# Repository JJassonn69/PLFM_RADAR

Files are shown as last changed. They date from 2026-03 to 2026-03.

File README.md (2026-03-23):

# AERIS-10: Open Source Pulse Linear Frequency Modulated Phased Array Radar




)


AERIS-10 Radar System

AERIS-10 is an open-source, low-cost 10.5 GHz phased array radar system featuring Pulse Linear Frequency Modulated (LFM) modulation. Available in two versions (3km and 20km range), it's designed for researchers, drone developers, and serious SDR enthusiasts who want to explore and experiment with phased array radar technology.

AERIS-10 Radar System

## 📡 Overview

The AERIS-10 project aims to democratize radar technology by providing a fully open-source, modular, and hackable radar system. Whether you're a university researcher, a drone startup, or an advanced maker, AERIS-10 offers a platform for experimenting with beamforming, pulse compression, Doppler processing, and target tracking.

## 🔬 Key Features

- **Open Source Hardware & Software** - Complete schematics, PCB layouts, firmware, and software available
- **Dual Version Availability**:
  - **AERIS-10N (Nexus)**: 3km range with 8x16 patch antenna array
  - **AERIS-10E (Extended)**: 20km range with 32x16 dielectric-filled slotted waveguide array
- **Full Electronic Beam Steering** - ±45° electronic steering in elevation and azimuth
- **Advanced Signal Processing** - On-board FPGA handles pulse compression, Doppler FFT, MTI, and CFAR
- **Python GUI** - User-friendly interface with map integration
- **GPS/IMU Integration** - Real-time position and attitude correction
- **Modular Design** - Separate power management, frequency synthesis, and RF boards

## 🏗️ System Architecture

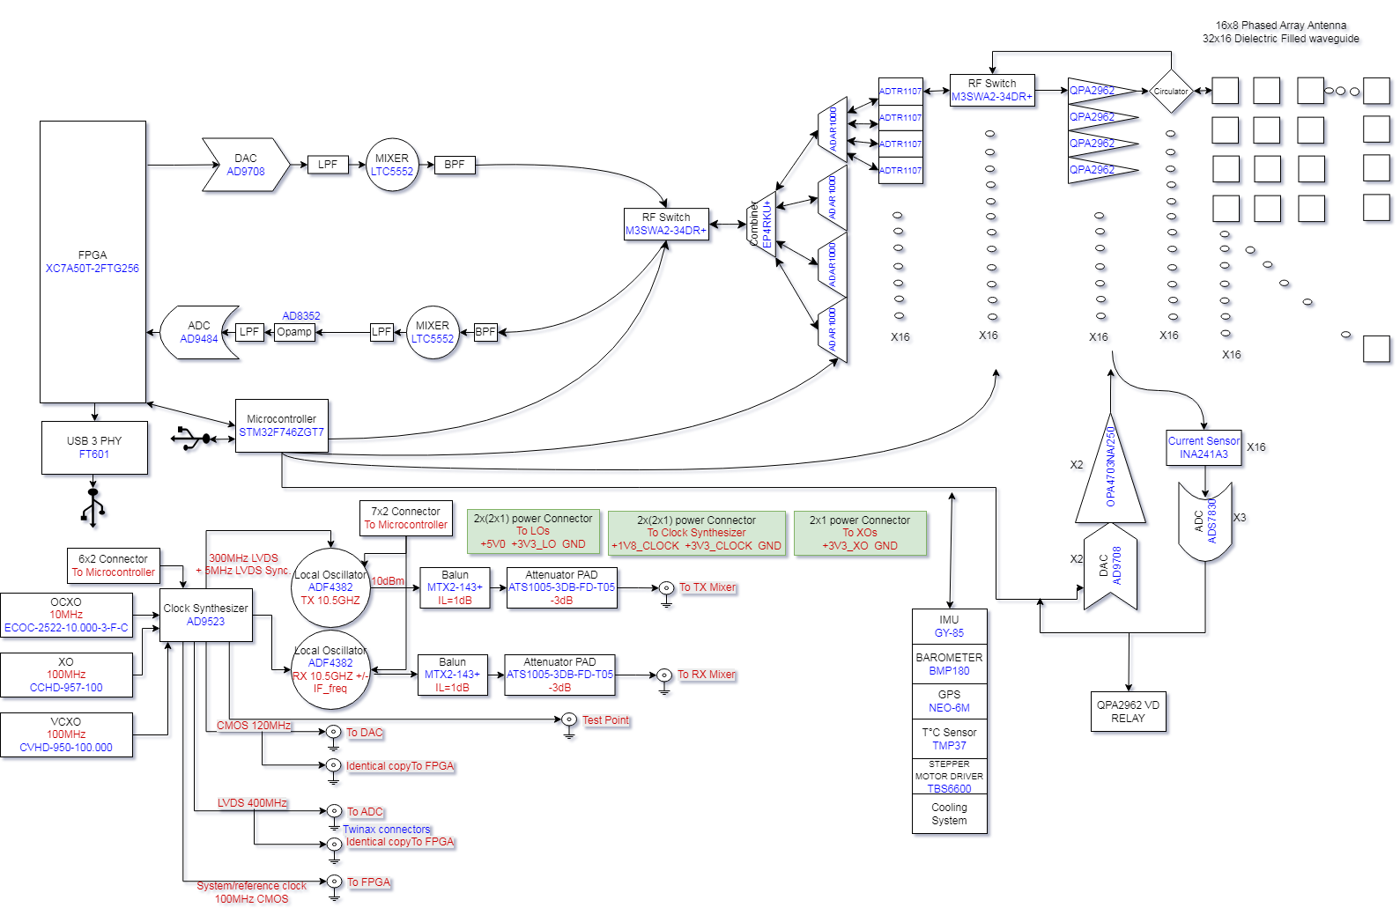
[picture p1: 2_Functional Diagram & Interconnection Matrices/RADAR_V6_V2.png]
AERIS-10 Radar System


### Hardware Components

The AERIS-10 main sub-systems are:

- **Power Management Board** - Supplies all necessary voltage levels to the electronics components with proper filtering and sequencing (sequencing ensured by the microcontroller)

- **Frequency Synthesizer Board** - Uses a high-performance Low Jitter Clock Generator (AD9523-1) that supplies phase-aligned clock references for:
  - RX and TX Frequency Synthesizers (ADF4382)
  - DAC
  - ADC
  - FPGA

- **Main Board** containing:
  - **DAC** - Generates the RADAR Chirps
  - **2x Microwave Mixers (LT5552)** - For up-conversion and IF-down-conversion
  - **4x 4-Channel Phase Shifters (ADAR1000)** - For RX and TX chain beamforming
  - **16x Front End Chips (ADTR1107)** - Used for both Low Noise Amplifying (RX) and Power Amplifying (TX) stages
  - **XC7A100T FPGA** - Handles RADAR Signal Processing:
    - PLFM Chirps generation via the DAC
    - Raw ADC data read
    - Automatic Gain Control (AGC)
    - I/Q Baseband Down-Conversion
    - Decimation
    - Filtering
    - Forward FFT
    - Pulse Compression
    - Doppler, MTI and CFAR processing
    - USB Interface
  - **STM32F746xx Microcontroller** - Used for:
    - Power-up and power-down sequencing (see Power Management Excel File)
    - FPGA communication
    - Setup and Interface with:
      - Clock Generator (AD9523-1)
      - 2x Frequency Synthesizers (ADF4382)
      - 4x 4-Channel Phase Shifters (ADAR1000) for RADAR pulse sequencing
      - 2x ADS7830 ADCs (on Power Amplifier Boards) for Idq measurement
      - 2x DAC5578 (on Power Amplifier Boards) for Vg control
      - GPS module for GUI map centering
      - GY-85 IMU for pitch/roll correction of target coordinates
      - BMP180 Barometer
      - Stepper Motor
      - 8x ADS7830 Temperature Sensors for cooling fan control
      - RF switches

- **16x Power Amplifier Boards** - Used only for AERIS-10E version, featuring 10Watt QPA2962 GaN amplifier for extended range

- **Antenna Arrays**:
  - **AERIS-10N (Nexus)** - 8x16 patch antenna array
  - **AERIS-10X (Extended)** - 32x16 dielectric-filled slotted waveguide antenna array

- **Miscellaneous Components**:
  - Slip-Ring
  - Stepper Motor and drivers
  - Cooling Fans
  - Enclosure) 

### Processing Pipeline

1. **Waveform Generation** - DAC creates LFM chirps
2. **Up/Down Conversion** - LT5552 mixers handle frequency translation
3. **Beam Steering** - ADAR1000 phase shifters control 16 elements
4. **Signal Processing (FPGA)**:
   - Raw ADC data capture
   - I/Q baseband down-conversion
   - Decimation & filtering (CIC/FIR)
   - Pulse compression
   - Doppler FFT processing
   - MTI & CFAR detection
5. **System Management (STM32)**:
   - Power sequencing
   - Peripheral configuration
   - GPS/IMU integration
   - Stepper motor control
6. **Visualization (Python GUI)**:
   - Real-time target plotting
   - Map integration
   - Radar control interface

AERIS-10 Radar System

## 📊 Technical Specifications

| Parameter | AERIS-10N (Nexus) | AERIS-10X (Extended) |
|---|---|---|
| **Frequency** | 10.5 GHz | 10.5 GHz |
| **Max Range** | 3 km | 20 km |
| **Antenna** | 8x16 Patch Array | 32x16 Slotted Waveguide |
| **Beam Steering** | Electronic (±45°) | Electronic (±45°) |
| **Mechanical Scan** | 360° (stepper motor) | 360° (stepper motor) |
| **Output Power** | ~1Wx16 | 10Wx16 (GaN amplifier) |
| **Processing** | FPGA + STM32 | FPGA + STM32 |

## 🚀 Getting Started

## 🧹 Repository File Placement Policy

To keep the repository root clean and make artifacts easy to find, place generated files in the following locations:

- **Published reports (tracked, GitHub Pages):** `docs/`
  - Example: `docs/AERIS_Simulation_Report_v2.pdf`
- **Simulation-generated outputs (local, gitignored):** `5_Simulations/generated/`
  - Plots, scenario outputs, temporary analysis directories
- **FPGA/Vivado generated artifacts (local, gitignored):** `9_Firmware/9_2_FPGA/reports/`
  - VCD/VVP dumps, temporary CSVs, local report snapshots
- **Reusable FPGA automation scripts (tracked):** `9_Firmware/9_2_FPGA/scripts/`
  - TCL flows, helper scripts used by build/bring-up

Do not leave generated artifacts in the repository root.

### Prerequisites

- Basic understanding of radar principles
- Experience with PCB assembly (for hardware build)
- Python 3.8+ for the GUI software
- FPGA development tools (Vivado) for signal processing modifications

### Hardware Assembly

1. **Order PCBs**: All Gerber files are available in `/4_Schematics and Boards Layout`
2. **Source Components**: Bill of materials (BOM) in `/4_Schematics and Boards Layout/4_7_Production Files`
3. **Assembly**: Follow the assembly guide in `/10_docs/assembly_guide.md`
4. **Antenna**: Choose appropriate array for your version
5. **Enclosure**: 3D printable files in `/10_docs/Hardware/Enclosure`

## 📜 License

This project is open-source but uses **different licenses for hardware and software** to ensure proper legal coverage.

### Hardware Documentation
The hardware design files—including:
- Schematics and PCB layouts (in `/4_Schematics and Boards Layout`)
- Bill of Materials (BOM) files
- Gerber files and manufacturing outputs
- Mechanical drawings and enclosure designs

are licensed under the **CERN Open Hardware Licence Version 2 – Permissive (CERN-OHL-P)** .

This is a hardware-specific license that:
- ✅ Clearly defines "Hardware," "Documentation," and "Products"
- ✅ Includes explicit patent protection for contributors and users
- ✅ Provides stronger liability limitations (important for high-power RF)
- ✅ Aligns with professional open-hardware standards (CERN, OSHWA)

You may use, modify, and sell products based on these designs, provided you:
- Maintain the original copyright notices
- Distribute any modified designs under the same license
- Make your modifications available in Source format

### Software and Firmware
The software components—including:
- FPGA code (VHDL/Verilog in `/9_Firmware`)
- Microcontroller firmware (STM32)
- Python GUI and utilities

remain under the **MIT License** for maximum flexibility.

### Full License Texts
- The complete CERN-OHL-P license text is in the `LICENSE` file
- MIT license terms apply to software where not otherwise specified

### Why This Change?
Originally, the entire project used the MIT license. The community (special thanks to gmaynez!) pointed out that MIT lacks legal protections needed for physical hardware. The switch to CERN-OHL-P ensures the project is properly protected while maintaining the same permissive spirit.

## Contact & Collaboration
I welcome serious inquiries from researchers, engineers, and potential collaborators. However, due to the high volume of interest in this project, please understand that I cannot guarantee a response to every message.

For technical questions or bug reports: Please open a GitHub issue so the whole community can benefit from the discussion.

For collaboration, licensing, or business inquiries:
📧 nawfal.motii.33 [at] gmail [dot] com

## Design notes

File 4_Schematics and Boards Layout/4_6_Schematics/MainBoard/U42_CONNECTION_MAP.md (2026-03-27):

# U42 FPGA Connection Map — XC7A200T-2FBG484I

> **MainBoard FPGA swap reference**
> Schematic: `RADAR_Main_Board_2.kicad_sch` (Digital sheet)
> PCB: `RADAR_Main_Board.kicad_pcb`

---

## STATUS SUMMARY

| Category | Count | Status |
|---|---|---|
| Signal nets (I/O) | 77 | All connected in schematic via wire+label |
| Power pins (VCCINT/VCCBRAM/VCCAUX/VCCO/GND) | 143 | All connected in schematic via global_label |
| Unexpected extra nets found | 6 | Need review (see Section 6) |
| PCB traces routed | 0 of 77 | **All old traces deleted — needs full re-route** |

---

## 1. BANK 14 I/O — Unit 1 (27 signals)

Unit 1 is placed at schematic position **(200, 450)**. All pins exit to the **right** (pin angle 180°, meaning pin stub points left, wire goes right from symbol edge).

| # | Net Name | New Ball | Pin Function | Connects To | LVDS? |
|---|---|---|---|---|---|
| 1 | `ADC_D0_N` | V22 | IO_L3N_T0_DQS_EMCCLK_14 | U1 (AD9484) pin | N pair |
| 2 | `ADC_D0_P` | T21 | IO_L4P_T0_D04_14 | U1 (AD9484) pin | P pair |
| 3 | `ADC_D1_N` | R21 | IO_L2N_T0_D03_14 | U1 (AD9484) pin | N pair |
| 4 | `ADC_D1_P` | U22 | IO_L3P_T0_DQS_PUDC_B_14 | U1 (AD9484) pin | P pair |
| 5 | `ADC_D2_N` | R22 | IO_L1N_T0_D01_DIN_14 | U1 (AD9484) pin | N pair |
| 6 | `ADC_D2_P` | P21 | IO_L2P_T0_D02_14 | U1 (AD9484) pin | P pair |
| 7 | `ADC_D3_N` | T18 | IO_L20N_T3_A07_D23_14 | U1 (AD9484) pin | N pair |
| 8 | `ADC_D3_P` | N17 | IO_L21P_T3_DQS_14 | U1 (AD9484) pin | P pair |
| 9 | `ADC_D4_N` | R14 | IO_L19N_T3_A09_D25_VREF_14 | U1 (AD9484) pin | N pair |
| 10 | `ADC_D4_P` | R18 | IO_L20P_T3_A08_D24_14 | U1 (AD9484) pin | P pair |
| 11 | `ADC_D5_N` | V19 | IO_L14N_T2_SRCC_14 | U1 (AD9484) pin | N pair |
| 12 | `ADC_D5_P` | AA19 | IO_L15P_T2_DQS_RDWR_B_14 | U1 (AD9484) pin | P pair |
| 13 | `ADC_D6_N` | AB20 | IO_L15N_T2_DQS_DOUT_CSO_B_14 | U1 (AD9484) pin | N pair |
| 14 | `ADC_D6_P` | V17 | IO_L16P_T2_CSI_B_14 | U1 (AD9484) pin | P pair |
| 15 | `ADC_D7_P` | Y18 | IO_L13P_T2_MRCC_14 | U1 (AD9484) pin | single |
| 16 | `ADC_OR_N` | AB18 | IO_L17N_T2_A13_D29_14 | U1 (AD9484) overrange | N pair |
| 17 | `ADC_OR_P` | U17 | IO_L18P_T2_A12_D28_14 | U1 (AD9484) overrange | P pair |
| 18 | `ADC_PWRD` | Y19 | IO_L13N_T2_MRCC_14 | U1 (AD9484) power down | single |
| 19 | `FPGA_ADC_CLOCK_N` | N14 | IO_L23N_T3_A02_D18_14 | ADC data clock | N pair |
| 20 | `FPGA_ADC_CLOCK_P` | P16 | IO_L24P_T3_A01_D17_14 | ADC data clock | P pair |
| 21 | `FPGA_FLASH_DQ0` | U20 | IO_L11P_T1_SRCC_14 | U9 (MT25QL) DQ0 | single |
| 22 | `FPGA_FLASH_DQ1` | AB22 | IO_L10N_T1_D15_14 | U9 (MT25QL) DQ1 | single |
| 23 | `FPGA_FLASH_DQ2` | AB21 | IO_L10P_T1_D14_14 | U9 (MT25QL) DQ2 | single |
| 24 | `FPGA_FLASH_DQ3` | Y22 | IO_L9N_T1_DQS_D13_14 | U9 (MT25QL) DQ3 | single |
| 25 | `FPGA_FLASH_NCS` | T19 | IO_L6P_T0_FCS_B_14 | U9 (MT25QL) chip select | single |
| 26 | `FPGA_FLASH_NRST` | T20 | IO_L6N_T0_D08_VREF_14 | U9 (MT25QL) reset | single |
| 27 | `FPGA_PUDC_B` | Y21 | IO_L9P_T1_DQS_14 | Internal pull-up control | single |

### Bank 14 Power: `+3V3_FPGA` (VCCO_14)
| Ball | Function |
|---|---|
| M14 | VCCO_14 |
| P18 | VCCO_14 |
| R15 | VCCO_14 |
| T22 | VCCO_14 |
| U19 | VCCO_14 |
| Y20 | VCCO_14 |

### Bank 13 Power: `+3V3_FPGA` (VCCO_13) — also in Unit 1
| Ball | Function |
|---|---|
| AA17 | VCCO_13 |
| AB14 | VCCO_13 |
| V16 | VCCO_13 |
| W13 | VCCO_13 |
| Y10 | VCCO_13 |

---

## 2. BANK 15/16 I/O — Unit 2 (28 signals)

Unit 2 is placed at schematic position **(380, 450)**. All pins exit to the **left** (pin angle 0°, pin stub points right, wire goes left from symbol edge).

| # | Net Name | New Ball | Pin Function | Connects To | Type |
|---|---|---|---|---|---|
| 1 | `ADAR_1_CS_3V3` | M22 | IO_L15N_T2_DQS_ADV_B_15 | ADAR1_0 chip select (3V3 domain) | single |
| 2 | `ADAR_2_CS_3V3` | N22 | IO_L15P_T2_DQS_15 | ADAR2_0 chip select (3V3 domain) | single |
| 3 | `ADAR_3_CS_3V3` | L20 | IO_L14N_T2_SRCC_15 | ADAR3_0 chip select (3V3 domain) | single |
| 4 | `ADAR_4_CS_3V3` | L19 | IO_L14P_T2_SRCC_15 | ADAR4_0 chip select (3V3 domain) | single |
| 5 | `DAC_0` | G18 | IO_L4N_T0_15 | U3 (AD9708) D0 | single |
| 6 | `DAC_1` | J15 | IO_L5P_T0_AD9P_15 | U3 (AD9708) D1 | single |
| 7 | `DAC_2` | H18 | IO_L6N_T0_VREF_15 | U3 (AD9708) D2 | single |
| 8 | `DAC_3` | H22 | IO_L7N_T1_AD2N_15 | U3 (AD9708) D3 | single |
| 9 | `DAC_4` | H20 | IO_L8P_T1_AD10P_15 | U3 (AD9708) D4 | single |
| 10 | `DAC_5` | G20 | IO_L8N_T1_AD10N_15 | U3 (AD9708) D5 | single |
| 11 | `DAC_6` | K22 | IO_L9N_T1_DQS_AD3N_15 | U3 (AD9708) D6 | single |
| 12 | `DAC_7` | M21 | IO_L10P_T1_AD11P_15 | U3 (AD9708) D7 | single |
| 13 | `DAC_SLEEP` | G16 | IO_L2N_T0_AD8N_15 | U3 (AD9708) sleep | single |
| 14 | `DIG_0` | L13 | IO_L20N_T3_A19_15 | General purpose digital I/O | single |
| 15 | `DIG_1` | M13 | IO_L20P_T3_A20_15 | General purpose digital I/O | single |
| 16 | `DIG_2` | K14 | IO_L19N_T3_A21_VREF_15 | General purpose digital I/O | single |
| 17 | `DIG_3` | K13 | IO_L19P_T3_A22_15 | General purpose digital I/O | single |
| 18 | `DIG_4` | M20 | IO_L18N_T2_A23_15 | General purpose digital I/O | single |
| 19 | `DIG_5` | N20 | IO_L18P_T2_A24_15 | General purpose digital I/O | single |
| 20 | `DIG_6` | N19 | IO_L17N_T2_A25_15 | General purpose digital I/O | single |
| 21 | `DIG_7` | N18 | IO_L17P_T2_A26_15 | General purpose digital I/O | single |
| 22 | `FPGA_CLOCK_TEST` | K18 | IO_L13P_T2_MRCC_15 | Clock test point | single |
| 23 | `FPGA_SYS_CLOCK` | M15 | IO_L24P_T3_RS1_15 | System clock input | single |
| 24 | `MIX_RX_EN` | L15 | IO_L22N_T3_A16_15 | Mixer RX enable | single |
| 25 | `MIX_TX_EN` | H13 | IO_L1P_T0_AD0P_15 | Mixer TX enable | single |
| 26 | `STM32_MISO1` | M18 | IO_L16P_T2_A28_15 | U2 (STM32) SPI MISO (3V3 domain) | single |
| 27 | `STM32_MOSI1` | L18 | IO_L16N_T2_A27_15 | U2 (STM32) SPI MOSI (3V3 domain) | single |
| 28 | `STM32_SCLK1` | K19 | IO_L13N_T2_MRCC_15 | U2 (STM32) SPI clock (3V3 domain) | single |

### Bank 15 Power: `+3V3_FPGA` (VCCO_15)
| Ball | Function |
|---|---|
| G19 | VCCO_15 |
| H16 | VCCO_15 |
| J13 | VCCO_15 |
| K20 | VCCO_15 |
| L17 | VCCO_15 |
| N21 | VCCO_15 |

### Bank 16 Power: `+3V3_FPGA` (VCCO_16)
| Ball | Function |
|---|---|
| A17 | VCCO_16 |
| B14 | VCCO_16 |
| C21 | VCCO_16 |
| D18 | VCCO_16 |
| E15 | VCCO_16 |
| F22 | VCCO_16 |

---

## 3. BANK 34/35 I/O — Unit 3 (22 signals)

Unit 3 is placed at schematic position **(560, 450)**. All pins exit to the **left** (pin angle 0°).

| # | Net Name | New Ball | Pin Function | Connects To | Type |
|---|---|---|---|---|---|
| 1 | `ADAR_1_CS_1V8` | Y2 | IO_L4N_T0_34 | ADAR1_0 chip select (1V8 domain) | single |
| 2 | `ADAR_2_CS_1V8` | W2 | IO_L4P_T0_34 | ADAR2_0 chip select (1V8 domain) | single |
| 3 | `ADAR_3_CS_1V8` | R2 | IO_L3N_T0_DQS_34 | ADAR3_0 chip select (1V8 domain) | single |
| 4 | `ADAR_4_CS_1V8` | R3 | IO_L3P_T0_DQS_34 | ADAR4_0 chip select (1V8 domain) | single |
| 5 | `ADAR_RX_LOAD_1` | AA5 | IO_L10P_T1_34 | ADAR1_0 RX load | single |
| 6 | `ADAR_RX_LOAD_2` | AB1 | IO_L7N_T1_34 | ADAR2_0 RX load | single |
| 7 | `ADAR_RX_LOAD_3` | AB2 | IO_L8N_T1_34 | ADAR3_0 RX load | single |
| 8 | `ADAR_RX_LOAD_4` | AA3 | IO_L9N_T1_DQS_34 | ADAR4_0 RX load | single |
| 9 | `ADAR_TR_1` | U1 | IO_L1N_T0_34 | ADAR1_0 T/R switch | single |
| 10 | `ADAR_TR_2` | T1 | IO_L1P_T0_34 | ADAR2_0 T/R switch | single |
| 11 | `ADAR_TR_3` | T3 | IO_0_34 | ADAR3_0 T/R switch | single |
| 12 | `ADAR_TX_LOAD_2` | AA1 | IO_L7P_T1_34 | ADAR2_0 TX load | single |
| 13 | `ADAR_TX_LOAD_3` | AB3 | IO_L8P_T1_34 | ADAR3_0 TX load | single |
| 14 | `ADAR_TX_LOAD_4` | Y3 | IO_L9P_T1_DQS_34 | ADAR4_0 TX load | single |
| 15 | `STM32_MISO_1V8` | U2 | IO_L2P_T0_34 | U2 (STM32) SPI MISO (1V8 domain) | single |
| 16 | `STM32_MOSI_1V8` | V2 | IO_L2N_T0_34 | U2 (STM32) SPI MOSI (1V8 domain) | single |
| 17 | `STM32_SCLK_1V8` | U3 | IO_L6P_T0_34 | U2 (STM32) SPI clock (1V8 domain) | single |
| 18 | `FPGA_FLASH_CLK` | *see Unit 6* | *shared net — label only here* | U9 (MT25QL) SPI clock | single |
| 19 | `FPGA_FLASH_DQ0` | *see Unit 1* | *shared net — label only here* | U9 (MT25QL) DQ0 | single |
| 20 | `FPGA_FLASH_DQ1` | *see Unit 1* | *shared net — label only here* | U9 (MT25QL) DQ1 | single |
| 21 | `FPGA_FLASH_NCS` | *see Unit 1* | *shared net — label only here* | U9 (MT25QL) chip select | single |
| 22 | `FPGA_FLASH_NRST` | *see Unit 1* | *shared net — label only here* | U9 (MT25QL) reset | single |

> **Note:** Items 18-22 are labels present near Unit 3 that share net names with Unit 1/Unit 6 pins. The actual FPGA ball for these signals is assigned via Unit 1 (for DQ0-3, NCS, NRST) and Unit 6 (for CLK). These labels likely connect to the flash IC nearby.

### Bank 34 Power: `+1V8_FPGA` (VCCO_34)
| Ball | Function |
|---|---|
| AA7 | VCCO_34 |
| AB4 | VCCO_34 |
| R5 | VCCO_34 |
| T2 | VCCO_34 |
| V6 | VCCO_34 |
| W3 | VCCO_34 |

### Bank 35 Power: `+1V8_FPGA` (VCCO_35)
| Ball | Function |
|---|---|
| C1 | VCCO_35 |
| F2 | VCCO_35 |
| H6 | VCCO_35 |
| J3 | VCCO_35 |
| M4 | VCCO_35 |
| N1 | VCCO_35 |

---

## 4. CONFIGURATION & JTAG — Unit 6 (5 signals)

Unit 6 is placed at schematic position **(90, 450)**. Pins exit to the **right** (pin angle 180°).

| # | Net Name | New Ball | Pin Function | Connects To | Type |
|---|---|---|---|---|---|
| 1 | `FPGA_FLASH_CLK` | L12 | CCLK_0 | U9 (MT25QL) SPI clock | dedicated |
| 2 | `FPGA_TCK` | V12 | TCK_0 | JTAG test clock | dedicated |
| 3 | `FPGA_TDI` | R13 | TDI_0 | JTAG test data in | dedicated |
| 4 | `FPGA_TDO` | U13 | TDO_0 | JTAG test data out | dedicated |
| 5 | `FPGA_TMS` | T13 | TMS_0 | JTAG test mode select | dedicated |

> **CRITICAL**: Do NOT use FT_PROG on the FT2232HQ EEPROM — will permanently break JTAG.

### Bank 0 Power: `+1V8_FPGA` (VCCO_0) — in Unit 6
| Ball | Function |
|---|---|
| F12 | VCCO_0 |
| T12 | VCCO_0 |

### Other Unit 6 dedicated pins (no signal net, but need power/config wiring)

> **NOTE**: These balls were corrected on 2026-03-26. The original table had OLD XC7A50T
> ball numbers paired with correct function names. The table below uses the correct
> XC7A200T-FBG484 ball assignments (verified against KiCad symbol and Xilinx pinout file).

| Ball | Function | Old XC7A50T Ball | Required Connection | How to Wire in KiCad |
|---|---|---|---|---|
| **U8** | **CFGBVS_0** | E7 | Tie to VCCO_0 (+1V8_FPGA) — tells FPGA that Bank 0/14/15 config I/O use 1.8V levels | Wire directly to +1V8_FPGA power rail (no resistor needed). Place a global_label `+1V8_FPGA` on the pin. |
| **G11** | **DONE_0** | H10 | Config done indicator. Directly connect to VCCO_0 through a 330R pull-up. Active-high when config is complete. Optional: route to an LED or STM32 GPIO for status monitoring. | Add a 330Ω resistor from this pin to +1V8_FPGA. In KiCad: wire pin → net label `FPGA_DONE`, then place a resistor symbol (R, 330Ω) between that net and a +1V8_FPGA power symbol. |
| **U12** | **INIT_B_0** | K10 | Active-low config error flag. Pull up to VCCO_0 through 4.7kΩ. Goes low if config CRC fails. Optional: route to STM32 GPIO. | Add a 4.7kΩ resistor from this pin to +1V8_FPGA. Same pattern as DONE_0 above. |
| **N12** | **PROGRAM_B_0** | L9 | Active-low config reset. Pull up to VCCO_0 through 4.7kΩ. Directly connect or route to a push-button that shorts to GND for manual re-programming. | Add a 4.7kΩ resistor from this pin to +1V8_FPGA. Optional: add a tactile switch to GND for manual reset. |
| **U11** | **M0_0** | M9 | Mode select bit 0. For Master SPI mode (to boot from flash U9): tie to **GND** | Wire to GND power symbol. |
| **U10** | **M1_0** | M10 | Mode select bit 1. For Master SPI mode: tie to **GND** | Wire to GND power symbol. |
| **U9** | **M2_0** | M11 | Mode select bit 2. For Master SPI mode: tie to **VCCO_0 (+1V8_FPGA)** via 4.7kΩ pull-up | Add a 4.7kΩ resistor from this pin to +1V8_FPGA. |
| **L9** | **VREFN_0** | H7 | XADC negative reference. If XADC not used: tie to **GND** through a 0Ω/short or leave connected to GND plane. If XADC used: connect to external 1.25V reference negative. | Wire to GND power symbol (XADC not used in this design). |
| **L10** | **VP_0** | H8 | XADC positive analog input. If XADC not used: leave unconnected (has internal pull-down) or tie to GND through 100Ω. | Leave unconnected or add 100Ω to GND. Mark with no-connect flag (X) in KiCad if leaving open. |
| **M9** | **VN_0** | J7 | XADC negative analog input. If XADC not used: leave unconnected or tie to GND through 100Ω. | Same as VP_0 — leave unconnected or 100Ω to GND. |
| **M10** | **VREFP_0** | J8 | XADC positive reference. If XADC not used: tie to **VCCADC** (+1V8_FPGA) through 100Ω, or leave unconnected. | Wire 100Ω to +1V8_FPGA, or mark no-connect. |
| **N9** | **DXN_0** | K7 | Thermal diode negative. If not monitoring die temperature externally: leave unconnected. | Place no-connect flag (X) on pin in KiCad. |
| **N10** | **DXP_0** | K8 | Thermal diode positive. If not monitoring die temperature externally: leave unconnected. | Place no-connect flag (X) on pin in KiCad. |

#### Mode Select Truth Table (M[2:1:0])

| M2 | M1 | M0 | Mode | Use Case |
|---|---|---|---|---|
| 0 | 0 | 0 | Master Serial | — |
| 0 | 0 | 1 | **Master SPI** | **Boot from flash U9 (MT25QL) — USE THIS** |
| 0 | 1 | 0 | Master BPI (x8) | — |
| 0 | 1 | 1 | Master BPI (x16) | — |
| 1 | 0 | 0 | Master Serial | — |
| 1 | 0 | 1 | JTAG only | Debug/development |
| 1 | 1 | 0 | Slave SelectMAP | — |
| 1 | 1 | 1 | Slave Serial | — |

> **For Master SPI boot from U9**: M2=0, M1=0, M0=1 → **M2=GND, M1=GND, M0=VCCO** (pull-up to +1V8_FPGA)
>
> Alternatively, during development you may want JTAG-only mode (M2=1, M1=0, M0=1 → M2=VCCO, M1=GND, M0=VCCO).
> Consider using 4.7kΩ pull-up/pull-down resistors instead of direct ties so mode pins can be overridden with jumpers.

#### How to Wire Pull-Up/Pull-Down Resistors in KiCad Schematic

**General pattern for a pull-up resistor:**
1. From the FPGA dedicated pin, draw a short wire stub (e.g., 2.54mm / 1 grid unit)
2. Place a resistor symbol (`Device:R`) on that wire stub, oriented vertically
3. Set the resistor value in properties (e.g., `4.7k`, `330`, `100`)
4. Set a reference designator (KiCad will auto-assign, e.g., R_NEW1)
5. From the other end of the resistor, draw a wire stub and attach a **power symbol**:
   - For pull-up to 1.8V: use `+1V8_FPGA` global power label (or the power symbol from your library)
   - For pull-down to GND: use `GND` power symbol
6. The resistor does NOT need a footprint assigned yet — you can assign during annotation/footprint assignment. Use 0402 or 0603 SMD footprint.

**For direct ties (no resistor):**
1. Wire directly from the FPGA pin to the power symbol (e.g., CFGBVS_0 → +1V8_FPGA)

**For no-connect pins:**
1. Select the "Place No Connect Flag" tool (shortcut: `Q` in KiCad 10)
2. Click on the pin endpoint to place an X mark
3. This tells ERC that the pin is intentionally unconnected

#### Resistor Value Summary for Config Pins

| Pin | Resistor | To | Value | Purpose |
|---|---|---|---|---|
| CFGBVS_0 (U8) | none (direct tie) | +1V8_FPGA | — | Sets config voltage level |
| DONE_0 (G11) | R_pull-up | +1V8_FPGA | 330Ω | Config done indicator |
| INIT_B_0 (U12) | R_pull-up | +1V8_FPGA | 4.7kΩ | Config error flag |
| PROGRAM_B_0 (N12) | R_pull-up | +1V8_FPGA | 4.7kΩ | Config reset (active-low) |
| M0_0 (U11) | R_pull-up | +1V8_FPGA | 4.7kΩ | Mode = 1 (Master SPI) |
| M1_0 (U10) | R_pull-down | GND | 4.7kΩ | Mode = 0 |
| M2_0 (U9) | R_pull-down | GND | 4.7kΩ | Mode = 0 |
| VREFN_0 (L9) | none (direct tie) | GND | — | XADC not used |
| VREFP_0 (M10) | 100Ω | +1V8_FPGA | 100Ω | XADC ref (or no-connect) |
| VP_0 (L10) | no-connect or 100Ω | GND | 100Ω | XADC not used |
| VN_0 (M9) | no-connect or 100Ω | GND | 100Ω | XADC not used |
| DXN_0 (N9) | no-connect | — | — | Thermal diode not used |
| DXP_0 (N10) | no-connect | — | — | Thermal diode not used |

---

## 5. POWER & GROUND — Unit 7 (112 pins)

Unit 7 is placed at schematic position **(90, 300)**. Power pins exit **left** (offset -25.4) and **right** (offset +25.4).

### +1V0_FPGA — VCCINT (14 balls)
| Ball | Side |
|---|---|
| H8 | right |
| H10 | right |
| J7 | right |
| J9 | right |
| K8 | right |
| L7 | right |
| M8 | right |
| N7 | right |
| P8 | right |
| P10 | right |
| R7 | right |
| R9 | right |
| T8 | right |
| T10 | right |

### +1V0_FPGA — VCCBRAM (3 balls)
| Ball | Side |
|---|---|
| J11 | left |
| L11 | left |
| N11 | left |

### +1V8_FPGA — VCCAUX (5 balls)
| Ball | Side |
|---|---|
| H12 | left |
| K12 | left |
| M12 | left |
| P12 | left |
| R11 | left |

### +1V8_FPGA — VCCADC (1 ball)
| Ball |
|---|
| K10 |

### +1V8_FPGA — VCCBATT (1 ball)
| Ball |
|---|
| E12 |

### GND (88 balls)

**Left-side GND pins (48 balls):**
A2, A3, A5, A7, A9, A11, A12, A22, B3, B12, B19, C3, C6, C10, C12, C16, D3, D4, D8, D12, D13, E4, E5, E7, E9, E11, E20, F5, F11, F17, G5, G6, G7, G8, G9, G10, G12, G14, H1, H7, H9, H11, H21, J8, K9 (GNDADC)

**Right-side GND pins (40 balls):**
J10, J12, J18, K5, K7, K11, K15, L2, L8, L22, M7, M11, M19, N6, N8, N16, P3, P7, P9, P11, P13, R8, R10, R12, R20, T7, T9, T11, T17, U4, U14, V1, V11, V21, W8, W18, Y5, Y15, AA2, AA12, AA22, AB9, AB19

---

## 6. UNEXPECTED NETS (need review)

The audit found 6 nets connected near U42 that are **not in the original 77-signal migration map**:

| Net Name | Label Type | Near Unit | Action Needed |
|---|---|---|---|
| `ADAR_TR_4` | global_label | Unit 3 | **Missing from migration map** — was this on the old FPGA? |
| `ADAR_TX_LOAD_1` | global_label | Unit 3 | **Missing from migration map** — was this on the old FPGA? |
| `ADC_DCO_N` | global_label | Unit 1 & 6 | ADC data clock output (negative) — may be alternate name for ADC clock |
| `ADC_DCO_P` | global_label | Unit 1 & 6 | ADC data clock output (positive) — may be alternate name for ADC clock |
| `FPGA_DAC_CLOCK` | label | Unit 2 | DAC clock output — likely pre-existing from old design |
| `M3S_VCTRL` | global_label | Unit 2 | VCO control voltage — likely pre-existing from old design |

> These may be pre-existing connections from the old XC7A50T design that weren't in the migration map, or they could be artifacts. Check if these nets need FPGA ball assignments or should be removed.

---

## 7. PCB RE-ROUTING CHECKLIST

All 77 signal traces were deleted from the PCB. They need to be re-routed from the new BGA484 pads to their destination components. The new footprint (`Xilinx_FBG484`) is placed at the same center position as the old BGA256.

### Priority 1 — High-speed LVDS (route as differential pairs, length-matched)
| Pair | Ball P | Ball N | Target |
|---|---|---|---|
| ADC_D0 | T21 | V22 | U1 (AD9484) |
| ADC_D1 | U22 | R21 | U1 |
| ADC_D2 | P21 | R22 | U1 |
| ADC_D3 | N17 | T18 | U1 |
| ADC_D4 | R18 | R14 | U1 |
| ADC_D5 | AA19 | V19 | U1 |
| ADC_D6 | V17 | AB20 | U1 |
| ADC_OR | U17 | AB18 | U1 |
| ADC_CLOCK | P16 | N14 | U1 |

### Priority 2 — SPI buses (matched length within bus)
| Bus | Signals | Balls | Target |
|---|---|---|---|
| STM32 SPI (3V3) | MISO1, MOSI1, SCLK1 | M18, L18, K19 | U2 (STM32) |
| STM32 SPI (1V8) | MISO, MOSI, SCLK | U2, V2, U3 | U2 (STM32) via level shifter |
| ADAR SPI CS (3V3) | CS_1-4 | M22, N22, L20, L19 | ADAR1000 x4 |
| ADAR SPI CS (1V8) | CS_1-4 | Y2, W2, R2, R3 | ADAR1000 x4 via level shifter |

### Priority 3 — DAC parallel bus
| Signal | Ball | Target |
|---|---|---|
| DAC_0 | G18 | U3 (AD9708) |
| DAC_1 | J15 | U3 |
| DAC_2 | H18 | U3 |
| DAC_3 | H22 | U3 |
| DAC_4 | H20 | U3 |
| DAC_5 | G20 | U3 |
| DAC_6 | K22 | U3 |
| DAC_7 | M21 | U3 |
| DAC_SLEEP | G16 | U3 |

### Priority 4 — Flash SPI
| Signal | Ball | Target |
|---|---|---|
| FLASH_CLK | L12 (CCLK) | U9 (MT25QL) |
| FLASH_DQ0 | U20 | U9 |
| FLASH_DQ1 | AB22 | U9 |
| FLASH_DQ2 | AB21 | U9 |
| FLASH_DQ3 | Y22 | U9 |
| FLASH_NCS | T19 | U9 |
| FLASH_NRST | T20 | U9 |

### Priority 5 — JTAG (keep short, avoid stubs)
| Signal | Ball | Target |
|---|---|---|
| TCK | V12 | FT2232HQ JTAG header |
| TDI | R13 | FT2232HQ |
| TDO | U13 | FT2232HQ |
| TMS | T13 | FT2232HQ |

### Priority 6 — Control signals
| Signal | Ball | Target |
|---|---|---|
| MIX_RX_EN | L15 | Mixer control |
| MIX_TX_EN | H13 | Mixer control |
| ADAR_TR_1 | U1 | ADAR T/R switch |
| ADAR_TR_2 | T1 | ADAR T/R switch |
| ADAR_TR_3 | T3 | ADAR T/R switch |
| ADAR_RX_LOAD_1-4 | AA5, AB1, AB2, AA3 | ADAR RX load |
| ADAR_TX_LOAD_2-4 | AA1, AB3, Y3 | ADAR TX load |
| ADC_PWRD | Y19 | ADC power down |
| FPGA_PUDC_B | Y21 | Internal pull-up during config |

### Priority 7 — Clock and digital I/O
| Signal | Ball | Target |
|---|---|---|
| FPGA_SYS_CLOCK | M15 | System clock oscillator |
| FPGA_CLOCK_TEST | K18 | Test point |
| DIG_0-7 | L13,M13,K14,K13,M20,N20,N19,N18 | GPIO header/test |

### Priority 8 — Power fanout vias (BGA escape routing)
Route power planes/vias from BGA pads to internal power layers:
- 14x VCCINT (1V0) + 3x VCCBRAM (1V0) balls to `+1V0_FPGA` plane
- 5x VCCAUX (1V8) + 1x VCCADC + 1x VCCBATT + 12x VCCO_34/35 + 2x VCCO_0 balls to `+1V8_FPGA` plane
- 11x VCCO_13/14 + 12x VCCO_15/16 balls to `+3V3_FPGA` plane
- 88x GND balls to GND plane

---

## 8. OLD-TO-NEW BALL CROSS-REFERENCE

For tracing where each signal moved from on the old XC7A50T (256-BGA) to the new XC7A200T (484-BGA):

| Net | Old Ball (XC7A50T) | New Ball (XC7A200T) | Same Function? |
|---|---|---|---|
| ADC_D0_N | M15 | V22 | Yes |
| ADC_D0_P | L14 | T21 | Yes |
| ADC_D1_N | K16 | R21 | Yes |
| ADC_D1_P | L15 | U22 | Yes |
| ADC_D2_N | J14 | R22 | Yes |
| ADC_D2_P | K15 | P21 | Yes |
| ADC_D3_N | R8 | T18 | Yes |
| ADC_D3_P | T7 | N17 | Yes |
| ADC_D4_N | N6 | R14 | Yes |
| ADC_D4_P | P8 | R18 | Yes |
| ADC_D5_N | P11 | V19 | Yes |
| ADC_D5_P | R12 | AA19 | Yes |
| ADC_D6_N | T12 | AB20 | Yes |
| ADC_D6_P | R13 | V17 | Yes |
| ADC_D7_P | N11 | Y18 | Yes |
| ADC_OR_N | R11 | AB18 | Yes |
| ADC_OR_P | N9 | U17 | Yes |
| ADC_PWRD | N12 | Y19 | Yes |
| FPGA_ADC_CLOCK_N | T5 | N14 | Yes |
| FPGA_ADC_CLOCK_P | R6 | P16 | Yes |
| FPGA_FLASH_DQ0 | N13 | U20 | Yes |
| FPGA_FLASH_DQ1 | T15 | AB22 | Yes |
| FPGA_FLASH_DQ2 | T14 | AB21 | Yes |
| FPGA_FLASH_DQ3 | R16 | Y22 | Yes |
| FPGA_FLASH_NCS | L12 | T19 | Yes |
| FPGA_FLASH_NRST | M12 | T20 | Yes |
| FPGA_PUDC_B | R15 | Y21 | Yes |
| ADAR_1_CS_3V3 | D15 | M22 | Yes |
| ADAR_2_CS_3V3 | D14 | N22 | Yes |
| ADAR_3_CS_3V3 | D11 | L20 | Yes |
| ADAR_4_CS_3V3 | D16 | L19 | Yes |
| DAC_0 | B11 | G18 | Yes |
| DAC_1 | B12 | J15 | Yes |
| DAC_2 | D9 | H18 | Yes |
| DAC_3 | A14 | H22 | Yes |
| DAC_4 | C14 | H20 | Yes |
| DAC_5 | B14 | G20 | Yes |
| DAC_6 | A15 | K22 | Yes |
| DAC_7 | C16 | M21 | Yes |
| DAC_SLEEP | A9 | G16 | Yes |
| DIG_0 | H13 | L13 | Yes |
| DIG_1 | H12 | M13 | Yes |
| DIG_2 | G12 | K14 | Yes |
| DIG_3 | H11 | K13 | Yes |
| DIG_4 | E15 | M20 | Yes |
| DIG_5 | F15 | N20 | Yes |
| DIG_6 | D16 | N19 | Yes |
| DIG_7 | E16 | N18 | Yes |
| FPGA_CLOCK_TEST | E12 | K18 | Yes |
| FPGA_SYS_CLOCK | H14 | M15 | Yes |
| MIX_RX_EN | G16 | L15 | Yes |
| MIX_TX_EN | C8 | H13 | Yes |
| STM32_MISO1 | F12 | M18 | Yes |
| STM32_MOSI1 | F13 | L18 | Yes |
| STM32_SCLK1 | E13 | K19 | Yes |
| ADAR_1_CS_1V8 | P1 | Y2 | Yes |
| ADAR_2_CS_1V8 | N1 | W2 | Yes |
| ADAR_3_CS_1V8 | N2 | R2 | Yes |
| ADAR_4_CS_1V8 | N3 | R3 | Yes |
| ADAR_RX_LOAD_1 | P5 | AA5 | Yes |
| ADAR_RX_LOAD_2 | R1 | AB1 | Yes |
| ADAR_RX_LOAD_3 | T2 | AB2 | Yes |
| ADAR_RX_LOAD_4 | T3 | AA3 | Yes |
| ADAR_TR_1 | M4 | U1 | Yes |
| ADAR_TR_2 | L4 | T1 | Yes |
| ADAR_TR_3 | L5 | T3 | Yes |
| ADAR_TX_LOAD_2 | R2 | AA1 | Yes |
| ADAR_TX_LOAD_3 | R3 | AB3 | Yes |
| ADAR_TX_LOAD_4 | T4 | Y3 | Yes |
| STM32_MISO_1V8 | M2 | U2 | Yes |
| STM32_MOSI_1V8 | M1 | V2 | Yes |
| STM32_SCLK_1V8 | M5 | U3 | Yes |
| FPGA_FLASH_CLK | E8 | L12 | Yes |
| FPGA_TCK | L7 | V12 | Yes |
| FPGA_TDI | N7 | R13 | Yes |
| FPGA_TDO | N8 | U13 | Yes |
| FPGA_TMS | M7 | T13 | Yes |

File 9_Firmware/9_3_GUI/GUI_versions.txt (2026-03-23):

GUI_V1 ==> 
GUI_V2 ==> added STM32 USB CDC
GUI_V3 ==> added Pitch to STM32 USB Packet and pitch correction to the Elevation 
GUI_V3 ==> Added Google_Map, real time target plot, Chirp duration_2
GUI_V4 ==> Added pitch correction

GUI_V5 ==> Added Mercury Color

GUI_V6 ==> Added USB3 FT601 support

radar_dashboard ==> Board bring-up dashboard (FT601 reader, real-time R-D heatmap, CFAR overlay, waterfall, host commands, HDF5 recording)
radar_protocol ==> Protocol layer (packet parsing, command building, FT601 connection, data recorder, acquisition thread)
smoke_test ==> Board bring-up smoke test host script (triggers FPGA self-test via opcode 0x30)

GUI_radar_dashboard_v2 ==> Unified V2 dashboard merging best features from all legacy GUIs:
  - From V2-V6: Kalman filter tracking (DBSCAN clustering + 4-state KF, numpy-only)
  - From V3-V6: GPS/IMU pitch correction on elevation angles
  - From V4-V6: Google Maps HTML overlay with target plotting
  - From V2-V6: Multi-PRF velocity unwrapping (Chinese Remainder Theorem)
  - From V5: Settings validation (firmware-mirrored range checks)
  - From V4_2_CSV: CSV offline analysis (host-side range FFT, Doppler FFT, MTI, CFAR)
  - From radar_dashboard: FT601 pipeline, R-D heatmap, CFAR overlay, waterfall, host commands, HDF5 recording
  - New: Targets tab with track list, tracked target overlay on R-D map (orange circles)
  - 6 tabs: Display, Targets, Map, Control, CSV Analysis, Log
test_radar_dashboard_v2 ==> 47 unit tests for V2 new features (settings validation, multi-PRF, pitch correction, tracker, maps, CSV processor)

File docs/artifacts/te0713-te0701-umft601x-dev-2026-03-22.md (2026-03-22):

# AERIS-10 FT601 Integration Dev Bitstream (v0.1.9 — timing fix + self-test)

**File:** `te0713-te0701-umft601x-dev-2026-03-22.bit`  
**Tag:** `v0.1.9-timing-fix`  
**Commit:** `92f4242`  
**Date:** 2026-03-22  
**Target:** XC7A200T-2FBG484C (TE0713-03) on TE0701-06 carrier + UMFT601X-B FMC LPC

## Build Summary

| Metric | Value |
|---|---|
| WNS (setup) | +0.349 ns |
| WHS (hold) | +0.121 ns |
| WPWS (pulse width) | +4.500 ns |
| Intra-clock WNS | +1.081 ns |
| Failing endpoints | 0 |
| DRC errors | 0 |
| Clock | ft601_clk_in 100 MHz (10 ns period) |
| Strategy | Performance_ExplorePostRoutePhysOpt |
| Vivado | 2025.2 |
| LUTs | 146 |
| FFs | 327 |

## Changes vs v0.1.8

| Metric | v0.1.8 | v0.1.9 | Delta |
|---|---|---|---|
| WNS (setup) | +0.059 ns | +0.349 ns | **+0.290 ns (5.9×)** |
| Intra-clock WNS | +0.059 ns | +1.081 ns | **+1.022 ns (18.3×)** |
| Self-test | Hardwired 5'b11111 | Real fpga_self_test.v FSM | Functional |
| LUTs | 146 | 146 | 0 |
| FFs | 325 | 327 | +2 |

### Timing fix
- Registered `ft601_txe` and `ft601_rxf` inputs in `usb_data_interface.v`
- IOB TRUE constraints pack input registers into ILOGIC sites
- Eliminates all top-10 critical paths from unregistered input pads

### Self-test integration
- `fpga_self_test.v` instantiated in dev wrapper (was hardwired in v0.1.8)
- Opcode 0x30 triggers 5-subsystem self-test FSM
- Opcode 0x31 reads latched results via status mechanism
- Tests 0-3 (BRAM, CIC, FFT, MTI arithmetic) run on real hardware
- Test 4 (ADC capture) will timeout on dev board (ADC inputs tied to 0)

## What This Bitstream Does

- Instantiates `usb_data_interface.v` (full FT601 USB data path) and
  `fpga_self_test.v` (5-subsystem self-test) via dev wrapper
- Generates synthetic test data: range profile packets (counter XOR pattern),
  optional Doppler and CFAR packets, controlled by host commands
- Responds to USB host commands (stream control 0x04, self-test 0x30/0x31, status 0xFF)
- Drives `ft601_gpio0` with a ~6 Hz heartbeat (counter bit 24)
- Drives `ft601_chip_reset_n` after power-on reset (32k clock cycles)
- `ft601_wakeup_n` held high (inactive)

## Hardware Setup

1. TE0713-03 mounted on TE0701-06 carrier
2. UMFT601X-B plugged into TE0701 J10 (FMC LPC connector)
3. TE0701 VIOTB = 3.3V (jumper configuration)
4. UMFT601X-B jumpers: JP1=open, JP2=2-3, JP3=open, JP6=short (3.3V),
   JP4=2-3, JP5=2-3 (245 Sync FIFO mode)
5. USB 3.0 Micro-B cable from UMFT601X-B to host PC
6. Trenz programming USB for JTAG

## Programming

```
# Open Vivado Hardware Manager
open_hw_manager
connect_hw_server
open_hw_target
set_property PROGRAM.FILE {te0713-te0701-umft601x-dev-2026-03-22.bit} [current_hw_device]
program_hw_devices [current_hw_device]
```

## Verification Steps

1. After programming, check `ft601_gpio0` toggles (~6 Hz) — confirms FPGA running
2. On host PC, FT601 should enumerate as USB 3.0 device (VID 0x0403, PID 0x601F)
3. Run host-side smoke test:
   ```
   cd 9_Firmware/9_3_GUI
   python smoke_test.py --live
   ```
   Expected: Tests 0-3 PASS, Test 4 FAIL (no ADC on dev board)
4. Use dashboard for live data:
   ```
   python radar_dashboard.py --live
   ```

## Source Files

- `9_Firmware/9_2_FPGA/radar_system_top_te0713_umft601x_dev.v` — wrapper top
- `9_Firmware/9_2_FPGA/usb_data_interface.v` — FT601 USB data interface
- `9_Firmware/9_2_FPGA/fpga_self_test.v` — 5-subsystem self-test controller
- `9_Firmware/9_2_FPGA/constraints/te0713_te0701_umft601x.xdc` — FMC LPC constraints
- `9_Firmware/9_2_FPGA/scripts/build_te0713_umft601x_dev.tcl` — build script

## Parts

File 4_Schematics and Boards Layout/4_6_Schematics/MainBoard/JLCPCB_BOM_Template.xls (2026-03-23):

Comment | Designator | Footprint | JLCPCB Part#(optional)
100uF | C1 | CASE-B_3528 | C16133
100nF | C2, C9, C10 | 0603 | C14663
300KΩ | R4, R7 | 0603 | C23024
15KΩ | R5, R6 | 0603_R | C22809
100KΩ | R1, R3 | 0603_R | C25803
10uF | C3-5 | 1206_C | C13585
100Ω | R2 | 0603_R | C22775
1N4148WS | D1 | SOD-323 | C2128
LM358DR2G | U1 | SOIC-8_150mil | C7950
HT7550-1 | VR1 | SOT-89(SOT-89-3) | C16106

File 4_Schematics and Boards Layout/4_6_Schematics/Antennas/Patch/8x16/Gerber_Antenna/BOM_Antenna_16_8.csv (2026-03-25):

Part | Value | Device | Package | Description | DATASHEET-URL | GENDER | INTERFACE | MOUNT | ORIENTATION-TYPE | PART-NUMBER | VALUE | Z
J1 | 60124102122403 | 60124102122403 | 60124102122403 | WR-SMP Straight | https://www.we-online.com/catalog/datasheet/60124102122403.pdf | Plug | MIL-STD-348 | SMT | Straight | 60124102122403 | 60124102122403 | 50Ohm
J2 | 60124102122403 | 60124102122403 | 60124102122403 | WR-SMP Straight | https://www.we-online.com/catalog/datasheet/60124102122403.pdf | Plug | MIL-STD-348 | SMT | Straight | 60124102122403 | 60124102122403 | 50Ohm
J3 | 60124102122403 | 60124102122403 | 60124102122403 | WR-SMP Straight | https://www.we-online.com/catalog/datasheet/60124102122403.pdf | Plug | MIL-STD-348 | SMT | Straight | 60124102122403 | 60124102122403 | 50Ohm
J4 | 60124102122403 | 60124102122403 | 60124102122403 | WR-SMP Straight | https://www.we-online.com/catalog/datasheet/60124102122403.pdf | Plug | MIL-STD-348 | SMT | Straight | 60124102122403 | 60124102122403 | 50Ohm
J5 | 60124102122403 | 60124102122403 | 60124102122403 | WR-SMP Straight | https://www.we-online.com/catalog/datasheet/60124102122403.pdf | Plug | MIL-STD-348 | SMT | Straight | 60124102122403 | 60124102122403 | 50Ohm
J6 | 60124102122403 | 60124102122403 | 60124102122403 | WR-SMP Straight | https://www.we-online.com/catalog/datasheet/60124102122403.pdf | Plug | MIL-STD-348 | SMT | Straight | 60124102122403 | 60124102122403 | 50Ohm
J7 | 60124102122403 | 60124102122403 | 60124102122403 | WR-SMP Straight | https://www.we-online.com/catalog/datasheet/60124102122403.pdf | Plug | MIL-STD-348 | SMT | Straight | 60124102122403 | 60124102122403 | 50Ohm
J8 | 60124102122403 | 60124102122403 | 60124102122403 | WR-SMP Straight | https://www.we-online.com/catalog/datasheet/60124102122403.pdf | Plug | MIL-STD-348 | SMT | Straight | 60124102122403 | 60124102122403 | 50Ohm
J9 | 60124102122403 | 60124102122403 | 60124102122403 | WR-SMP Straight | https://www.we-online.com/catalog/datasheet/60124102122403.pdf | Plug | MIL-STD-348 | SMT | Straight | 60124102122403 | 60124102122403 | 50Ohm
J10 | 60124102122403 | 60124102122403 | 60124102122403 | WR-SMP Straight | https://www.we-online.com/catalog/datasheet/60124102122403.pdf | Plug | MIL-STD-348 | SMT | Straight | 60124102122403 | 60124102122403 | 50Ohm
J11 | 60124102122403 | 60124102122403 | 60124102122403 | WR-SMP Straight | https://www.we-online.com/catalog/datasheet/60124102122403.pdf | Plug | MIL-STD-348 | SMT | Straight | 60124102122403 | 60124102122403 | 50Ohm
J12 | 60124102122403 | 60124102122403 | 60124102122403 | WR-SMP Straight | https://www.we-online.com/catalog/datasheet/60124102122403.pdf | Plug | MIL-STD-348 | SMT | Straight | 60124102122403 | 60124102122403 | 50Ohm
J13 | 60124102122403 | 60124102122403 | 60124102122403 | WR-SMP Straight | https://www.we-online.com/catalog/datasheet/60124102122403.pdf | Plug | MIL-STD-348 | SMT | Straight | 60124102122403 | 60124102122403 | 50Ohm
J14 | 60124102122403 | 60124102122403 | 60124102122403 | WR-SMP Straight | https://www.we-online.com/catalog/datasheet/60124102122403.pdf | Plug | MIL-STD-348 | SMT | Straight | 60124102122403 | 60124102122403 | 50Ohm
J15 | 60124102122403 | 60124102122403 | 60124102122403 | WR-SMP Straight | https://www.we-online.com/catalog/datasheet/60124102122403.pdf | Plug | MIL-STD-348 | SMT | Straight | 60124102122403 | 60124102122403 | 50Ohm
J16 | 60124102122403 | 60124102122403 | 60124102122403 | WR-SMP Straight | https://www.we-online.com/catalog/datasheet/60124102122403.pdf | Plug | MIL-STD-348 | SMT | Straight | 60124102122403 | 60124102122403 | 50Ohm

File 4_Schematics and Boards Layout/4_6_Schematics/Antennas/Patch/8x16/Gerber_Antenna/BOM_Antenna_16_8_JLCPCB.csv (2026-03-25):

Comment | Designator | Footprint | LCSC Part#
60124102122403 | J1,J2,J3,J4,J5,J6,J7,J8,J9,J10,J11,J12,J13,J14,J15,J16 | 60124102122403

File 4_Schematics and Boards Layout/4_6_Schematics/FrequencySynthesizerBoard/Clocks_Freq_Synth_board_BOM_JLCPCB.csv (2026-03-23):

Comment | Designator | Footprint | LCSC Part #
10pF | C1,C62,C63,C85,C86,C89 | C0201_334 | C106245
0.33µF | C2,C6 | C0201_334 | C331029
0.47µf | C3 | C0201_334 | C331025
DNP | C4,C5,C7 | C0201_334
1000pF | C8 | C0201_334 | C106246
0.47µF | C9,C10 | C0201_334 | C331025
1µF | C11,C12,C13,C14,C59,C68,C69,C70,C71,C82 | C0201_334 | C106253
10nF | C15,C17,C19 | C0402_334 | C15195
0.1µF | C16,C18,C20,C22,C24,C26,C28,C30,C32,C34,C35,C36,C37,C41,C42,C43,C44,C64,C65,C66,C67,C87,C88,C90,C91 | C0201_334 | C106250
22µF | C21,C25,C29,C33,C46,C51 | C1210_334 | C108816
10µF | C23,C27,C31,C45,C47 | C1210_334 | C108812
4.7µF | C38,C39,C40,C48,C49,C50,C55,C56,C57,C58,C72,C73,C74,C75,C76,C77,C78,C79,C80,C81 | C0201_334 | C106258
31pF | C60,C83 | C0201_334
10nF | C61,C84 | C0201_334 | C106247
0.1µf | C92 | C0201_334 | C106250
Green | D1,D2 | LED-0603 | C72043
FBMH1608HL601-T | FB1,FB2,FB3,FB4 | BEADC1608X90N | C96445
AD9523BCPZ | IC1 | QFN50P1000X1000X100-73N
142-0731-211 | J1,J2,J5,J6,J7,J8,J9,J10,J11,J12,J13 | 1420731211
CJT-T-P-HH-ST-TH1 | J3,J4 | CONN_CJT-T-P-XX-ST-TH1_SAI
DNP | JP1 | 2X06_325
DNP | JP2 | 2X07_325
1.3nH | L1,L2,L3,L4,L5,L6,L7,L8 | L0201_334
DNP | L9,L10,L11,L12,L13 | L5650M_334
100R | R1,R12,R13,R26 | R0201_334 | C106230
1k | R2,R3,R4,R7,R9,R11 | R0201_334 | C106232
0R | R5,R14,R15,R19,R20,R27,R28,R32,R33 | R0201_334 | C106222
0.65k | R6,R8,R10 | R0201_334
931R | R16,R29 | R0201_334
30R | R17,R30 | R0201_334 | C106228
330R | R18,R31 | R0201_334 | C106231
500R | R21,R34 | R0201_334
200k | R22,R23,R24,R25,R35,R36,R37,R38 | R0201_334 | C106240
22R | R39,R40,R41 | R0201_334 | C106227
ADF4382ABCCZ | U1,U6 | CC-48-10_ADI
MTX2-143+ | U2,U3,U7,U9 | DQ1225_MNC
ATS1005-3DB-FD-T05 | U4,U5,U8,U10 | SMT_DB-FD-T05_SUS
ECOC-2522-100.000-3HC | X4 | SMD5_ECOC-2522_25P4X22_ECS
CVHD-950-50.000 | X5,X6 | SMD4_CVHD-950_CRX
22-23-2021 | X10,X11,X12,X13,X14,X15 | 22-23-2021_165

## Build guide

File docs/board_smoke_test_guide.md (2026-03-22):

# AERIS-10 Board-Day Smoke Test Guide

**Target:** TE0713-03 (XC7A200T-2FBG484) + TE0701-06 carrier + UMFT601X-B FMC LPC  
**Tag:** `v0.1.9-timing-fix` (commit `f8dd6ba`)  
**Date:** 2026-03-22

---

## 1. Bitstream Inventory

| # | Bitstream File | Tag | Purpose | WNS | Use When |
|---|---|-----|---|-----|---|
| 1 | `docs/artifacts/te0713-te0701-heartbeat-2026-03-21.bit` | v0.1.7 | First-power heartbeat only | +17.863 ns | **First ever power-on** — verifies JTAG, clock, config |
| 2 | `docs/artifacts/te0713-te0701-umft601x-dev-2026-03-21.bit` | v0.1.8 | FT601 USB data path (pre-timing-fix) | +0.059 ns | Fallback if v0.1.9 build not available |
| 3 | `docs/artifacts/te0713-te0701-umft601x-dev-2026-03-22.bit` | v0.1.9 | FT601 USB + timing fix + self-test | +0.349 ns | **Primary smoke test image** |

### Building Bitstream #3 (v0.1.9)

The remote build server (`livepeerservice.ddns.net`) runs Vivado 2025.2. When online:

```bash
# SSH to build server
ssh -i ~/.ssh/id_ed25519 jason-stone@livepeerservice.ddns.net

# Pull latest code
cd /path/to/PLFM_RADAR && git pull

# Run Vivado batch build
/mnt/bcache/Xilinx/Vivado/2025.2/Vivado/bin/vivado -mode batch \
  -source 9_Firmware/9_2_FPGA/scripts/build_te0713_umft601x_dev.tcl

# Bitstream output:
#   9_Firmware/9_2_FPGA/vivado_te0713_umft601x_dev/aeris10_te0713_umft601x_dev.runs/impl_1/*.bit
# Timing report:
#   9_Firmware/9_2_FPGA/vivado_te0713_umft601x_dev/reports/timing_summary.rpt
```

Or locally if Vivado 2025.2 is installed:

```bash
cd 9_Firmware/9_2_FPGA
vivado -mode batch -source scripts/build_te0713_umft601x_dev.tcl
```

Copy the `.bit` file to `docs/artifacts/te0713-te0701-umft601x-dev-2026-03-22.bit`.

---

## 2. Hardware Setup

### 2A. Board Assembly

1. Mount **TE0713-03** module onto **TE0701-06** carrier (B2B connectors)
2. Plug **UMFT601X-B** into **TE0701 J10** (FMC LPC connector)
3. Connect **USB 3.0 Micro-B cable** from UMFT601X-B to host PC
4. Connect **Trenz USB cable** for JTAG programming

### 2B. Jumper Configuration

**TE0701-06 Carrier:**
- VIOTB = **3.3V** (bank voltage for FMC LPC I/O)

**UMFT601X-B Module:**

| Jumper | Setting | Purpose |
|---|---|---|
| JP1 | Open | Default |
| JP2 | Pins 2-3 | Default |
| JP3 | Open | Default |
| JP4 | Pins 2-3 | 245 Sync FIFO mode |
| JP5 | Pins 2-3 | 245 Sync FIFO mode |
| JP6 | Short | 3.3V VCCIO |

### 2C. Power

- TE0701 powered via USB or external 5V supply
- Verify 3.3V rail stable before programming

---

## 3. Smoke Test Procedure

### Stage 1: First Power — Heartbeat Image (LOWEST RISK)

**Purpose:** Verify FPGA configures, clock runs, basic I/O works.  
**Bitstream:** `docs/artifacts/te0713-te0701-heartbeat-2026-03-21.bit`

```
Step 1.1  Open Vivado Hardware Manager
          Vivado > Open Hardware Manager > Open Target > Auto Connect

Step 1.2  Verify JTAG enumeration
          Should see: xc7a200t (TE0713)
          If NOT: check B2B seating, power, JTAG cable

Step 1.3  Program heartbeat bitstream
          Right-click device > Program Device
          Select: docs/artifacts/te0713-te0701-heartbeat-2026-03-21.bit
          Click "Program"

Step 1.4  Verify heartbeat
          - LED/scope on heartbeat output should toggle at ~3 Hz
          - gpio1 should go HIGH after ~328 µs (POR complete)
          ✅ PASS: FPGA configured, clock running, reset released
          ❌ FAIL: Check clock source, power rails, B2B connector
```

### Stage 2: FT601 USB Integration — Dev Image

**Purpose:** Verify FT601 USB 3.0 data path, host commands, synthetic data streaming.  
**Bitstream:** `docs/artifacts/te0713-te0701-umft601x-dev-2026-03-22.bit` (v0.1.9 — timing fix + real self-test)  
**Fallback:** `docs/artifacts/te0713-te0701-umft601x-dev-2026-03-21.bit` (v0.1.8 — hardwired self-test)

```
Step 2.1  Program FT601 dev bitstream
          Same procedure as Step 1.3 with the dev bitstream

Step 2.2  Verify heartbeat still works
          - ft601_gpio0 should toggle at ~6 Hz (bit 24 of counter at 100 MHz)
          - ft601_gpio1 = HIGH (reset complete)
          ✅ If no toggle: FPGA not running. Reprogram.

Step 2.3  Check FT601 USB enumeration on host PC
          Linux:   lsusb | grep 0403:601f
          macOS:   system_profiler SPUSBDataType | grep -A5 "FT601"
          Windows: Device Manager > USB > "FTDI FT601 USB 3.0 Bridge"
          ✅ PASS: FT601 enumerated as USB 3.0 device
          ❌ FAIL: Check USB cable (must be 3.0), JP4/JP5 (Sync FIFO mode),
                   VIOTB jumper (3.3V), FMC connector seating

Step 2.4  Install host-side dependencies
          cd 9_Firmware/9_3_GUI
          pip install -r requirements_dashboard.txt
          # For live hardware: also install ftd3xx
          # Linux: pip install ftd3xx (+ FTDI D3XX driver)
          # macOS: download from ftdichip.com
          # Windows: pip install ftd3xx

Step 2.5  Run automated smoke test
          cd 9_Firmware/9_3_GUI
          python smoke_test.py --live

          Expected output:
            [INFO] Connecting to FT601...
            [INFO] Sending self-test trigger (opcode 0x30)...
            [INFO] Reading self-test results...
            [INFO] ┌──────────────────────────────────┐
            [INFO] │ FPGA Self-Test Results            │
            [INFO] ├──────────────────────────────────┤
            [INFO] │ BRAM Write/Read Pattern    PASS  │
            [INFO] │ CIC Integrator Arithmetic  PASS  │
            [INFO] │ FFT Butterfly Arithmetic   PASS  │
            [INFO] │ Saturating Add (MTI)       PASS  │
            [INFO] │ ADC Raw Data Capture       PASS  │  ← may FAIL if ADC not connected
            [INFO] └──────────────────────────────────┘

          Exit code 0 = all passed, 1 = failure, 2 = comms error

          NOTE: Test 4 (ADC capture) will likely FAIL or timeout on
          the dev wrapper because ADC inputs are not connected.
          This is expected. The other 4 tests should all PASS.

Step 2.6  (Optional) Capture ADC raw data
          python smoke_test.py --live --adc-dump adc_raw.npy
          # Saves 256 raw ADC samples to adc_raw.npy for offline analysis

Step 2.7  Verify data streaming with dashboard
          python radar_dashboard.py --live
          # Should show real-time range profile with synthetic test pattern
          # Packet header: 0xAE10xxxx (xxxx = packet type)
          # Range data: counter XOR 0xA5A5 pattern

Step 2.8  Verify host commands
          In the dashboard command panel:
            - Send "Status Request" (0xFF) → should get status response packet
            - Send "Stream Control" (0x04) with value 0x07 → enables all 3 streams
            - Send "Stream Control" (0x04) with value 0x00 → stops all streams
          ✅ PASS: Commands acknowledged, streams start/stop on demand
```

### Stage 3: Manual Verification (if no ftd3xx driver)

If the D3XX Python driver is not available, use the FTDI D3XX utility:

```
Step 3.1  Download FT600/FT601 Data Streamer utility from ftdichip.com

Step 3.2  Open utility, select FT601 device

Step 3.3  Read channel 0 — should see continuous data with pattern:
          Bytes: AE 10 01 xx ... (range profile packets)

Step 3.4  Write channel 0 — send host command:
          FF 00 00 00  (status request opcode 0xFF)
          Should trigger a status response packet in the read stream
```

---

## 4. What Each Signal Tells You

| Observable | Expected | Diagnosis if wrong |
|---|---|---|
| JTAG enumerates xc7a200t | Yes | Check power, B2B connector, JTAG cable |
| ft601_gpio0 toggles ~6 Hz | Yes | FPGA not running or clock dead |
| ft601_gpio1 = HIGH | Yes (after 328 µs) | POR not completing — clock issue |
| FT601 USB enumeration | VID 0x0403, PID 0x601F | USB cable, JP4/JP5, VIOTB |
| Self-test bits 0-3 PASS | Yes | Logic error in FPGA — check timing report |
| Self-test bit 4 (ADC) | FAIL expected on dev board | Normal — ADC not connected in dev wrapper |
| Read data = 0xAE10xxxx packets | Yes | USB data path working |
| Status response after 0xFF | Yes | Host command path working |

---

## 5. Relevant Source Files

| File | Purpose |
|---|---|
| `9_Firmware/9_2_FPGA/radar_system_top_te0713_umft601x_dev.v` | Dev wrapper top module |
| `9_Firmware/9_2_FPGA/usb_data_interface.v` | FT601 USB data interface |
| `9_Firmware/9_2_FPGA/fpga_self_test.v` | 5-subsystem self-test controller |
| `9_Firmware/9_2_FPGA/constraints/te0713_te0701_umft601x.xdc` | Pin/timing constraints |
| `9_Firmware/9_2_FPGA/scripts/build_te0713_umft601x_dev.tcl` | Vivado batch build script |
| `9_Firmware/9_3_GUI/smoke_test.py` | Host-side self-test runner |
| `9_Firmware/9_3_GUI/radar_dashboard.py` | Real-time data visualization |
| `9_Firmware/9_3_GUI/radar_protocol.py` | Protocol layer (parsing, commands) |

---

## 6. Known Limitations (Dev Wrapper)

1. **No real radar signal chain** — dev wrapper generates synthetic counter/XOR test data
2. **ADC self-test will fail** — ADC inputs tied to 0 in dev wrapper (no AD9484 connected)
3. **Self-test ADC limitation** — `fpga_self_test.v` is fully wired in v0.1.9. Tests 0-3 (BRAM, CIC, FFT, MTI arithmetic) run on real hardware. Test 4 (ADC capture) will timeout/fail because ADC inputs are tied to `16'd0` in the dev wrapper (no AD9484 connected). This is expected — all 4 logic tests should PASS.
4. **Single clock domain** — dev wrapper runs everything on `ft601_clk_in` (100 MHz). Production design has separate 400 MHz ADC clock.

---

## 7. Troubleshooting

| Problem | Likely Cause | Fix |
|---|---|-----|
| JTAG doesn't enumerate | Power, B2B connector | Reseat module, check power LED |
| Configures but no heartbeat | Clock not reaching FPGA | Check TE0701 clock source, oscillator |
| FT601 not enumerating | Wrong FIFO mode | Verify JP4=2-3, JP5=2-3 (245 Sync FIFO) |
| FT601 enumerates as USB 2.0 | Bad cable or port | Use USB 3.0 cable + USB 3.0 port |
| Data reads return zeros | ft601_txe stuck high | Check VIOTB=3.3V, FMC connector pins |
| Intermittent data errors | Timing marginal | Use v0.1.9 bitstream (timing fix), not v0.1.8 |
| smoke_test.py timeout | D3XX driver issue | Verify `import ftd3xx` works in Python |

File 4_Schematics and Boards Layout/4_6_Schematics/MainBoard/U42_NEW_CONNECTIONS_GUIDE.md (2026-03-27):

# U42 New Connections Guide — XC7A200T-2FBG484I

> **Purpose**: This guide covers ALL connections that need to be added beyond the
> original 77-signal migration. It includes: missed legacy signals, the complete
> FT601 USB 3.0 interface, STM32 control signals, and passive component requirements.
>
> **Schematic**: `RADAR_Main_Board_2.kicad_sch` (Digital sheet)
> **All connections go to U42 (FPGA)**

---

## OVERVIEW

| Category | Signal Count | Status |
|---|---|---|
| Original migration (in U42_CONNECTION_MAP.md) | 77 signals + 13 config + 143 power | Done |
| **GROUP A: Missed legacy signals** | **7 signals** | **NEW — wire these first** |
| **GROUP B: FT601 USB 3.0 interface** | **44 signals** | **NEW — entire new interface** |
| **GROUP C: STM32 control GPIO** | **4 signals** | **NEW — RTL expects these** |
| **GROUP D: Decoupling & termination passives** | ~25 components | **NEW — add to schematic** |
| Total new I/O connections | **55 signals** | |
| Grand total after this guide | **132 signals** | |

### What About the Remaining 153 Unused I/O Pins?

The XC7A200T-FBG484 has 285 total I/O pins. After wiring 132 signals, 153 I/O pins
remain unused. These should be left unconnected in the schematic and marked with
no-connect flags (X) in KiCad to suppress ERC warnings. Unused pins have internal
weak pull-downs and are safe to leave floating. You can assign no-connect flags in
bulk after all connections are complete.

---

## GROUP A: MISSED LEGACY SIGNALS (7 signals)

These were connected on the old XC7A50T but were accidentally omitted from the
77-signal migration map. They MUST be wired for the board to function correctly.

### A1. ADC_D7_N (CRITICAL — completes ADC data bus)

| Parameter | Value |
|---|---|
| **Net name** | `ADC_D7_N` |
| **FPGA ball** | **P17** |
| **FPGA pin function** | `IO_L21N_T3_DQS_A06_D22_14` |
| **Bank** | 14 (VCCO = 3.3V) |
| **KiCad unit** | Unit 1 |
| **Connects to** | U1 (AD9484) pin 19 via R10 (series resistor) |
| **Old XC7A50T ball** | R7 |
| **Signal type** | LVDS negative (differential pair with ADC_D7_P on Y18) |
| **Why missing** | The migration only had ADC_D7_P — the N leg was dropped |

**Wiring instructions:**
1. On Unit 1 of U42, find the pin `IO_L21N_T3_DQS_A06_D22_14` (ball P17)
2. Draw a wire from this pin and place a label `ADC_D7_N`
3. This label already exists in the schematic connecting to U1 via R10
4. No new passive components needed — R10 already exists

**PCB note:** Route as differential pair with ADC_D7_P (Y18). Match length to other
ADC pairs. Keep spacing consistent with other LVDS pairs.

---

### A2. ADC_DCO_P and ADC_DCO_N (CRITICAL — ADC data capture clock)

| Parameter | ADC_DCO_P | ADC_DCO_N |
|---|---|---|
| **Net name** | `ADC_DCO_P` | `ADC_DCO_N` |
| **FPGA ball** | **W19** | **W20** |
| **FPGA pin function** | `IO_L12P_T1_MRCC_14` | `IO_L12N_T1_MRCC_14` |
| **Bank** | 14 | 14 |
| **KiCad unit** | Unit 1 | Unit 1 |
| **Connects to** | U1 (AD9484) pin 50 via R12 | U1 (AD9484) pin 49 via R12 |
| **Old XC7A50T ball** | N14 | P14 |
| **Signal type** | LVDS clock positive | LVDS clock negative |

> **IMPORTANT**: These were previously listed as "artifacts" in Section 6 of the
> original connection map. That was INCORRECT. They were genuinely connected to the
> old FPGA. The ADC_DCO (Data Clock Output) is the AD9484's output clock that
> accompanies the data — the FPGA uses it to sample the LVDS data bus. Without this,
> the FPGA cannot capture ADC data.

> **Why MRCC pins?** The DCO is a clock signal. MRCC (Multi-Region Clock Capable)
> pins can drive clock networks across multiple clock regions, which is ideal for a
> 500 MSPS ADC data capture clock.

**Wiring instructions:**
1. On Unit 1 of U42, find pins `IO_L12P_T1_MRCC_14` (W19) and `IO_L12N_T1_MRCC_14` (W20)
2. Draw wires and place labels `ADC_DCO_P` and `ADC_DCO_N`
3. These labels connect to U1 (AD9484) through R12 (100 ohm differential termination resistor, already exists on board)
4. No new passive components needed

**Passive components (already on board — verify):**
- R12: 100 ohm differential termination resistor between DCO_P and DCO_N at the FPGA input. This is standard for LVDS clock reception. R12 should already be placed near U1.

**PCB note:** Route as tightly coupled differential pair. This is the highest-priority
clock signal — keep trace length short, avoid vias if possible. Place close to the
ADC data pairs for minimum skew.

---

### A3. ADAR_TX_LOAD_1 (Beamformer control — completes TX load set)

| Parameter | Value |
|---|---|
| **Net name** | `ADAR_TX_LOAD_1` |
| **FPGA ball** | **AB5** |
| **FPGA pin function** | `IO_L10N_T1_34` |
| **Bank** | 34 (VCCO = 1.8V) |
| **KiCad unit** | Unit 3 |
| **Connects to** | ADAR1_0 (ADAR1000ACCZN) pin N3 (TX_LOAD) |
| **Old XC7A50T ball** | P3 |
| **Signal type** | Digital output (1.8V LVCMOS) |

> Previously flagged as "artifact" — confirmed it WAS connected on old FPGA.
> You already have TX_LOAD_2, TX_LOAD_3, TX_LOAD_4. This completes the set.

**Complete signal path (verified from PCB backup):**
```
U42 ball AB5 (new) -----> net ADAR_TX_LOAD_1 -----> ADAR1_0 pin N3 (TX_LOAD)
                                    |
                                    +--- R46 (4.7k, 0201) ---> GND  (pull-down)
```

**All four ADAR TX_LOAD signals follow the same pattern:**

| Signal | FPGA Ball (new) | Old Ball | Destination | Pull-down Resistor | Value | Package |
|---|---|---|---|---|---|---|
| `ADAR_TX_LOAD_1` | AB5 | P3 | ADAR1_0 pin N3 (TX_LOAD) | R46 | 4.7k ohm | 0201 |
| `ADAR_TX_LOAD_2` | AA1 | T4 | ADAR2_0 pin N3 (TX_LOAD) | R70 | 4.7k ohm | 0201 |
| `ADAR_TX_LOAD_3` | AB3 | R3 | ADAR3_0 pin N3 (TX_LOAD) | R73 | 4.7k ohm | 0201 |
| `ADAR_TX_LOAD_4` | Y3 | R2 | ADAR4_0 pin N3 (TX_LOAD) | R76 | 4.7k ohm | 0201 |

**All four ADAR RX_LOAD signals (already wired, for reference):**

| Signal | FPGA Ball (new) | Old Ball | Destination | Pull-down Resistor | Value | Package |
|---|---|---|---|---|---|---|
| `ADAR_RX_LOAD_1` | AA5 | M5 | ADAR1_0 pin N2 (RX_LOAD) | R47 | 4.7k ohm | 0201 |
| `ADAR_RX_LOAD_2` | AB1 | T2 | ADAR2_0 pin N2 (RX_LOAD) | R71 | 4.7k ohm | 0201 |
| `ADAR_RX_LOAD_3` | AB2 | R1 | ADAR3_0 pin N2 (RX_LOAD) | R74 | 4.7k ohm | 0201 |
| `ADAR_RX_LOAD_4` | AA3 | N4 | ADAR4_0 pin N2 (RX_LOAD) | R77 | 4.7k ohm | 0201 |

> **R46/R47/R70/R71/R73/R74/R76/R77 are NOT series resistors** — they are 4.7k
> pull-down resistors to GND. Purpose: ensures LOAD pins default LOW when the FPGA
> is unconfigured during power-up, preventing accidental SPI register loads to the
> ADAR1000 beamformers.

**Wiring instructions:**
1. On Unit 3 of U42, find pin `IO_L10N_T1_34` (AB5)
2. Draw a wire and place a global label `ADAR_TX_LOAD_1`
3. The label connects through the hierarchy to ADAR1_0 pin N3 on the RF sheet
4. R46 (4.7k pull-down to GND) already exists on the board — no new passive components needed

---

### A4. ADAR_TR_4 (Beamformer T/R control — completes TR set)

| Parameter | Value |
|---|---|
| **Net name** | `ADAR_TR_4` |
| **FPGA ball** | **Y1** |
| **FPGA pin function** | `IO_L5N_T0_34` |
| **Bank** | 34 (VCCO = 1.8V) |
| **KiCad unit** | Unit 3 |
| **Connects to** | ADAR4_0 (ADAR1000ACCZN) pin N6 (TR) |
| **Old XC7A50T ball** | P4 |
| **Signal type** | Digital output (1.8V LVCMOS) |

> Previously flagged as "artifact" — confirmed it WAS connected on old FPGA.
> You already have TR_1, TR_2, TR_3. This completes the set.

**Complete signal path (verified from PCB backup):**
```
U42 ball Y1 (new) -----> net ADAR_TR_4 -----> ADAR4_0 pin N6 (TR)
                                  |
                                  +--- R161 (22.1k, 0201) ---> GND  (pull-down)
```

**All four ADAR TR signals follow the same pattern:**

| Signal | FPGA Ball (new) | Old Ball | Destination | Pull-down Resistor | Value | Package |
|---|---|---|---|---|---|---|
| `ADAR_TR_1` | U1 | N2 | ADAR1_0 pin N6 (TR) | R158 | 22.1k ohm | 0201 |
| `ADAR_TR_2` | T1 | N1 | ADAR2_0 pin N6 (TR) | R159 | 22.1k ohm | 0201 |
| `ADAR_TR_3` | T3 | P1 | ADAR3_0 pin N6 (TR) | R160 | 22.1k ohm | 0201 |
| `ADAR_TR_4` | Y1 | P4 | ADAR4_0 pin N6 (TR) | R161 | 22.1k ohm | 0201 |

> **R158-R161 are NOT series resistors** — they are 22.1k pull-down resistors to GND.
> Purpose: ensures the TR pin defaults LOW (receive mode) when the FPGA is
> unconfigured or tri-stated during power-up. The ADAR1000 TR pin selects between
> transmit (HIGH) and receive (LOW) mode.

**Wiring instructions:**
1. On Unit 3, find pin `IO_L5N_T0_34` (Y1)
2. Draw a wire and place a global label `ADAR_TR_4`
3. The label connects through the hierarchy to ADAR4_0 pin N6 on the RF sheet
4. R161 (22.1k pull-down to GND) already exists on the board — no new passive components needed

---

### A5. M3S_VCTRL / fpga_rf_switch (RF switch control)

| Parameter | Value |
|---|---|
| **Net name** | `M3S_VCTRL` |
| **RTL port name** | `fpga_rf_switch` |
| **FPGA ball** | **G15** |
| **FPGA pin function** | `IO_L2P_T0_AD8P_15` |
| **Bank** | 15 (VCCO = 3.3V) |
| **KiCad unit** | Unit 2 |
| **Connects to** | RF switch network (RF_SW_1..RF_SW_16 pin 6, M3SWA2-34DR+ U$1 pin 6) |
| **Old XC7A50T ball** | G15 |
| **Signal type** | Digital output (3.3V LVCMOS) |

> This controls the T/R RF switch path for all 16 ADTR1107 modules. Essential for
> radar operation — determines whether the antenna array is transmitting or receiving.

**Wiring instructions:**
1. On Unit 2, find pin `IO_L2P_T0_AD8P_15` (G15)
2. Draw a wire and place a global label `M3S_VCTRL`
3. The label should connect through the hierarchy to the RF sheet where the switches are
4. No new passive components needed at the FPGA side

---

### A6. FPGA_DAC_CLOCK (DAC clock test output)

| Parameter | Value |
|---|---|
| **Net name** | `FPGA_DAC_CLOCK` |
| **FPGA ball** | **G21** |
| **FPGA pin function** | `IO_L24P_T3_16` |
| **Bank** | 16 (VCCO = 3.3V) |
| **KiCad unit** | Unit 2 |
| **Connects to** | J18 pin 1 (SMA test connector) |
| **Old XC7A50T ball** | C13 |
| **Signal type** | Clock output (3.3V LVCMOS) |

> This is a test/debug output that brings the FPGA-generated DAC clock out to an
> SMA connector (J18). Not strictly required for operation but useful for debugging.
> The actual DAC clock input on U3 (AD9708) comes from a separate source (J20/DAC_CLOCK
> net), not directly from the FPGA.

**Wiring instructions:**
1. On Unit 2, find pin `IO_L24P_T3_16` (G21)
2. Draw a wire and place a label `FPGA_DAC_CLOCK`
3. This connects to J18 SMA connector
4. No new passive components needed

**PCB note:** Route with 50-ohm controlled impedance trace to SMA connector.

---

### GROUP A SUMMARY

| # | Net Name | Ball | Bank | Unit | Destination | Resistor on Net | Priority |
|---|---|---|---|---|---|---|---|
| A1 | `ADC_D7_N` | P17 | 14 | 1 | U1 (AD9484) pin 19 via R10 (100R diff term) | R10 already exists | CRITICAL |
| A2 | `ADC_DCO_P` | W19 | 14 | 1 | U1 (AD9484) pin 50 via R12 (100R diff term) | R12 already exists | CRITICAL |
| A3 | `ADC_DCO_N` | W20 | 14 | 1 | U1 (AD9484) pin 49 via R12 (100R diff term) | R12 already exists | CRITICAL |
| A4 | `ADAR_TX_LOAD_1` | AB5 | 34 | 3 | ADAR1_0 pin N3 (TX_LOAD) | R46 (4.7k pull-down to GND, 0201) | HIGH |
| A5 | `ADAR_TR_4` | Y1 | 34 | 3 | ADAR4_0 pin N6 (TR) | R161 (22.1k pull-down to GND, 0201) | HIGH |
| A6 | `M3S_VCTRL` | G15 | 15 | 2 | RF switches (RF_SW_1..16) | none at FPGA side | HIGH |
| A7 | `FPGA_DAC_CLOCK` | G21 | 16 | 2 | J18 SMA connector | none | MEDIUM |

**New passive components needed for Group A: NONE** (all resistors already exist on the board)

---

## GROUP B: FT601 USB 3.0 INTERFACE (44 signals)

The FT601Q-B-T (U6) is the USB 3.0 to parallel FIFO bridge. On the old MainBoard,
the FT601 was placed but **never connected to the FPGA** — all its data/control pins
have no net assignment in the PCB. This is a **completely new interface** that needs
full schematic wiring + new passive components.

### Architecture

```
PC (USB 3.0) <---> FT601Q (U6) <---> FPGA (U42 Bank 16)
                    |                    |
                    | 32-bit parallel    |
                    | FIFO bus @ 100MHz  |
                    | = 3.2 Gbps max     |
                    |                    |
                    +--------------------+
```

The FT601 provides a synchronous 245 FIFO interface:
- 32-bit data bus (bidirectional)
- 4-bit byte enable
- 100 MHz clock (output from FT601 to FPGA)
- Handshake signals: TXE#, RXF#, WR#, RD#, OE#

### Bank Assignment

All FT601 signals go to **Bank 16** (VCCO = +3V3_FPGA).

Bank 16 has 50 available I/O pins, we need 44, leaving 6 spare pins in the bank.

> **IMPORTANT**: The FT601 VCCIO on this board uses VCC33 (3.3V), matching Bank 16
> VCCO. This is required for correct voltage levels on the parallel bus.

### B1. FT601 Clock Input (CRITICAL — must be on MRCC pin)

| Parameter | Value |
|---|---|
| **Net name** | `FT601_CLK` |
| **RTL port** | `ft601_clk_in` |
| **FPGA ball** | **C18** |
| **FPGA pin function** | `IO_L13P_T2_MRCC_16` |
| **Bank** | 16 (VCCO = 3.3V) |
| **KiCad unit** | Unit 2 |
| **Connects to** | U6 (FT601Q) pin 58 (CLK) |
| **Signal type** | Clock input, 100 MHz |
| **IOSTANDARD** | LVCMOS33 |

> The 100 MHz FIFO clock MUST be on an MRCC pin so it can drive global/regional
> clock buffers inside the FPGA. C18 is `IO_L13P_T2_MRCC_16`.

**Required passive components:**
- **C_FT601_CLK**: 22pF decoupling capacitor from `FT601_CLK` net to GND, placed
  close to the FPGA ball. Reduces clock ringing. (0402 or 0603)
- **R_FT601_CLK**: Optional 33 ohm series resistor at the FT601 output (U6 pin 58)
  for source termination. Recommended for 100 MHz clock.

**Wiring in KiCad:**
1. On U6 pin 58 (CLK), draw a wire to a series resistor R_FT601_CLK (33 ohm)
2. From resistor output, place label `FT601_CLK`
3. On Unit 2 of U42, find pin `IO_L13P_T2_MRCC_16` (C18)
4. Draw a wire and place the same label `FT601_CLK`
5. Place a 22pF cap (C_FT601_CLK) from this net to GND near the FPGA pin

---

### B2. FT601 32-Bit Data Bus

| Signal | FPGA Ball | Pin Function | FT601 Pin | Direction |
|---|---|---|---|---|
| `FT601_D0` | A13 | IO_L10P_T1_16 | 40 | bidir |
| `FT601_D1` | A14 | IO_L10N_T1_16 | 41 | bidir |
| `FT601_D2` | A15 | IO_L9P_T1_DQS_16 | 42 | bidir |
| `FT601_D3` | A16 | IO_L9N_T1_DQS_16 | 43 | bidir |
| `FT601_D4` | A18 | IO_L17P_T2_16 | 44 | bidir |
| `FT601_D5` | A19 | IO_L17N_T2_16 | 45 | bidir |
| `FT601_D6` | A20 | IO_L16N_T2_16 | 46 | bidir |
| `FT601_D7` | A21 | IO_L21N_T3_DQS_16 | 47 | bidir |
| `FT601_D8` | B13 | IO_L8N_T1_16 | 50 | bidir |
| `FT601_D9` | B15 | IO_L7P_T1_16 | 51 | bidir |
| `FT601_D10` | B16 | IO_L7N_T1_16 | 52 | bidir |
| `FT601_D11` | B17 | IO_L11P_T1_SRCC_16 | 53 | bidir |
| `FT601_D12` | B18 | IO_L11N_T1_SRCC_16 | 54 | bidir |
| `FT601_D13` | B20 | IO_L16P_T2_16 | 55 | bidir |
| `FT601_D14` | B21 | IO_L21P_T3_DQS_16 | 56 | bidir |
| `FT601_D15` | B22 | IO_L20N_T3_16 | 57 | bidir |
| `FT601_D16` | D14 | IO_L6P_T0_16 | 60 | bidir |
| `FT601_D17` | D15 | IO_L6N_T0_VREF_16 | 61 | bidir |
| `FT601_D18` | D16 | IO_L5N_T0_16 | 62 | bidir |
| `FT601_D19` | D17 | IO_L12P_T1_MRCC_16 | 63 | bidir |
| `FT601_D20` | D19 | IO_L14N_T2_SRCC_16 | 64 | bidir |
| `FT601_D21` | D20 | IO_L19P_T3_16 | 65 | bidir |
| `FT601_D22` | D21 | IO_L23N_T3_16 | 66 | bidir |
| `FT601_D23` | D22 | IO_L22N_T3_16 | 67 | bidir |
| `FT601_D24` | E13 | IO_L4P_T0_16 | 69 | bidir |
| `FT601_D25` | E14 | IO_L4N_T0_16 | 70 | bidir |
| `FT601_D26` | E16 | IO_L5P_T0_16 | 71 | bidir |
| `FT601_D27` | E17 | IO_L2N_T0_16 | 72 | bidir |
| `FT601_D28` | E18 | IO_L15N_T2_DQS_16 | 73 | bidir |
| `FT601_D29` | E19 | IO_L14P_T2_SRCC_16 | 74 | bidir |
| `FT601_D30` | E21 | IO_L23P_T3_16 | 75 | bidir |
| `FT601_D31` | E22 | IO_L22P_T3_16 | 76 | bidir |

**Required passive components for data bus:**
- **33 ohm series resistors (x32)**: Place one 33-ohm series resistor on each data
  line at the FT601 side (between U6 data pin and the net label). These provide
  source termination for the 100 MHz parallel bus and reduce reflections/EMI.
  - Ref des: R_FTD0 through R_FTD31
  - Value: 33 ohm
  - Package: 0402 (recommended for density) or 0201
  - Place as close to U6 as possible

> **Note on resistor arrays**: For 32 data lines, consider using 8x 4-resistor
> arrays (e.g., CRA06S series, 4x33R in 0612 package) instead of 32 discrete
> resistors to save board space. Each array has 4 independent 33-ohm resistors.

**Wiring pattern for each data line:**
```
U6 pin XX (DATA_n) --[wire]--> R_FTDn (33R) --[wire]--> label "FT601_Dn"

U42 pin (Bank 16)  --[wire]--> label "FT601_Dn"
```

---

### B3. FT601 Byte Enables

| Signal | FPGA Ball | Pin Function | FT601 Pin | Direction |
|---|---|---|---|---|
| `FT601_BE0` | C13 | IO_L8P_T1_16 | 4 | output (FPGA->FT601) |
| `FT601_BE1` | C14 | IO_L3P_T0_DQS_16 | 5 | output |
| `FT601_BE2` | C15 | IO_L3N_T0_DQS_16 | 6 | output |
| `FT601_BE3` | C17 | IO_L12N_T1_MRCC_16 | 7 | output |

**Required passive components:**
- **33 ohm series resistors (x4)**: R_FTBE0 through R_FTBE3, same as data bus.

---

### B4. FT601 Control Signals

| Signal | FPGA Ball | Pin Function | FT601 Pin | Direction | Description |
|---|---|---|---|---|---|
| `FT601_TXE_N` | C19 | IO_L13N_T2_MRCC_16 | 8 | input (FT601->FPGA) | TX FIFO not full (active low = can write) |
| `FT601_RXF_N` | C20 | IO_L19N_T3_VREF_16 | 9 | input (FT601->FPGA) | RX FIFO has data (active low = can read) |
| `FT601_WR_N` | C22 | IO_L20P_T3_16 | 11 | output (FPGA->FT601) | Write strobe (active low) |
| `FT601_RD_N` | F13 | IO_L1P_T0_16 | 12 | output (FPGA->FT601) | Read strobe (active low) |
| `FT601_OE_N` | F14 | IO_L1N_T0_16 | 13 | output (FPGA->FT601) | Output enable (active low, assert before RD_N) |
| `FT601_SIWU_N` | F15 | IO_0_16 | 10 | output (FPGA->FT601) | Send immediate / wake up |
| `FT601_RESET_N` | F16 | IO_L2P_T0_16 | 15 | output (FPGA->FT601) | Chip reset (active low) |

**Required passive components for control signals:**
- **33 ohm series resistors (x7)**: R_FT_TXE through R_FT_RST on each control line
- **10k pull-up on RESET_N**: R_FT_RST_PU (10k ohm) from FT601_RESET_N to +3V3_FPGA.
  This ensures the FT601 is not held in reset if the FPGA pins are tri-stated
  during configuration.
- **10k pull-up on SIWU_N**: R_FT_SIWU_PU (10k ohm) from FT601_SIWU_N to +3V3_FPGA.
  Default inactive (high) when FPGA is configuring.

**Wiring for control signals with pull-ups:**
```
FT601_RESET_N:
  U6 pin 15 --[33R]--> net "FT601_RESET_N" --[wire]--> U42 (F16)
                                             |
                                             +--[10k]---> +3V3_FPGA

FT601_SIWU_N:
  U6 pin 10 --[33R]--> net "FT601_SIWU_N" --[wire]--> U42 (F15)
                                            |
                                            +--[10k]---> +3V3_FPGA
```

---

### B5. FT601 Power and Decoupling (U6 side — NOT on FPGA)

The FT601 already has power connections in the PCB (AVDD, VCC33, VCCIO, VBUS, VDDA).
However, verify these decoupling capacitors exist near U6:

| Power Pin | Net | Required Decoupling |
|---|---|---|
| Pin 2 (AVDD) | AVDD | 100nF + 4.7uF to GND |
| Pin 14 (VCCIO) | VCCIO_2 | 100nF to GND |
| Pin 20 (VCC33) | VCC33_2 | 100nF to GND |
| Pin 24 (VCC33) | VCC33_3 | 100nF to GND |
| Pin 28 (VDDA) | VDDA | 100nF + 4.7uF to GND (analog supply, critical) |
| Pin 38 (VCC33) | VCC33 | 100nF to GND |
| Pin 49 (VCCIO) | VCCIO_3 | 100nF to GND |
| Pin 59 (VCCIO) | VCCIO_4 | 100nF to GND |
| Pin 68 (VCCIO) | VCCIO | 100nF to GND |

> These should already be in the Eagle-imported design. Verify they exist before
> adding duplicates.

### B6. FT601 USB Connector Connections

The FT601 USB side connections (USB3.0 SuperSpeed differential pairs, VBUS, etc.)
are separate from the FPGA interface and should already be routed to a USB connector.
This guide only covers the FPGA-side parallel FIFO interface.

---

### GROUP B PASSIVE COMPONENT SUMMARY

| Component | Qty | Value | Package | Purpose |
|---|---|---|---|---|
| Series resistors (data bus) | 32 | 33 ohm | 0402 | Source termination for FT601_D[0:31] |
| Series resistors (byte enable) | 4 | 33 ohm | 0402 | Source termination for FT601_BE[0:3] |
| Series resistors (control) | 7 | 33 ohm | 0402 | Source termination for control signals |
| Series resistor (clock) | 1 | 33 ohm | 0402 | Source termination for FT601_CLK |
| Pull-up (RESET_N) | 1 | 10k ohm | 0402 | Hold reset high during FPGA config |
| Pull-up (SIWU_N) | 1 | 10k ohm | 0402 | Hold SIWU inactive during FPGA config |
| Decoupling cap (clock) | 1 | 22 pF | 0402 | Clock input filtering |
| **TOTAL NEW PASSIVES** | **47** | | | |

> **Alternative to 44 discrete series resistors**: Use 11x resistor arrays
> (4x33R each = 44 resistors). Example part: Bourns CAY16-33R0F4 (4x33R, 0612).
> This reduces component count from 44 to 11 and saves significant board space.

---

## GROUP C: STM32 CONTROL GPIO (4 signals)

The RTL (`radar_system_top.v`) expects these control inputs from the STM32. They
were NOT on the old MainBoard PCB — they are currently only in the dev board XDC.
However, the RTL uses them for radar scan control, so they should be added for the
production board.

### Where to Connect on STM32

The STM32F746ZGT7 (U2) has the DIG_[0:7] bus already connected (PD8-PD15).
These 4 new control signals should use other available STM32 GPIO pins. Check which
STM32 pins are available (not already assigned in schematic).

Suggested STM32 pins (from LQFP-144 package, verify availability):
- PE0 (pin 141) for stm32_new_chirp
- PE1 (pin 142) for stm32_new_elevation
- PE2 (pin 1) for stm32_new_azimuth
- PE3 (pin 2) for stm32_mixers_enable

> **IMPORTANT**: Verify these STM32 pins are actually unused in the current
> schematic before assigning. The pin suggestions above are preliminary.

### Signal Assignments

These signals are 3.3V digital, so they go to a 3.3V FPGA bank. Bank 15 has
available pins.

| Signal | FPGA Ball | Pin Function | Bank | Unit | Direction | Description |
|---|---|---|---|---|---|---|
| `STM32_NEW_CHIRP` | J16 | IO_0_15 | 15 | 2 | input | STM32 triggers new chirp |
| `STM32_NEW_ELEVATION` | M17 | IO_25_15 | 15 | 2 | input | STM32 signals new elevation step |
| `STM32_NEW_AZIMUTH` | L14 | IO_L22P_T3_A17_15 | 15 | 2 | input | STM32 signals new azimuth step |
| `STM32_MIXERS_ENABLE` | J17 | IO_L21N_T3_DQS_A18_15 | 15 | 2 | input | STM32 enables mixer circuits |

**Required passive components:**
- **10k pull-down resistors (x4)**: One on each signal, to GND. Ensures defined
  logic level (low/inactive) when STM32 or FPGA are in reset/unconfigured state.
  - R_NC (10k) — STM32_NEW_CHIRP to GND
  - R_NE (10k) — STM32_NEW_ELEVATION to GND
  - R_NA (10k) — STM32_NEW_AZIMUTH to GND
  - R_ME (10k) — STM32_MIXERS_ENABLE to GND

**Wiring pattern:**
```
STM32 (U2) pin XX --[wire]--> label "STM32_NEW_CHIRP"
                                        |
                                        +--[10k]---> GND

U42 pin (Bank 15)  --[wire]--> label "STM32_NEW_CHIRP"
```

**PCB note:** These are slow control signals (<1 MHz). No impedance control needed.
Route with standard traces, keep reasonably short (<50mm).

---

### GROUP C PASSIVE COMPONENT SUMMARY

| Component | Qty | Value | Package | Purpose |
|---|---|---|---|---|
| Pull-down resistors | 4 | 10k ohm | 0402 | Default inactive state during reset |
| **TOTAL** | **4** | | | |

---

## GROUP D: ADDITIONAL PASSIVE COMPONENTS (FPGA support)

These are passive components needed for the FPGA itself (beyond signal connections),
some of which may already be on the board from the old design.

### D1. FPGA Decoupling Capacitors

The XC7A200T requires more decoupling than the XC7A50T due to higher power
consumption. Xilinx UG483 recommends per-bank and per-rail decoupling.

**VCCINT (1.0V) decoupling — verify/add near FPGA:**
| Component | Value | Qty | Notes |
|---|---|---|---|
| Bulk caps | 47uF, 6.3V | 2 | Tantalum or ceramic, near FPGA |
| Decoupling | 4.7uF, 6.3V | 4 | Ceramic, distributed around BGA |
| Decoupling | 100nF | 14 | One per VCCINT ball (may share nearby pairs) |

**VCCAUX (1.8V) decoupling:**
| Component | Value | Qty | Notes |
|---|---|---|---|
| Bulk cap | 47uF, 6.3V | 1 | Near FPGA |
| Decoupling | 4.7uF | 2 | Ceramic |
| Decoupling | 100nF | 5 | One per VCCAUX ball |

**VCCO per bank decoupling (already partially on board from old design):**
| Bank | VCCO | 100nF caps needed | 4.7uF caps needed |
|---|---|---|---|
| Bank 13 | +3V3_FPGA | 5 (one per VCCO pin) | 1 |
| Bank 14 | +3V3_FPGA | 6 | 1 |
| Bank 15 | +3V3_FPGA | 6 | 1 |
| Bank 16 | +3V3_FPGA | 6 | 1 |
| Bank 34 | +1V8_FPGA | 6 | 1 |
| Bank 35 | +1V8_FPGA | 6 | 1 |

> **CHECK FIRST**: The old XC7A50T design likely had decoupling capacitors already
> placed. Many of these may still be on the PCB. Only add what's missing. The main
> concern is that the XC7A200T has more VCCO pins (especially Bank 16 which was
> unused before) so additional decoupling may be needed.

### D2. VREF Pin Handling

Bank 14 has a VREF pin (`IO_L19N_T3_A09_D25_VREF_14` on R14) which is used for
`ADC_D4_N`. This is fine — the VREF function is only active when the bank uses
an I/O standard that requires a reference voltage (like SSTL or HSTL). Since we're
using LVCMOS33/LVDS_25, the VREF function is not active and the pin works as a
normal I/O.

Bank 16 has `IO_L6N_T0_VREF_16` (D15) assigned to `FT601_D17`. Same situation —
LVCMOS33 doesn't need VREF, so it's fine as a normal I/O.

### D3. Bank 16 VCCO Connections (NEW — was unused)

Bank 16 was completely unused on the old design. Verify that ALL 6 VCCO_16 pins
are connected to +3V3_FPGA in the schematic:

| Ball | Function | Must connect to |
|---|---|---|
| A17 | VCCO_16 | +3V3_FPGA |
| B14 | VCCO_16 | +3V3_FPGA |
| C21 | VCCO_16 | +3V3_FPGA |
| D18 | VCCO_16 | +3V3_FPGA |
| E15 | VCCO_16 | +3V3_FPGA |
| F22 | VCCO_16 | +3V3_FPGA |

> These should already be connected from the power pin wiring (fpga_power.py script
> connected all VCCO pins). Verify in schematic that these have +3V3_FPGA global labels.

---

## WIRING ORDER (RECOMMENDED)

Follow this order for minimum rework:

### Phase 1: Critical Missing Signals (do first)
1. `ADC_D7_N` (P17) — label only, no new components
2. `ADC_DCO_P` (W19) — label only
3. `ADC_DCO_N` (W20) — label only
4. `ADAR_TX_LOAD_1` (AB5) — label only
5. `ADAR_TR_4` (Y1) — label only
6. `M3S_VCTRL` (G15) — global label
7. `FPGA_DAC_CLOCK` (G21) — label only

### Phase 2: STM32 Control GPIO (simple, 4 signals)
8-11. Wire STM32_NEW_CHIRP, _NEW_ELEVATION, _NEW_AZIMUTH, _MIXERS_ENABLE
- Add 4x 10k pull-down resistors in schematic

### Phase 3: FT601 Interface (largest — 44 signals + 47 passives)
12. Place FT601 clock connection with series R and decoupling cap
13. Wire FT601 data bus (32 lines) — add series resistors
14. Wire FT601 byte enables (4 lines) — add series resistors
15. Wire FT601 control signals (7 lines) — add series resistors + pull-ups
16. Verify FT601 power connections and decoupling

### Phase 4: Verify & Clean Up
17. Verify Bank 16 VCCO connections
18. Check decoupling capacitors (add missing ones)
19. Place no-connect flags on all unused FPGA I/O pins
20. Run ERC

---

## COMPLETE NEW PASSIVE COMPONENT BOM

| Ref | Value | Qty | Package | Purpose |
|---|---|---|---|---|
| R_FTD0..R_FTD31 | 33 ohm | 32 | 0402 | FT601 data bus series termination |
| R_FTBE0..R_FTBE3 | 33 ohm | 4 | 0402 | FT601 byte enable series termination |
| R_FT_TXE, etc. | 33 ohm | 7 | 0402 | FT601 control series termination |
| R_FT_CLK | 33 ohm | 1 | 0402 | FT601 clock series termination |
| R_FT_RST_PU | 10k ohm | 1 | 0402 | FT601 RESET_N pull-up to 3.3V |
| R_FT_SIWU_PU | 10k ohm | 1 | 0402 | FT601 SIWU_N pull-up to 3.3V |
| R_NC, R_NE, R_NA, R_ME | 10k ohm | 4 | 0402 | STM32 GPIO pull-downs |
| C_FT_CLK | 22 pF | 1 | 0402 | FT601 clock decoupling |
| **TOTAL** | | **51** | | |

> **Resistor array alternative**: Replace 44 discrete 33R resistors with 11x
> CAY16-33R0F4 (4x33R array, 0612 package). Total component count drops to 18.

---

## RTL PORT-TO-SCHEMATIC NET NAME MAPPING

For updating the XDC constraints file after wiring:

| RTL Port | Schematic Net Name | FPGA Ball | IOSTANDARD |
|---|---|---|---|
| `adc_d_n[7]` | `ADC_D7_N` | P17 | LVDS_25 |
| `adc_dco_p` | `ADC_DCO_P` | W19 | LVDS_25 |
| `adc_dco_n` | `ADC_DCO_N` | W20 | LVDS_25 |
| `adar_tx_load_1` | `ADAR_TX_LOAD_1` | AB5 | LVCMOS18 |
| `adar_tr_4` | `ADAR_TR_4` | Y1 | LVCMOS18 |
| `fpga_rf_switch` | `M3S_VCTRL` | G15 | LVCMOS33 |
| `dac_clk` (if routed to J18) | `FPGA_DAC_CLOCK` | G21 | LVCMOS33 |
| `stm32_new_chirp` | `STM32_NEW_CHIRP` | J16 | LVCMOS33 |
| `stm32_new_elevation` | `STM32_NEW_ELEVATION` | M17 | LVCMOS33 |
| `stm32_new_azimuth` | `STM32_NEW_AZIMUTH` | L14 | LVCMOS33 |
| `stm32_mixers_enable` | `STM32_MIXERS_ENABLE` | J17 | LVCMOS33 |
| `ft601_clk_in` | `FT601_CLK` | C18 | LVCMOS33 |
| `ft601_data[0]` | `FT601_D0` | A13 | LVCMOS33 |
| `ft601_data[1]` | `FT601_D1` | A14 | LVCMOS33 |
| `ft601_data[2]` | `FT601_D2` | A15 | LVCMOS33 |
| `ft601_data[3]` | `FT601_D3` | A16 | LVCMOS33 |
| `ft601_data[4]` | `FT601_D4` | A18 | LVCMOS33 |
| `ft601_data[5]` | `FT601_D5` | A19 | LVCMOS33 |
| `ft601_data[6]` | `FT601_D6` | A20 | LVCMOS33 |
| `ft601_data[7]` | `FT601_D7` | A21 | LVCMOS33 |
| `ft601_data[8]` | `FT601_D8` | B13 | LVCMOS33 |
| `ft601_data[9]` | `FT601_D9` | B15 | LVCMOS33 |
| `ft601_data[10]` | `FT601_D10` | B16 | LVCMOS33 |
| `ft601_data[11]` | `FT601_D11` | B17 | LVCMOS33 |
| `ft601_data[12]` | `FT601_D12` | B18 | LVCMOS33 |
| `ft601_data[13]` | `FT601_D13` | B20 | LVCMOS33 |
| `ft601_data[14]` | `FT601_D14` | B21 | LVCMOS33 |
| `ft601_data[15]` | `FT601_D15` | B22 | LVCMOS33 |
| `ft601_data[16]` | `FT601_D16` | D14 | LVCMOS33 |
| `ft601_data[17]` | `FT601_D17` | D15 | LVCMOS33 |
| `ft601_data[18]` | `FT601_D18` | D16 | LVCMOS33 |
| `ft601_data[19]` | `FT601_D19` | D17 | LVCMOS33 |
| `ft601_data[20]` | `FT601_D20` | D19 | LVCMOS33 |
| `ft601_data[21]` | `FT601_D21` | D20 | LVCMOS33 |
| `ft601_data[22]` | `FT601_D22` | D21 | LVCMOS33 |
| `ft601_data[23]` | `FT601_D23` | D22 | LVCMOS33 |
| `ft601_data[24]` | `FT601_D24` | E13 | LVCMOS33 |
| `ft601_data[25]` | `FT601_D25` | E14 | LVCMOS33 |
| `ft601_data[26]` | `FT601_D26` | E16 | LVCMOS33 |
| `ft601_data[27]` | `FT601_D27` | E17 | LVCMOS33 |
| `ft601_data[28]` | `FT601_D28` | E18 | LVCMOS33 |
| `ft601_data[29]` | `FT601_D29` | E19 | LVCMOS33 |
| `ft601_data[30]` | `FT601_D30` | E21 | LVCMOS33 |
| `ft601_data[31]` | `FT601_D31` | E22 | LVCMOS33 |
| `ft601_be[0]` | `FT601_BE0` | C13 | LVCMOS33 |
| `ft601_be[1]` | `FT601_BE1` | C14 | LVCMOS33 |
| `ft601_be[2]` | `FT601_BE2` | C15 | LVCMOS33 |
| `ft601_be[3]` | `FT601_BE3` | C17 | LVCMOS33 |
| `ft601_txe` (active low) | `FT601_TXE_N` | C19 | LVCMOS33 |
| `ft601_rxf` (active low) | `FT601_RXF_N` | C20 | LVCMOS33 |
| `ft601_wr_n` | `FT601_WR_N` | C22 | LVCMOS33 |
| `ft601_rd_n` | `FT601_RD_N` | F13 | LVCMOS33 |
| `ft601_oe_n` | `FT601_OE_N` | F14 | LVCMOS33 |
| `ft601_siwu_n` | `FT601_SIWU_N` | F15 | LVCMOS33 |
| (reset control) | `FT601_RESET_N` | F16 | LVCMOS33 |

---

## SIGNALS NOT WIRED (INTENTIONAL)

These RTL ports exist but do NOT need MainBoard PCB connections:

| RTL Port | Reason |
|---|---|
| `reset_n` | Not on old board. FPGA has internal power-on-reset. PROGRAM_B handles config reset. |
| `clk_120m_dac` | Dev-board only. MainBoard DAC clock comes from external oscillator via J20, not FPGA. |
| `ft601_clk_out` | Internal RTL use only (optional clock output for debug) |
| `ft601_srb[1:0]`, `ft601_swb[1:0]` | FT601 session status bits — optional, not needed for basic operation |
| `ft601_txe_n`, `ft601_rxf_n` (duplicate active-high/low) | RTL has both polarities — only wire the active-low versions |
| `current_elevation[5:0]` | Debug output — route to test header or STM32 GPIO if desired, not required |
| `current_azimuth[5:0]` | Debug output — same |
| `current_chirp[5:0]` | Debug output — same |
| `new_chirp_frame` | Debug output — same |
| `dbg_doppler_data[31:0]` | Debug only — 32 bits, impractical to route out |
| `dbg_doppler_valid` | Debug only |
| `dbg_doppler_bin[4:0]` | Debug only |
| `dbg_range_bin[5:0]` | Debug only |
| `system_status[3:0]` | Debug LEDs on dev board — route to LEDs or test header if desired |

> If you want `system_status[3:0]` visible, you could add 4 LEDs with 1k series
> resistors to spare Bank 13 pins. This is optional.

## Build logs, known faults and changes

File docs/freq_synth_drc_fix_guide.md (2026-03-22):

# Frequency Synthesizer Board - DRC Fix Guide

## Overview

The Frequency Synthesizer PCB (`Clocks_Freq_Synth_board.kicad_pcb`) originally reported
**1508 DRC violations** using KiCad defaults. After creating a `.kicad_pro` project file
with JLCPCB-matched design rules and a `.kicad_dru` custom rules file, the count is now:

| Metric | Count |
|---|---|
| **Total violations** | 661 |
| **Errors (fab-relevant)** | 9 |
| **Warnings (cosmetic)** | 652 |

The 9 remaining errors are real issues that need manual KiCad GUI fixes.

---

## DRC Reduction History

| Run | Violations | Errors | What Changed |
|-----|---|---|---|
| Original (no project file) | 1508 | ~1400+ | KiCad defaults (0.2mm clearance, 0.5mm via) |
| After `.kicad_pro` v1 | 1210 | ~200 | JLCPCB rules, but min_via_diameter=0.45mm too strict |
| After `.kicad_pro` v2 | 683 | 25 | Relaxed via/drill/hole rules for 0.35mm vias |
| After `.kicad_dru` v2 (current) | **661** | **9** | Via-to-via clearance 0.254 -> 0.20mm |

---

## Scripts Applied (in order)

1. `fix_via_clearance.py` - moved 33 signal vias away from GND stitching (force-vector algorithm)
2. `fix_pcb_vias.py` - upsized 217 vias to 0.45mm diameter, 313 drills to 0.30mm

**Backup:** `.history/Clocks_Freq_Synth_board.kicad_pcb.bak_before_clearance_fix`

---

## Project File: `.kicad_pro`

Created with JLCPCB 6-layer design rules:

| Rule | Value | Notes |
|---|---|---|
| `min_clearance` | 0.10 mm | JLCPCB 6-layer minimum |
| `min_track_width` | 0.10 mm | JLCPCB accepts 0.09mm on inner |
| `min_via_diameter` | 0.30 mm | Board has 0.35mm and 0.45mm vias |
| `min_via_annular_width` | 0.075 mm | JLCPCB minimum for standard via |
| `min_through_hole_diameter` | 0.15 mm | Board has 0.15mm drill vias |
| `min_hole_clearance` | 0.15 mm | JLCPCB minimum |
| `min_hole_to_hole` | 0.15 mm | JLCPCB minimum |
| `solder_mask_bridge` | warning severity | Cosmetic, not fab-blocking |

---

## Custom Rules File: `.kicad_dru`

Four rules to handle specific board patterns:

1. **Differential pair clearance** (0.10mm) - AD9523 diff pairs are intentionally close-spaced
2. **Via-to-via hole clearance** (0.20mm) - matches JLCPCB minimum for 0.15mm drill vias
3. **Track-to-via clearance** (0.10mm) - dense routing areas
4. **SMD pad-to-pad clearance** (0.10mm) - fine-pitch components

---

## Remaining 9 Errors (All Need Manual KiCad GUI Fix)

### 7 Courtyard Overlaps

Component pairs with overlapping courtyards. These are physically close passive
components (capacitors and inductors) that may or may not collide.

| # | Location (mm) | Components | Fix |
|---|---|---|-----|
| 1 | (108.5, 124.4) | C21 / L9 | Check 3D viewer for collision |
| 2 | (117.9, 69.3) | C45 / L12 | Check 3D viewer for collision |
| 3 | (120.7, 64.0) | L12 / C33 | Check 3D viewer for collision |
| 4 | (139.3, 148.8) | C27 / L10 | Check 3D viewer for collision |
| 5 | (144.4, 149.7) | L10 / C25 | Check 3D viewer for collision |
| 6 | (169.0, 150.0) | C31 / L11 | Check 3D viewer for collision |
| 7 | (179.7, 150.1) | C29 / L11 | Check 3D viewer for collision |

**Recommended approach:** Open in KiCad 3D viewer. If passives don't physically collide
(they're on opposite sides, or the courtyard is conservative), these are safe to accept.
If they do collide, move one component 0.2-0.5mm.

### 2 Copper Edge Clearance

Both at the same location — GND zone copper on In1.Cu and In4.Cu layers too close to
the board edge.

| # | Location (mm) | Actual Clearance | Required | Fix |
|---|---|---|---|-----|
| 1 | (98.5, 55.0) In1.Cu | 0.026 mm | 0.200 mm | Pull back zone fill or adjust board outline |
| 2 | (98.5, 55.0) In4.Cu | 0.026 mm | 0.200 mm | Pull back zone fill or adjust board outline |

**Recommended approach:** Open in KiCad, select the GND zone on In1.Cu and In4.Cu,
increase the zone's "Board Edge Clearance" to 0.25mm (or set it to use the board default).
Then re-pour zones (Edit > Fill All Zones, or press 'B').

---

## 652 Warnings Breakdown (All Cosmetic)

| Type | Count | Impact |
|---|---|---|
| Solder mask bridge | 203 | Mask slivers between pads; JLCPCB handles these |
| Silk overlap | 199 | Silkscreen text overlaps; cosmetic only |
| Silk over copper | 199 | Silkscreen on exposed copper; cosmetic only |
| Track dangling | 35 | Dangling track ends; clean up optionally |
| Text thickness | 10 | Silkscreen text too thin; cosmetic |
| Text height | 6 | Silkscreen text too small; cosmetic |

**None of these block fabrication.** JLCPCB will silently fix silk issues and mask slivers.
Dangling tracks can be cleaned up optionally but don't affect connectivity.

---

## Via Population Reference

| Type | Count | Diameter | Drill | Nets |
|---|---|---|---|---|
| Small | 199 | 0.35 mm | 0.15 mm | GND, power rails, AD9523/ADF4382 signals |
| Standard | ~530 | 0.45 mm | 0.30 mm | All others (after upsize script) |

Both are within JLCPCB 6-layer capabilities (min via: 0.15mm drill, 0.25mm pad).

---

## Path to Fab-Ready

| Step | Action | Where | Time Est. |
|---|---|---|---|
| 1 | Review 7 courtyard overlaps in 3D viewer | KiCad GUI | 10 min |
| 2 | Fix 2 copper-edge clearance (re-pour zones) | KiCad GUI | 5 min |
| 3 | Clean up 35 dangling tracks (optional) | KiCad GUI | 15 min |
| 4 | Re-run DRC to confirm 0 errors | KiCad | 2 min |
| 5 | Generate Gerbers and upload to JLCPCB | KiCad + JLCPCB | 15 min |

**Total estimated manual work: ~30 minutes** (down from ~1.5 hours before `.kicad_pro`)

The board is very close to fab-ready. The 9 errors are minor and the 652 warnings
are all cosmetic items that JLCPCB will fabricate without issue.

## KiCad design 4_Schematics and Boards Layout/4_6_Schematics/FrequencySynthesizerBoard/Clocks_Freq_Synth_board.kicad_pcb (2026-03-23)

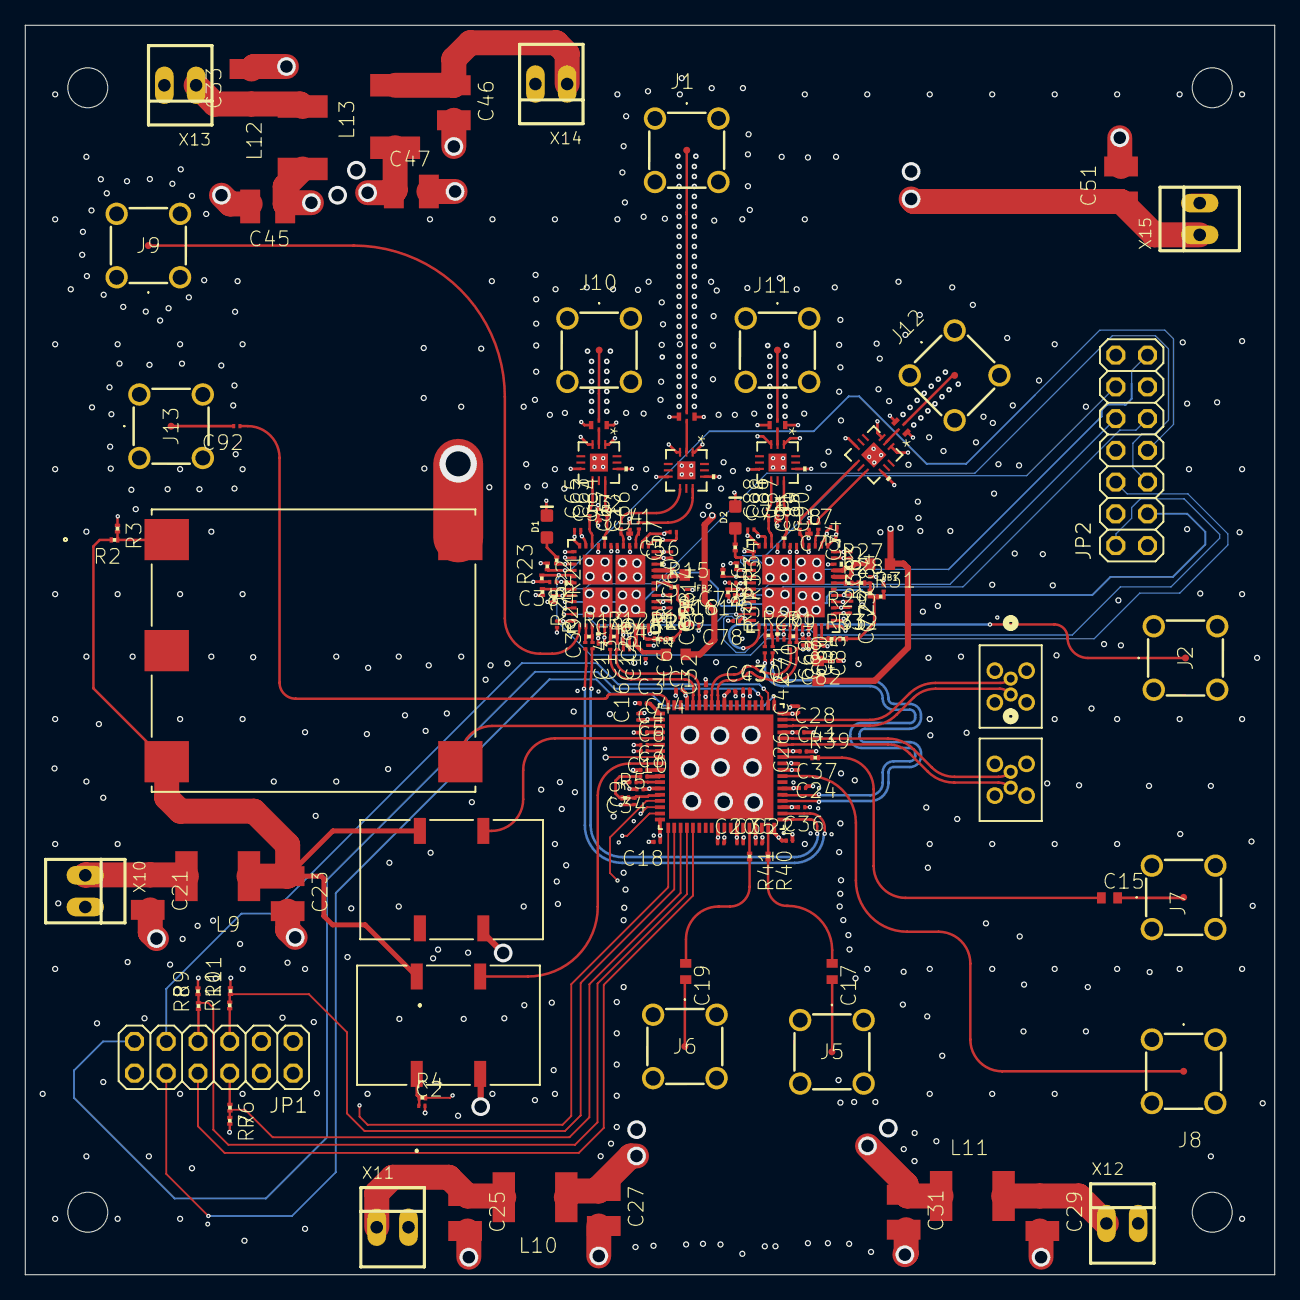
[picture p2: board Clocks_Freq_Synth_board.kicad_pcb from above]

Board: 6 copper layers, 100.0 x 100.0 mm, 188 parts (0 on the bottom side), 134 nets.

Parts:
C1, C62, C63, C85, C86, C89: 10pF; C0201_334
C2, C6: 0.33µF; C0201_334
C3: 0.47µf; C0201_334
C4, C5, C7: C0201_334
C8: 1000pF; C0201_334
C9, C10: 0.47µF; C0201_334
C11, C12, C13, C14, C59, C68, C69, C70, C71, C82: 1µF; C0201_334
C15, C17, C19: 10nF; C0402_334
C16, C18, C20, C22, C24, C26, C28, C30, C32, C34, C35, C36, C37, C41, C42, C43, C44, C64, C65, C66, C67, C87, C88, C90, C91: 0.1µF; C0201_334
C21, C25, C29, C33, C46, C51: 22µF; C1210_334
C23, C27, C31, C45, C47: 10µF; C1210_334
C38, C39, C40, C48, C49, C50, C55, C56, C57, C58, C72, C73, C74, C75, C76, C77, C78, C79, C80, C81: 4.7µF; C0201_334
C60, C83: 31pF; C0201_334
C61, C84: 10nF; C0201_334
C92: 0.1µf; C0201_334
D1, D2: Green; LED-0603
FB1, FB2, FB3, FB4: FBMH1608HL601-T; BEADC1608X90N
IC1: AD9523BCPZ; QFN50P1000X1000X100-73N
J1, J2, J5, J6, J7, J8, J9, J10, J11, J12, J13: 142-0731-211; 1420731211
J3, J4: CJT-T-P-HH-ST-TH1; CONN_CJT-T-P-XX-ST-TH1_SAI
JP1: 2X06_325
JP2: 2X07_325
L1, L2, L3, L4, L5, L6, L7, L8: 1.3nH; L0201_334
L9, L10, L11, L12, L13: L5650M_334
R1, R12, R13, R26: 100R; R0201_334
R2, R3, R4, R7, R9, R11: 1k; R0201_334
R5, R14, R15, R19, R20, R27, R28, R32, R33: 0R; R0201_334
R6, R8, R10: 0.65k; R0201_334
R16, R29: 931R; R0201_334
R17, R30: 30R; R0201_334
R18, R31: 330R; R0201_334
R21, R34: 500R; R0201_334
R22, R23, R24, R25, R35, R36, R37, R38: 200k; R0201_334
R39, R40, R41: 22R; R0201_334
U1, U6: ADF4382ABCCZ; CC-48-10_ADI
U2, U3, U7, U9: MTX2-143+; DQ1225_MNC
U4, U5, U8, U10: ATS1005-3DB-FD-T05; SMT_DB-FD-T05_SUS
UNK_HOLE_0: dummyfp0
UNK_HOLE_1: dummyfp1
UNK_HOLE_2: dummyfp2
UNK_HOLE_3: dummyfp3
X4: ECOC-2522-100.000-3HC; SMD5_ECOC-2522_25P4X22_ECS
X5, X6: CVHD-950-50.000; SMD4_CVHD-950_CRX
X10, X11, X12, X13, X14, X15: 22-23-2021; 22-23-2021_165

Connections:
10MHZ_OUT: IC1.3, X4.4
100MHZ_OUT: IC1.5, X5.3
+1V8_CLOCK: C31.1, C35.1, C36.1, C37.1, C41.1, C42.1, C43.1, C44.1, IC1.30, IC1.36, IC1.42, IC1.48, IC1.54, IC1.63, IC1.69, L11.1
+3V3_CLOCK: C16.1, C18.1, C20.1, C22.1, C24.1, C26.1, C27.1, C28.1, C30.1, C32.1, C34.1, IC1.2, IC1.13, IC1.18, IC1.27, IC1.33, IC1.39, IC1.45, IC1.51, IC1.60, IC1.66, L10.1
+3V3_LO_1: C38.1, C39.1, C40.1, C45.1, C48.1, C49.1, C50.1, C72.1, C77.1, C78.1, C79.1, C80.1, C81.1, L12.1, R24.2, R25.2, R37.2, R38.2, U1.3, U1.30, U1.36, U1.40, U1.44, U1.45, U6.3, U6.30, U6.36, U6.40, U6.44, U6.45
+3V3_LO_2: C1.1, C47.1, C55.1, C56.1, C57.1, C58.1, C63.1, C73.1, C74.1, C75.1, C76.1, C86.1, C89.1, L1.1, L2.1, L3.2, L4.2, L5.1, L6.2, L7.1, L8.2, L13.1, U1.5, U1.11, U1.13, U1.24, U6.5, U6.11, U6.13, U6.24
+3V3_XO: C23.1, L9.1, R2.2, X4.3, X5.4, X6.4
+5V0_LO: C51.1, FB1.1, FB2.1, FB3.2, FB4.2, X15.1
AD9523_CS: JP1.5, R10.1
AD9523_EEPROM_SEL: IC1.57, JP1.11
AD9523_OUT0_N: C11.2, IC1.67
AD9523_OUT0_P: C12.2, IC1.68
AD9523_OUT1_N: C68.2, IC1.64
AD9523_OUT1_P: C69.2, IC1.65
AD9523_OUT4_N: IC1.52, J3.2
AD9523_OUT4_P: IC1.53, J3.1
AD9523_OUT5_N: IC1.49, J4.2
AD9523_OUT5_P: IC1.50, J4.1
AD9523_OUT6+: C15.2, J7.1
AD9523_OUT7+: IC1.44, J8.1
AD9523_OUT8_N: C70.2, IC1.40
AD9523_OUT8_P: C71.2, IC1.41
AD9523_OUT9_N: C13.2, IC1.37
AD9523_OUT9_P: C14.2, IC1.38
AD9523_OUT10+: IC1.35, R40.1
AD9523_OUT11+: IC1.32, R41.1
AD9523_PD: IC1.15, JP1.1
AD9523_REF_SEL: IC1.16, JP1.2
AD9523_RESET: IC1.19, JP1.4
AD9523_SCLK: JP1.6, R6.1
AD9523_SDIO: JP1.7, R8.1
AD9523_SDO: IC1.23, JP1.8
AD9523_STATUS0: IC1.56, JP1.9
AD9523_STATUS1: IC1.55, JP1.10
AD9523_SYNC: IC1.17, JP1.3
ADF4382_RX_CE: JP2.10, R38.1, U6.31
ADF4382_RX_CS: JP2.9, R37.1, U6.32
ADF4382_RX_DELADJ: JP2.12, R35.2, U6.28
ADF4382_RX_DELSTR: JP2.11, R36.2, U6.29
ADF4382_RX_LKDET: JP2.13, R34.2, U6.27
ADF4382_RX_SYNC_N: C70.1, R26.2, U6.39
ADF4382_RX_SYNC_P: C71.1, R26.1, U6.38
ADF4382_SCLK: JP2.2, U1.34, U6.34
ADF4382_SDIO: JP2.3, U1.33, U6.33
ADF4382_SDO: JP2.1, U1.35, U6.35
ADF4382_TX_CE: JP2.5, R25.1, U1.31
ADF4382_TX_CS: JP2.4, R24.1, U1.32
ADF4382_TX_DELADJ: JP2.7, R22.2, U1.28
ADF4382_TX_DELSTR: JP2.6, R23.2, U1.29
ADF4382_TX_LKDET: JP2.8, R21.2, U1.27
ADF4382_TX_SYNC_N: C13.1, R13.2, U1.39
ADF4382_TX_SYNC_P: C14.1, R13.1, U1.38
GND: C1.2, C2.2, C3.1, C4.1, C5.1, C6.1, C7.1, C9.1, C10.1, C16.2, C18.2, C20.2, C21.2, C22.2, C23.2, C24.2, C25.2, C26.2, C27.2, C28.2, C29.2, C30.2, C31.2, C32.2, C33.2, C34.2, C35.2, C36.2, C37.2, C38.2, C39.2, C40.2, C41.2, C42.2, C43.2, C44.2, C45.2, C46.2, C47.2, C48.2, C49.2, C50.2, C51.2, C55.2, C56.2, C57.2, C58.2, C59.1, C60.2, C61.2, C62.2, C63.2, C72.2, C73.2, C74.2, C75.2, C76.2, C77.2, C78.2, C79.2, C80.2, C81.2, C82.1, C83.2, C84.2, C85.2, C86.2, C89.2, D1.C, D2.C, IC1.73, J1.2, J1.3, J1.4, J1.5, J2.2, J2.3, J2.4, J2.5, J5.2, J5.3, J5.4, J5.5, J6.2, J6.3, J6.4, J6.5, J7.2, J7.3, J7.4, J7.5, J8.2, J8.3, J8.4, J8.5, J9.2, J9.3, J9.4, J9.5, J10.2, J10.3, J10.4, J10.5, J11.2, J11.3, J11.4, J11.5, J12.2, J12.3, J12.4, J12.5, J13.2, J13.3, J13.4, J13.5, JP1.12, JP2.14, R3.1, R7.2, R9.2, R11.2, R22.1, R23.1, R35.1, R36.1, U1.1, U1.2, U1.4, U1.10, U1.12, U1.14, U1.16, U1.18, U1.19, U1.21, U1.23, U1.25, U1.26, U1.41, U1.48, U1.49, U1.50, U1.51, U1.52, U2.1, U2.3, U2.6, U2.10, U2.13, U3.1, U3.3, U3.6, U3.10, U3.13, U4.3, U4.4, U5.3, U5.4, U6.1, U6.2, U6.4, U6.10, U6.12, U6.14, U6.16, U6.18, U6.19, U6.21, U6.23, U6.25, U6.26, U6.41, U6.48, U6.49, U6.50, U6.51, U6.52, U7.1, U7.3, U7.6, U7.10, U7.13, U8.3, U8.4, U9.1, U9.3, U9.6, U9.10, U9.13, U10.3, U10.4, X4.5, X5.2, X6.2, X10.2, X11.2, X12.2, X13.2, X14.2, X15.2
unnamed: R2.1, R3.2, X4.1
unnamed: C2.1, R4.1, X6.1
unnamed: C3.2, IC1.1
unnamed: C6.2, IC1.7
unnamed: C4.2, IC1.4
unnamed: C5.2, IC1.6
unnamed: C7.2, IC1.10
unnamed: C8.2, IC1.11
unnamed: C8.1, R5.1
unnamed: C9.2, IC1.14, R5.2
unnamed: C10.2, IC1.12
unnamed: IC1.21, R6.2, R7.1
unnamed: IC1.22, R8.2, R9.1
unnamed: IC1.20, R10.2, R11.1
unnamed: C11.1, R12.2, U1.43
unnamed: C12.1, R12.1, U1.42
unnamed: C61.1, R18.2
unnamed: R14.1, U1.9
unnamed: FB2.2, R14.2, U1.8
unnamed: C59.2, FB3.1, U1.46
unnamed: R19.1, R20.2
unnamed: R15.1, U1.7
unnamed: R15.2, R16.2
unnamed: C60.1, R16.1, R17.2
unnamed: R17.1, R18.1, R19.2
unnamed: C62.1, R20.1, U1.47
unnamed: U2.2, U4.1
unnamed: C65.2, U2.7
unnamed: J10.1, U4.2
unnamed: C64.2, U2.9
unnamed: C67.2, U3.7
unnamed: C66.2, U3.9
unnamed: U3.2, U5.1
unnamed: J1.1, U5.2
unnamed: D1.A, R21.1
unnamed: J9.1, U1.37
unnamed: C68.1, R1.2, U6.43
unnamed: C69.1, R1.1, U6.42
unnamed: R27.1, U6.9
unnamed: FB1.2, R27.2, U6.8
unnamed: C82.2, FB4.1, U6.46
unnamed: C84.1, R31.2
unnamed: R32.1, R33.2
unnamed: R28.1, U6.7
unnamed: R28.2, R29.2
unnamed: C83.1, R29.1, R30.2
unnamed: R30.1, R31.1, R32.2
unnamed: C85.1, R33.1, U6.47
unnamed: D2.A, R34.1
unnamed: J2.1, U6.37
unnamed: C88.2, U7.7
unnamed: C87.2, U7.9
unnamed: U7.2, U8.1
unnamed: J11.1, U8.2
unnamed: C91.2, U9.7
unnamed: C90.2, U9.9
unnamed: U9.2, U10.1
unnamed: J12.1, U10.2
unnamed: C92.1, IC1.72
unnamed: C92.2, J13.1
unnamed: IC1.47, R39.1
unnamed: C15.1, R39.2
unnamed: C17.2, J5.1
unnamed: C17.1, R40.2
unnamed: C19.2, J6.1
unnamed: C19.1, R41.2
unnamed: C21.1, L9.2, X10.1
unnamed: C25.1, L10.2, X11.1
unnamed: C29.1, L11.2, X12.1
unnamed: C33.1, L12.2, X13.1
unnamed: C46.1, L13.2, X14.1
OSC_CTRL: IC1.8, R4.2
RX_RFOUT_1_N: C87.1, L5.2, U6.20
RX_RFOUT_1_P: C88.1, L6.1, U6.22
RX_RFOUT_2_N: C90.1, L7.2, U6.15
RX_RFOUT_2_P: C91.1, L8.1, U6.17
TX_RFOUT_1_N: C64.1, L2.2, U1.20
TX_RFOUT_1_P: C65.1, L3.1, U1.22
TX_RFOUT_2_N: C66.1, L1.2, U1.15
TX_RFOUT_2_P: C67.1, L4.1, U1.17
VCXO_OUT: IC1.9, X6.3

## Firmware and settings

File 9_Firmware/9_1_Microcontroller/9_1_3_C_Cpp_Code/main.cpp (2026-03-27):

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
/* Includes ------------------------------------------------------------------*/
#include "main.h"
#include "usb_device.h"
#include "USBHandler.h"
#include "usbd_cdc_if.h"
#include "adar1000.h"
#include "ADAR1000_Manager.h"
extern "C" {
#include "ad9523.h"
}
#include "no_os_delay.h"
#include "no_os_alloc.h"
#include "no_os_print_log.h"
#include "no_os_error.h"
#include "no_os_units.h"
#include "no_os_dma.h"
#include "no_os_spi.h"
#include "no_os_uart.h"
#include "no_os_util.h"
#include <stdint.h>
#include <errno.h>
#include <math.h>
#include <stdio.h>
#include <string.h>
#include <inttypes.h>
#include <iostream>
#include <vector>
#include "stm32_spi.h"
#include "stm32_delay.h"
#include "TinyGPSPlus.h"
extern "C" {
#include "GY_85_HAL.h"
}
#include "BMP180.h"
extern "C" {
#include "platform_noos_stm32.h"
}
extern "C" {

#include "adf4382a_manager.h"
#include "adf4382.h"
#include "no_os_delay.h"
#include "no_os_error.h"
#include "diag_log.h"
}
#include <cmath>
#include "DAC5578.h"
#include "ADS7830.h"
#include "gps_handler.h"

#include "stm32f7xx_hal.h"




/* USER CODE BEGIN PD */


/* -------- GPIO index mapping for no-OS interface -------- */
#define GPIO_IDX_TX_CS       0
#define GPIO_IDX_RX_CS       1
#define GPIO_IDX_TX_DELSTR   2
#define GPIO_IDX_TX_DELADJ   3
#define GPIO_IDX_RX_DELSTR   4
#define GPIO_IDX_RX_DELADJ   5
#define GPIO_IDX_TX_CE       6
#define GPIO_IDX_RX_CE       7
#define GPIO_IDX_SW_SYNC     8

/* USER CODE END PD */


I2C_HandleTypeDef hi2c1;
I2C_HandleTypeDef hi2c2;
I2C_HandleTypeDef hi2c3;

SPI_HandleTypeDef hspi1;
SPI_HandleTypeDef hspi4;

TIM_HandleTypeDef htim1;
TIM_HandleTypeDef htim3;  // B15 fix: DELADJ PWM timer (CH2=TX, CH3=RX)

UART_HandleTypeDef huart5;
UART_HandleTypeDef huart3;

/* USER CODE BEGIN PV */
// The TinyGPSPlus object
TinyGPSPlus gps;

// Global data structures
GPS_Data_t current_gps_data = {0};

// Global USB handler
USBHandler usbHandler;
extern USBD_HandleTypeDef hUsbDeviceFS;

// Buffer for USB reception
uint8_t usb_rx_buffer[64];

//IMU variable
GY85_t imu;

float Pitch_Sensor, Yaw_Sensor, Roll_Sensor;

float abias[3] = {-0.108, -0.038, -0.006}, gbias[3] = {-10, 6, -12}, mbias[3]={0.0,0.0,0.0};
float M11=1.0,  M12=-0.0,  M13=0.0,
      M21=0.0,  M22=1.0,   M23=0.0,
      M31=0.0,  M32=-0.0,  M33=1.0;
float ax, ay, az, gx, gy, gz, mx, my, mz,mxc,myc,mzc; // variables to hold latest sensor data values
float q[4] = {1.0f, 0.0f, 0.0f, 0.0f};    // vector to hold quaternion
float temperature;
float Mag_Declination = -0.61; //0°

float RxAcc,RyAcc,RzAcc;
float Rate_Ayz_1,Rate_Axz_1,Rate_Axy_1;
float Axz_1,Ayz_1,Axy_1, Axz_0,Ayz_0,Axy_0;
float RxEst_0,RyEst_0,RzEst_0, RxEst_1,RyEst_1,RzEst_1,Azr_Est;
float RxGyro,RyGyro,RzGyro, R_Est;

unsigned long now_timeperiod;
unsigned long lasttime_timeperiod = 0;
int Time_Period = 0;

//Barometer BMP180

/*resolution:
BMP180_ULTRALOWPOWER - pressure oversampled 1 time  & power consumption 3μA
BMP180_STANDARD      - pressure oversampled 2 times & power consumption 5μA
BMP180_HIGHRES       - pressure oversampled 4 times & power consumption 7μA
BMP180_ULTRAHIGHRES  - pressure oversampled 8 times & power consumption 12μA, library default
*/
BMP180 myBMP(BMP180_ULTRAHIGHRES);
float RADAR_Altitude;

//GPS
double RADAR_Longitude = 0;
double RADAR_Latitude = 0;

extern uint8_t GUI_start_flag_received;


//RADAR
// Radar parameters
const int m_max = 32;  // Number of chirps per beam position
const int n_max = 31;   // Number of beam positions
const float T1 = 30.0f; // Chirp duration in microseconds
const float PRI1 = 167.0f; // Pulse repetition interval in microseconds
const float T2 = 0.5f;  // Short chirp duration in microseconds
const float PRI2 = 175.0f; // Short PRI in microseconds
const float Guard = 175.4f; // Guard time in microseconds

uint8_t	m = 1; // m = N° of chirp/ position = 16 (made of T1 and PRF1)+ Guard = 175µs +16 (made of T2 and PRF2)
uint8_t	n = 1; // n =[1-31] N° of elevations/azimuth
uint8_t	y = 1;// y = N° of azimuths/revolution = 50 controlled by a microcontroller connected to a stepper motor
uint8_t y_max = 50;// y = N° of azimuths/revolution
uint64_t IF_freq = 120000000ULL;//120MHz

#define PowerAmplifier 1

//Stepper Motor
float Stepper_steps = 200.0f;//step per revolution

// DAC5578 handles (RF Power Amplifier DAC controlling Vg)
DAC5578_HandleTypeDef hdac1, hdac2;
/* Phase accumulators */
float phase_dac1[8] = {0};
float phase_dac2[8] = {0};
const uint32_t sampleRate = 370;    // Sample rate in Hz
const uint32_t period = 2700;       // Period in microseconds
uint8_t DAC_val = 126;

// ADC handles (RF Power Amplifier ADC measuring Idq)
ADS7830_HandleTypeDef hadc1, hadc2;
uint8_t adc1_readings[8] = {0};
uint8_t adc2_readings[8] = {0};
float Idq_reading[16]={0.0f};

/* [GAP-3 FIX 2] Hardware IWDG watchdog handle
 * Prescaler=256, Reload=500 → timeout ≈ 4.096 s from 32 kHz LSI.
 * If the main loop stalls, the MCU resets automatically. */
IWDG_HandleTypeDef hiwdg;


// Global manager instance ADF4382A
ADF4382A_Manager lo_manager;
extern SPI_HandleTypeDef hspi4;

//ADAR1000

ADAR1000Manager adarManager;
static uint8_t matrix1[15][16];
static uint8_t matrix2[15][16];
static uint8_t vector_0[16] = {0,0,0,0,0,0,0,0,0,0,0,0,0,0,0,0};

/* Radar parameters
const int m_max = 32;  // Number of chirps per beam position
const int n_max = 31;   // Number of beam positions
const float T1 = 30.0f; // Chirp duration in microseconds
const float PRI1 = 167.0f; // Pulse repetition interval in microseconds
const float T2 = 0.5f;  // Short chirp duration in microseconds
const float T2 = 175.0f; // Short PRI in microseconds
const float Guard = 175.40f; // Guard time in microseconds*/

//Temperature Sensors
ADS7830_HandleTypeDef hadc3;
float Temperature_1 = 0.0f, Temperature_2 = 0.0f, Temperature_3 = 0.0f, Temperature_4 = 0.0f;
float Temperature_5 = 0.0f, Temperature_6 = 0.0f, Temperature_7 = 0.0f, Temperature_8 = 0.0f;

// Phase differences for 31 beam positions (centered broadside).
// For d = lambda/2, |delta_phi| = 180*sin(theta) degrees, so +/-45 deg
// steering corresponds to |delta_phi| <= 127.279 deg.
const float phase_differences[31] = {
    127.279f, 63.639f, 42.426f, 31.820f, 25.456f, 21.213f, 18.189f, 15.910f, 14.142f, 12.728f,
    11.571f, 10.606f, 9.792f, 9.095f, 8.486f, 0.0f,
    -8.486f, -9.095f, -9.792f, -10.606f, -11.571f, -12.728f, -14.142f, -15.910f,
    -18.189f, -21.213f, -25.456f, -31.820f, -42.426f, -63.639f, -127.279f
};

// Convenience HAL wrappers for AD9523 control pins (GPIOF as you said)
static inline void AD9523_PD(bool v)        { HAL_GPIO_WritePin(GPIOF, AD9523_PD_Pin, v ? GPIO_PIN_SET : GPIO_PIN_RESET); }
static inline void AD9523_REF_SEL(bool v)   { HAL_GPIO_WritePin(GPIOF, AD9523_REF_SEL_Pin, v ? GPIO_PIN_SET : GPIO_PIN_RESET); }
static inline void AD9523_SYNC_PULSE(void)  { HAL_GPIO_WritePin(GPIOF, AD9523_SYNC_Pin, GPIO_PIN_SET); HAL_Delay(1); HAL_GPIO_WritePin(GPIOF, AD9523_SYNC_Pin, GPIO_PIN_RESET); }
static inline void AD9523_RESET_ASSERT()    { HAL_GPIO_WritePin(GPIOF, AD9523_RESET_Pin, GPIO_PIN_RESET); } // check polarity
static inline void AD9523_RESET_RELEASE()   { HAL_GPIO_WritePin(GPIOF, AD9523_RESET_Pin, GPIO_PIN_SET); }
static inline void AD9523_CS(bool v)        { HAL_GPIO_WritePin(GPIOF, AD9523_CS_Pin, v ? GPIO_PIN_SET : GPIO_PIN_RESET); }
static inline void AD9523_EEPROM_SEL(bool v){ HAL_GPIO_WritePin(GPIOF, AD9523_EEPROM_SEL_Pin, v ? GPIO_PIN_SET : GPIO_PIN_RESET); }

/* USER CODE END PV */

void SystemClock_Config(void);
void PeriphCommonClock_Config(void);
static void MPU_Config(void);
static void MX_GPIO_Init(void);
static void MX_TIM1_Init(void);
static void MX_TIM3_Init(void);  // B15 fix: DELADJ PWM timer init
static void MX_I2C1_Init(void);
static void MX_I2C2_Init(void);
static void MX_I2C3_Init(void);
static void MX_SPI1_Init(void);
static void MX_SPI4_Init(void);
static void MX_UART5_Init(void);
static void MX_USART3_UART_Init(void);
static void MX_IWDG_Init(void);  /* GAP-3 FIX 2: hardware watchdog */
/* USER CODE BEGIN PFP */

// Function prototypes
void systemPowerUpSequence();
void systemPowerDownSequence();
void initializeBeamMatrices();
void runRadarPulseSequence();
void executeChirpSequence(int num_chirps, uint32_t T1, uint32_t PRI1, uint32_t T2, uint32_t PRI2);
void printSystemStatus();

//////////////////////////////////////////////
////////////////////micros()//////////////////
//////////////////////////////////////////////
unsigned long micros(void){
unsigned long Micros = __HAL_TIM_GET_COUNTER(&htim1);
return Micros; //Clock TIM1 -> AHB/APB1 is set to 72MHz/presc+1   presc = 71
}

//////////////////////////////////////////////
//////////////////Delay_us()//////////////////
//////////////////////////////////////////////

void delay_us(volatile uint32_t us){
__HAL_TIM_SET_COUNTER(&htim1,0);  // set the counter value a
while (__HAL_TIM_GET_COUNTER(&htim1) < us);  // //Clock TIMx -> AHB/APB1 is set to 72MHz/presc+1   presc = 71
}

//////////////////////////////////////////////
//////////////////delay_ns()//////////////////
//////////////////////////////////////////////
void delay_ns(uint32_t nanoseconds)
{
    // Get the starting cycle count
    uint32_t start_cycles = DWT->CYCCNT;

    // Convert nanoseconds to the number of CPU clock cycles
    // Use `SystemCoreClock` to get the current CPU frequency.
    // Use 64-bit math to prevent overflow for large nanosecond values.
    uint32_t cycles = (uint32_t)(((uint64_t)nanoseconds * SystemCoreClock) / 1000000000);

    // Busy-wait until the required number of cycles has passed
    while ((DWT->CYCCNT - start_cycles) < cycles);
}

//////////////////////////////////////////////
//////////////////////RADAR///////////////////
//////////////////////////////////////////////
uint8_t degreesTo7BitPhase(float degrees) {
    // Normalize to 0-360 range
    while(degrees < 0) degrees += 360.0f;
    while(degrees >= 360.0f) degrees -= 360.0f;

    // Convert to 7-bit (0-127)
    uint8_t phase_7bit = (uint8_t)((degrees / 360.0f) * 128.0f);

    return phase_7bit % 128;
}

extern "C" {

    // USB CDC receive callback (called by STM32 HAL)
    void CDC_Receive_FS(uint8_t* Buf, uint32_t *Len) {
        DIAG("USB", "CDC_Receive_FS callback: %lu bytes received", *Len);
        // Process received USB data
        usbHandler.processUSBData(Buf, *Len);

        // Prepare for next reception
        USBD_CDC_SetRxBuffer(&hUsbDeviceFS, &usb_rx_buffer[0]);
        USBD_CDC_ReceivePacket(&hUsbDeviceFS);
    }
}

void systemPowerUpSequence() {
    DIAG_SECTION("PWR: systemPowerUpSequence");
    uint8_t msg[] = "Starting Power Up Sequence...\r\n";
    HAL_UART_Transmit(&huart3, msg, sizeof(msg)-1, 1000);

    // Step 1: Initialize ADTR1107 power sequence
    DIAG("PWR", "Step 1: initializeADTR1107Sequence()");
    if (!adarManager.initializeADTR1107Sequence()) {
        DIAG_ERR("PWR", "ADTR1107 power sequence FAILED -- calling Error_Handler()");
        uint8_t err[] = "ERROR: ADTR1107 power sequence failed!\r\n";
        HAL_UART_Transmit(&huart3, err, sizeof(err)-1, 1000);
        Error_Handler();
    }
    DIAG("PWR", "Step 1 OK: ADTR1107 sequence complete");

    // Step 2: Initialize all ADAR1000 devices
    DIAG("PWR", "Step 2: initializeAllDevices()");
    if (!adarManager.initializeAllDevices()) {
        DIAG_ERR("PWR", "ADAR1000 initialization FAILED -- calling Error_Handler()");
        uint8_t err[] = "ERROR: ADAR1000 initialization failed!\r\n";
        HAL_UART_Transmit(&huart3, err, sizeof(err)-1, 1000);
        Error_Handler();
    }
    DIAG("PWR", "Step 2 OK: All ADAR1000 devices initialized");

    // Step 3: Perform system calibration
    DIAG("PWR", "Step 3: performSystemCalibration()");
    if (!adarManager.performSystemCalibration()) {
        DIAG_WARN("PWR", "System calibration returned issues (non-fatal)");
        uint8_t warn[] = "WARNING: System calibration issues\r\n";
        HAL_UART_Transmit(&huart3, warn, sizeof(warn)-1, 1000);
    } else {
        DIAG("PWR", "Step 3 OK: System calibration passed");
    }

    // Step 4: Set to safe TX mode
    DIAG("PWR", "Step 4: setAllDevicesTXMode()");
    adarManager.setAllDevicesTXMode();
    DIAG("PWR", "Step 4 OK: All devices set to TX mode");

    uint8_t success[] = "Power Up Sequence Completed Successfully\r\n";
    HAL_UART_Transmit(&huart3, success, sizeof(success)-1, 1000);
    DIAG("PWR", "systemPowerUpSequence COMPLETE");
}
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
int main(void)
{

  /* MPU Configuration--------------------------------------------------------*/
  MPU_Config();

  /* MCU Configuration--------------------------------------------------------*/

  /* Reset of all peripherals, Initializes the Flash interface and the Systick. */
  HAL_Init();

  /* Configure the system clock */
  SystemClock_Config();

  /* Configure the peripherals common clocks */
  PeriphCommonClock_Config();

  /* Initialize all configured peripherals */
  MX_GPIO_Init();
  MX_TIM1_Init();
  MX_TIM3_Init();  // B15 fix: init DELADJ PWM timer before LO manager uses it
  MX_I2C1_Init();
  MX_I2C2_Init();
  MX_I2C3_Init();
  MX_SPI1_Init();
  MX_SPI4_Init();
  MX_UART5_Init();
  MX_USART3_UART_Init();
  MX_USB_DEVICE_Init();
  MX_IWDG_Init();  /* GAP-3 FIX 2: start hardware watchdog (~4 s timeout) */
  /* USER CODE BEGIN 2 */

  HAL_TIM_Base_Start(&htim1);

  /* --- Enable DWT cycle counter for accurate microsecond delays --- */
  DWT_Init();

  DIAG_SECTION("SYSTEM INIT");
  DIAG("SYS", "DWT cycle counter initialized, TIM1 started");
  DIAG("SYS", "HAL tick at init start: %lu ms", (unsigned long)HAL_GetTick());

  //Wait for OCXO 3mn
  DIAG("CLK", "OCXO warmup starting -- waiting 180 s (3 min)");
  uint32_t ocxo_start = HAL_GetTick();
  /* [GAP-3 FIX 2] Cannot use HAL_Delay(180000) — IWDG would reset MCU.
   * Instead loop in 1-second steps, kicking the watchdog each iteration. */
  for (int ocxo_sec = 0; ocxo_sec < 180; ocxo_sec++) {
      HAL_IWDG_Refresh(&hiwdg);
      HAL_Delay(1000);
  }
  DIAG_ELAPSED("CLK", "OCXO warmup", ocxo_start);

  DIAG_SECTION("AD9523 POWER SEQUENCING");
  DIAG("PWR", "Asserting AD9523 reset (pin LOW)");
  HAL_GPIO_WritePin(AD9523_RESET_GPIO_Port,AD9523_RESET_Pin,GPIO_PIN_RESET);

  //Power sequencing AD9523
  DIAG("PWR", "Enabling 1.8V clock rail");
  HAL_GPIO_WritePin(EN_P_1V8_CLOCK_GPIO_Port,EN_P_1V8_CLOCK_Pin,GPIO_PIN_SET);
  HAL_Delay(100);
  DIAG("PWR", "Enabling 3.3V clock rail");
  HAL_GPIO_WritePin(EN_P_3V3_CLOCK_GPIO_Port,EN_P_3V3_CLOCK_Pin,GPIO_PIN_SET);
  HAL_Delay(100);
  DIAG("PWR", "Releasing AD9523 reset (pin HIGH)");
  HAL_GPIO_WritePin(AD9523_RESET_GPIO_Port,AD9523_RESET_Pin,GPIO_PIN_SET);
  HAL_Delay(100);
  DIAG("PWR", "AD9523 power sequencing complete -- all rails up, reset released");

  //Set planned Clocks on AD9523
  /*
  o Channel 0 = 300MHz LVDS (ADF4382 TX)
  o Channel 1 = 300MHz LVDS (ADF4382 RX) (Phase aligned with Channel 0)
  o Channel 4 = 400MHz LVDS (ADC)
  o Channel 5 = 400MHz LVDS (FPGA_ADC)(Phase aligned with Channel 4)
  o Channel 6 = 100MHz LVCMOS (FPGA system clock)
  o Channel 7 = 20MHz LVCMOS (FPGA test)
  o Channel 8 = 60MHz LVDS (ADF4382 TX sync)
  o Channel 9 = 60MHz LVDS (ADF4382 RX sync)(Phase aligned with Channel 8)
  o Channel 10 = 120MHz LVCMOS
  o Channel 11 = 120MHz LVCMOS (Phase aligned with Channel 10)
   */


  // Ensure stm32_spi.c and stm32_delay.c are compiled and linked

  DIAG("CLK", "Calling configure_ad9523()...");
  uint32_t ad9523_cfg_start = HAL_GetTick();
  if (configure_ad9523() != 0) {
      // configuration error - handle as needed
      DIAG_ERR("CLK", "configure_ad9523() FAILED -- entering infinite halt loop");
      while (1) { HAL_Delay(1000); }
  }
  DIAG_ELAPSED("CLK", "configure_ad9523()", ad9523_cfg_start);
  DIAG("CLK", "AD9523 configured successfully");

  //Power sequencing FPGA
  DIAG_SECTION("FPGA POWER SEQUENCING");
  DIAG("PWR", "Enabling 1.0V FPGA rail");
  HAL_GPIO_WritePin(EN_P_1V0_FPGA_GPIO_Port,EN_P_1V0_FPGA_Pin,GPIO_PIN_SET);
  HAL_Delay(100);
  DIAG("PWR", "Enabling 1.8V FPGA rail");
  HAL_GPIO_WritePin(EN_P_1V8_FPGA_GPIO_Port,EN_P_1V8_FPGA_Pin,GPIO_PIN_SET);
  HAL_Delay(100);
  DIAG("PWR", "Enabling 3.3V FPGA rail");
  HAL_GPIO_WritePin(EN_P_3V3_FPGA_GPIO_Port,EN_P_3V3_FPGA_Pin,GPIO_PIN_SET);
  HAL_Delay(100);
  DIAG("PWR", "FPGA power sequencing complete -- 1.0V -> 1.8V -> 3.3V");


// Initialize module IMU
  DIAG_SECTION("IMU INIT (GY-85)");
  DIAG("IMU", "Initializing GY-85 IMU...");
  if (!GY85_Init()) {
      DIAG_ERR("IMU", "GY85_Init() FAILED -- calling Error_Handler()");
      Error_Handler();
  }
  DIAG("IMU", "GY-85 initialized OK, running 10 calibration samples");
  for(int i=0; i<10;i++){
  if (!GY85_Update(&imu)) {
      Error_Handler();
  }

  ax = imu.ax;
  ay = imu.ay;
  az = imu.az;
  gx = -imu.gx;
  gy = -imu.gy;
  gz = imu.gz;
  mx = imu.mx;
  my = imu.my;
  mz = imu.mz;

  ax *= 6.10351e-5;   //2.0 / 32768.0;
  ay *= 6.10351e-5;
  az *= 6.10351e-5;

  ax -= abias[0];   // Convert to g's, remove accelerometer biases
  ay -= abias[1];
  az -= abias[2];

  gx *= 0.0152588f;   //500.0 / 32768.0;
  gy *= 0.0152588f;
  gz *= 0.0152588f;

  gx -= gbias[0];   // Convert to degrees per seconds, remove gyro biases
  gy -= gbias[1];
  gz -= gbias[2];

  mx *= 6.10351e-5;   //2.0 / 32768.0;
  my *= 6.10351e-5;
  mz *= 6.10351e-5;

  mxc = M11*(mx-mbias[0]) + M12*(my-mbias[1]) +M13*(mz-mbias[2]);
  myc = M21*(mx-mbias[0]) + M22*(my-mbias[1]) +M23*(mz-mbias[2]);
  mzc = M31*(mx-mbias[0]) + M32*(my-mbias[1]) +M33*(mz-mbias[2]);

  mx = mxc;
  my = myc;
  mz = mzc;

  float norm = sqrt((mx*mx) + (my*my) + (mz*mz));
  mx /=norm;
  my /=norm;
  mz /=norm;

  /***************************************************************/
  /*********************IMU Complementary Filter******************/
  /***************************************************************/
    RxAcc = ax;
    RyAcc = ay;
    RzAcc = az;

    Rate_Ayz_1 = gx;
    Rate_Axz_1 = gy;
    Rate_Axy_1 = gz;

    Rate_Ayz_1 = Rate_Ayz_1*0.01745;//Convertion from °/s to Radians/s
    Rate_Axz_1 = Rate_Axz_1*0.01745;
    Rate_Axy_1 = Rate_Axy_1*0.01745;

    /*Combining Accelerometer & Gyroscope Data*/
    Axz_0 = atan2(RxEst_0,RzEst_0);
    Ayz_0 = atan2(RyEst_0,RzEst_0);
    Axy_0 = atan2(RxEst_0,RyEst_0);

    now_timeperiod = micros();

    Time_Period = now_timeperiod - lasttime_timeperiod;

    Axz_1= Axz_0 + Rate_Axz_1*Time_Period*0.000001;
    Ayz_1= Ayz_0 + Rate_Ayz_1*Time_Period*0.000001;
    Axy_1= Axy_0 + Rate_Axy_1*Time_Period*0.000001;

    lasttime_timeperiod = now_timeperiod;

    RxGyro = sin(Axz_1)/(sqrt(1.0 + cos(Axz_1)*cos(Axz_1) * tan(Ayz_1)*tan(Ayz_1)));
    RyGyro = sin(Ayz_1)/(sqrt(1.0 + cos(Ayz_1)*cos(Ayz_1) * tan(Axz_1)*tan(Axz_1)));
    if(RzEst_0 >= 0){
      RzGyro = 1.0*sqrt(1 - RxGyro*RxGyro - RyGyro*RyGyro);
    }
    else {
      RzGyro = -1*sqrt(1 - RxGyro*RxGyro - RyGyro*RyGyro);
    }

    RxEst_1 = RxAcc*0.5 + RxGyro*0.5 ;// Weight of Gyro. over Acc.
    RyEst_1 = RyAcc*0.5 + RyGyro*0.5 ;
    RzEst_1 = RzAcc*0.5 + RzGyro*0.5 ;

    R_Est = sqrt(RxEst_1*RxEst_1+RyEst_1*RyEst_1+RzEst_1*RzEst_1);

    Pitch_Sensor = atan2(RxEst_1,sqrt(RyEst_1*RyEst_1)+(RzEst_1*RzEst_1))*180/PI;
    Roll_Sensor = atan2(RyEst_1,sqrt(RxEst_1*RxEst_1)+(RzEst_1*RzEst_1))*180/PI;

    float magRawX = mx*cos(Pitch_Sensor*PI/180.0f)  - mz*sin(Pitch_Sensor*PI/180.0f);
	float magRawY = mx*sin(Roll_Sensor*PI/180.0f)*sin(Pitch_Sensor*PI/180.0f) + my*cos(Roll_Sensor*PI/180.0f)- mz*sin(Roll_Sensor*PI/180.0f)*cos(Pitch_Sensor*PI/180.0f);
    Yaw_Sensor = (180*atan2(magRawY,magRawX)/PI) - Mag_Declination;

    if(Yaw_Sensor<0)Yaw_Sensor+=360;
    RxEst_0 = RxEst_1;
    RyEst_0 = RyEst_1;
    RzEst_0 = RzEst_1;

    HAL_Delay(300);

  }

    ///////////////////////////////////////////////////////////////////////////////////
    ///////////////////////////////////BAROMETER BMP180////////////////////////////////
    ///////////////////////////////////////////////////////////////////////////////////
    DIAG_SECTION("BAROMETER INIT (BMP180)");
    DIAG("IMU", "Reading 5 barometer samples for altitude baseline");
  	for(int i = 0; i<5 ; i++){
		float BMP_Perssure = myBMP.getPressure();
		RADAR_Altitude = 44330*(1-(pow((BMP_Perssure/101325),(1/5.255))));
		HAL_Delay(100);
  	}
    DIAG("IMU", "Barometer init complete, RADAR_Altitude baseline set");

    ///////////////////////////////////////////////////////////////////////////////////
    ///////////////////////////////////////ADF4382/////////////////////////////////////
    ///////////////////////////////////////////////////////////////////////////////////
    DIAG_SECTION("ADF4382A LO INIT");
    printf("Starting ADF4382A Radar LO System...\n");
    printf("Using SPI4 with TIMED SYNCHRONIZATION (60 MHz clocks)\n");

    // Initialize LO manager with TIMED synchronization
    DIAG("LO", "Calling ADF4382A_Manager_Init(sync=SYNC_METHOD_TIMED)");
    uint32_t lo_init_start = HAL_GetTick();
    int ret = ADF4382A_Manager_Init(&lo_manager, SYNC_METHOD_TIMED);
    DIAG("LO", "ADF4382A_Manager_Init returned %d (took %lu ms)",
         ret, (unsigned long)(HAL_GetTick() - lo_init_start));
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

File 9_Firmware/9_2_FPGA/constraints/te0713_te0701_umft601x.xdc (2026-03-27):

# ============================================================================
# AERIS-10  FT601 via FMC LPC: TE0713 + TE0701 + UMFT601X-B
# ============================================================================
# Target: XC7A200T-2FBG484C (TE0713-03) on TE0701-06 carrier
# FT601 board: UMFT601X-B (32-bit FT601 eval, FMC LPC)
#
# Signal chain:
#   FPGA ball → TE0713 B2B → TE0701 carrier → FMC LPC J10 → UMFT601X-B FT601
#
# Bank split:
#   Bank 15 (VCCO = VIOTB): DATA[31:0], D_CLK (33 pins)
#   Bank 16 (VCCO = VIOTB): BE_N[3:0], OE_N, RD_N, WR_N, TXE_N, RXF_N,
#                            SIWU_N, RESET_N, WAKEUP_N, GPIO0, GPIO1 (14 pins)
#
# CRITICAL SETUP:
#   1. TE0701 VIOTB must be set to 3.3V (jumper J16/J17/J21 configuration)
#      OR FMC_VADJ (DIP S4) set to 3.3V with VIOTB routed to FMC_VADJ
#   2. UMFT601X-B VCCIO jumper set to 3.3V
#   3. This XDC replaces the FT601 section of xc7a200t_fbg484.xdc (production
#      PCB pinout) — do NOT use both simultaneously
#
# Source mapping:
#   UMFT601X-B: DS_UMFT60x.pdf Table 2.7 (CN4 FMC connector, FT601 column)
#   TE0701→TE0713: TE0701_FMC_PINOUT.xlsx (FMC J10 → B2B → FPGA pin)
#
# Verified: 2026-03-19
# ============================================================================

# --------------------------------------------------------------------------
# TE0713 On-board 50 MHz Oscillator (Bank 14, pin U20)
# Used for free-running POR to release FT601 chip reset without deadlock.
# The FT601 can't provide ft601_clk_in while chip_reset_n is held low,
# so this independent clock breaks the chicken-and-egg.
# --------------------------------------------------------------------------
set_property PACKAGE_PIN U20 [get_ports {osc_50m}]
set_property IOSTANDARD LVCMOS33 [get_ports {osc_50m}]
create_clock -name osc_50m -period 20.000 [get_ports {osc_50m}]
set_input_jitter [get_clocks osc_50m] 0.100

# --------------------------------------------------------------------------
# FT601 Clock Input — 100 MHz from FT601 chip
# FMC: LA18_P_CC → FPGA J20 (Bank 15, IO_L11P_T1_SRCC_15)
# SRCC is sufficient for 100 MHz FIFO clock via IBUF→BUFG
# --------------------------------------------------------------------------
set_property PACKAGE_PIN J20 [get_ports {ft601_clk_in}]
set_property IOSTANDARD LVCMOS33 [get_ports {ft601_clk_in}]
create_clock -name ft601_clk_in -period 10.000 [get_ports {ft601_clk_in}]
set_input_jitter [get_clocks ft601_clk_in] 0.100

# --------------------------------------------------------------------------
# CDC false path: osc_50m POR → ft601_clk_in domain
# The osc_por_counter drives ft601_chip_reset_n (monotonic 0→1 transition).
# No metastability risk: the FT601 clock only starts AFTER the reset is
# released, so the ft601_clk_in domain never samples a changing value.
# --------------------------------------------------------------------------
set_false_path -from [get_clocks osc_50m] -to [get_clocks ft601_clk_in]

# --------------------------------------------------------------------------
# FT601 Data Bus [31:0] — bidirectional, 3.3V LVCMOS
# All data pins in Bank 15
# --------------------------------------------------------------------------
# FMC LA32_N → L21
set_property PACKAGE_PIN L21 [get_ports {ft601_data[0]}]
# FMC LA33_N → N20
set_property PACKAGE_PIN N20 [get_ports {ft601_data[1]}]
# FMC LA32_P → M21
set_property PACKAGE_PIN M21 [get_ports {ft601_data[2]}]
# FMC LA33_P → M20
set_property PACKAGE_PIN M20 [get_ports {ft601_data[3]}]
# FMC LA30_N → M13
set_property PACKAGE_PIN M13 [get_ports {ft601_data[4]}]
# FMC LA31_N → N22
set_property PACKAGE_PIN N22 [get_ports {ft601_data[5]}]
# FMC LA30_P → L13
set_property PACKAGE_PIN L13 [get_ports {ft601_data[6]}]
# FMC LA31_P → M22
set_property PACKAGE_PIN M22 [get_ports {ft601_data[7]}]
# FMC LA28_N → H18
set_property PACKAGE_PIN H18 [get_ports {ft601_data[8]}]
# FMC LA29_N → K17
set_property PACKAGE_PIN K17 [get_ports {ft601_data[9]}]
# FMC LA28_P → H17
set_property PACKAGE_PIN H17 [get_ports {ft601_data[10]}]
# FMC LA29_P → J17
set_property PACKAGE_PIN J17 [get_ports {ft601_data[11]}]
# FMC LA24_N → L15
set_property PACKAGE_PIN L15 [get_ports {ft601_data[12]}]
# FMC LA25_N → J15
set_property PACKAGE_PIN J15 [get_ports {ft601_data[13]}]
# FMC LA24_P → L14
set_property PACKAGE_PIN L14 [get_ports {ft601_data[14]}]
# FMC LA25_P → H15
set_property PACKAGE_PIN H15 [get_ports {ft601_data[15]}]
# FMC LA27_N → G13
set_property PACKAGE_PIN G13 [get_ports {ft601_data[16]}]
# FMC LA26_N → G15
set_property PACKAGE_PIN G15 [get_ports {ft601_data[17]}]
# FMC LA27_P → H13
set_property PACKAGE_PIN H13 [get_ports {ft601_data[18]}]
# FMC LA26_P → G16
set_property PACKAGE_PIN G16 [get_ports {ft601_data[19]}]
# FMC LA21_N → G18
set_property PACKAGE_PIN G18 [get_ports {ft601_data[20]}]
# FMC LA22_N → L18
set_property PACKAGE_PIN L18 [get_ports {ft601_data[21]}]
# FMC LA21_P → G17
set_property PACKAGE_PIN G17 [get_ports {ft601_data[22]}]
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

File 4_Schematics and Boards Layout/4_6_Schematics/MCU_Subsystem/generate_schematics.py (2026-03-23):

#!/usr/bin/env python3
"""
Generate KiCad 10 schematic sub-sheets for the AERIS-10 MCU Subsystem.
Uses global labels to interconnect between sheets.
All pin assignments match the firmware main.h and existing schematic analysis.
"""
import uuid
import os

OUT_DIR = "/Users/ganeshpanth/PLFM_RADAR/4_Schematics and Boards Layout/4_6_Schematics/MCU_Subsystem"

def uid():
    return str(uuid.uuid4())

def power_symbol(name, ref, x, y, orientation=0, lib="power"):
    """Generate a power symbol (GND, +3V3, etc.)"""
    # Map common power names to their lib_id
    power_map = {
        "GND": ("GND", "GND"),
        "+3V3": ("+3V3", "+3V3"),
        "+5V": ("+5V", "+5V"),
        "+1V8": ("+1V8", "+1V8"),
        "+1V0": ("+1V0", "+1V0"),
        "VDDA": ("VDDA", "VDDA"),
        "VBUS": ("VBUS", "VBUS"),
    }
    
    sym_name, val = power_map.get(name, (name, name))
    u = uid()
    
    # Determine pin direction based on power type
    if name == "GND":
        pin_dir = "U"
        pin_y = 0  # pin at bottom for GND symbols
    else:
        pin_dir = "D"
        pin_y = 0
    
    return f"""
	(symbol
		(lib_id "{lib}:{sym_name}")
		(at {x} {y} {orientation})
		(unit 1)
		(exclude_from_sim no)
		(in_bom no)
		(on_board no)
		(dnp no)
		(uuid "{u}")
		(property "Reference" "#{ref}"
			(at {x} {y-2.54} 0)
			(effects
				(font (size 1.27 1.27))
				(hide yes)
			)
		)
		(property "Value" "{val}"
			(at {x} {y+2.54} 0)
			(effects
				(font (size 1.27 1.27))
			)
		)
		(pin "{pin_dir}" (uuid "{uid()}"))
	)"""

def global_label(name, x, y, direction="input", shape="passive"):
    """Generate a global label for inter-sheet connections."""
    u = uid()
    return f"""
	(global_label "{name}"
		(shape {shape})
		(at {x} {y} {"0" if direction in ("input", "output", "passive") else "180"})
		(effects
			(font (size 1.27 1.27))
			(justify left)
		)
		(uuid "{u}")
		(property "Intersheets" ""
			(at 0 0 0)
			(effects
				(font (size 1.27 1.27))
				(hide yes)
			)
		)
	)"""

def net_label(name, x, y, orientation=0):
    u = uid()
    return f"""
	(label "{name}"
		(at {x} {y} {orientation})
		(effects
			(font (size 1.27 1.27))
			(justify left)
		)
		(uuid "{u}")
	)"""

def wire(x1, y1, x2, y2):
    u = uid()
    return f"""
	(wire
		(pts
			(xy {x1} {y1}) (xy {x2} {y2})
		)
		(stroke
			(width 0)
			(type default)
		)
		(uuid "{u}")
	)"""

def no_connect(x, y):
    u = uid()
    return f"""
	(no_connect
		(at {x} {y})
		(uuid "{u}")
	)"""

def capacitor(ref, value, x, y, u_id=None, fp="Capacitor_SMD:C_0201_0603Metric"):
    """Place a decoupling capacitor."""
    u = u_id or uid()
    return f"""
	(symbol
		(lib_id "Device:C")
		(at {x} {y} 0)
		(unit 1)
		(exclude_from_sim no)
		(in_bom yes)
		(on_board yes)
		(dnp no)
		(uuid "{u}")
		(property "Reference" "{ref}"
			(at {x+2.54} {y} 0)
			(effects
				(font (size 1.27 1.27))
				(justify left)
			)
		)
		(property "Value" "{value}"
			(at {x+2.54} {y+2.54} 0)
			(effects
				(font (size 1.27 1.27))
				(justify left)
			)
		)
		(property "Footprint" "{fp}"
			(at {x} {y} 0)
			(effects
				(font (size 1.27 1.27))
				(hide yes)
			)
		)
		(pin "1" (uuid "{uid()}"))
		(pin "2" (uuid "{uid()}"))
	)"""

def resistor(ref, value, x, y, orientation=0, fp="Resistor_SMD:R_0201_0603Metric"):
    u = uid()
    return f"""
	(symbol
		(lib_id "Device:R")
		(at {x} {y} {orientation})
		(unit 1)
		(exclude_from_sim no)
		(in_bom yes)
		(on_board yes)
		(dnp no)
		(uuid "{u}")
		(property "Reference" "{ref}"
			(at {x+2.54} {y} 0)
			(effects
				(font (size 1.27 1.27))
				(justify left)
			)
		)
		(property "Value" "{value}"
			(at {x+2.54} {y+2.54} 0)
			(effects
				(font (size 1.27 1.27))
				(justify left)
			)
		)
		(property "Footprint" "{fp}"
			(at {x} {y} 0)
			(effects
				(font (size 1.27 1.27))
				(hide yes)
			)
		)
		(pin "1" (uuid "{uid()}"))
		(pin "2" (uuid "{uid()}"))
	)"""

def led(ref, color, x, y):
    u = uid()
    return f"""
	(symbol
		(lib_id "Device:LED")
		(at {x} {y} 0)
		(unit 1)
		(exclude_from_sim no)
		(in_bom yes)
		(on_board yes)
		(dnp no)
		(uuid "{u}")
		(property "Reference" "{ref}"
			(at {x+2.54} {y} 0)
			(effects
				(font (size 1.27 1.27))
				(justify left)
			)
		)
		(property "Value" "{color}"
			(at {x+2.54} {y+2.54} 0)
			(effects
				(font (size 1.27 1.27))
				(justify left)
			)
		)
		(pin "K" (uuid "{uid()}"))
		(pin "A" (uuid "{uid()}"))
	)"""

def text_note(txt, x, y, size=2.54):
    u = uid()
    return f"""
	(text "{txt}"
		(exclude_from_sim no)
		(at {x} {y} 0)
		(effects
			(font (size {size} {size}))
			(justify left)
		)
		(uuid "{u}")
	)"""

def sheet_header(title, date="2026-03-22", rev="0.1", comment1="", paper="A3"):
    return f"""(kicad_sch
	(version 20260306)
	(generator "eeschema")
	(generator_version "10.0")
	(uuid "{uid()}")
	(paper "{paper}")
	(title_block
		(title "{title}")
		(date "{date}")
		(rev "{rev}")
		(company "PLFM_RADAR Project")
		(comment 1 "{comment1}")
	)
	(lib_symbols)
"""

def sheet_footer(page_num):
    return f"""
	(sheet_instances
		(path "/"
			(page "{page_num}")
		)
	)
	(embedded_fonts no)
)
"""

def connector_header(ref, pins, x, y, name="Conn"):
    """Generate a generic pin header connector."""
    u = uid()
    pin_entries = ""
    for i in range(1, pins+1):
        pin_entries += f'\n\t\t(pin "{i}" (uuid "{uid()}"))'
    
    return f"""
	(symbol
		(lib_id "Connector_Generic:Conn_01x{pins:02d}")
		(at {x} {y} 0)
		(unit 1)
		(exclude_from_sim no)
		(in_bom yes)
		(on_board yes)
		(dnp no)
		(uuid "{u}")
		(property "Reference" "{ref}"
			(at {x+5.08} {y} 0)
			(effects
				(font (size 1.27 1.27))
				(justify left)
			)
		)
		(property "Value" "{name}"
			(at {x+5.08} {y+2.54} 0)
			(effects
				(font (size 1.27 1.27))
				(justify left)
			)
		){pin_entries}
	)"""
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

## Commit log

2026-03-22 Timing fix: register ft601_txe/ft601_rxf inputs (WNS +0.059ns -> expected ~+0.5ns)
    Critical path was ft601_txe pad -> FSM combinational logic -> IOB output
    register CE (only 59ps slack). All top-10 critical paths originated from
    the same unregistered ft601_txe input.
    RTL: add ft601_txe_r/ft601_rxf_r pipeline registers in usb_data_interface.v
    Replace all FSM uses of ft601_txe/ft601_rxf with registered versions
    XDC: add IOB TRUE constraints for input pipeline registers
    TB: adjust timing-sensitive checks for 1-cycle pipeline latency
    Rewrite Group 14 interleave test to use backpressure stall
    Regression: 24/24 pass, lint clean, 81/81 USB interface checks pass
    [tb_usb_data_interface.v, te0713_te0701_umft601x.xdc]
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2026-03-22 Add board-day smoke test guide with step-by-step instructions
    Covers:
    - Bitstream inventory (heartbeat v0.1.7, FT601 dev v0.1.8, timing-fix v0.1.9)
    - Hardware setup: TE0713 + TE0701 + UMFT601X-B jumper config
    - 3-stage smoke test: heartbeat → FT601 USB → host commands
    - Host-side smoke_test.py and radar_dashboard.py usage
    - Signal diagnostics table, troubleshooting, known limitations
    - Vivado build instructions (remote + local)
2026-03-22 Wire fpga_self_test into dev wrapper (replaces hardwired flags)
    - Instantiate fpga_self_test.v in radar_system_top_te0713_umft601x_dev.v
    - Opcode 0x30 triggers real self-test FSM, 0x31 reads latched results
    - ADC inputs tied to 0 (Test 4 will timeout — expected on dev board)
    - Tests 0-3 (BRAM, CIC, FFT, MTI arith) will run on real hardware
    - Updated build_te0713_umft601x_dev.tcl to include fpga_self_test.v
    - Regression: 28/28 pass, lint clean
2026-03-22 Fix Ctrl+C crash in radar_dashboard.py (GIL + tkinter threading race)
    Root cause: Ctrl+C killed mainloop but never called on_closing(),
    leaving the acquisition thread running. The thread's log.info() calls
    went through _TextHandler.emit() -> widget.after() on a dying Tcl
    interpreter, causing a fatal GIL state error.
    Fix:
    - Add SIGINT handler that schedules on_closing() via root.after()
    - Add _closed guard to _TextHandler.emit() (no-op during teardown)
    - on_closing() disables log handler BEFORE stopping threads
    - Wrap mainloop() with KeyboardInterrupt fallback
    - Store _TextHandler as self._log_handler for shutdown access
    - Reentrance guard (_closing flag) prevents double-destroy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
    [radar_dashboard.py]
2026-03-22 Revert "Fix Ctrl+C crash in radar_dashboard.py (GIL + tkinter threading race)"
    This reverts commit 7f0e7b4cac3175e6660dc97f5b219f5a3faf1495.
    [radar_dashboard.py]
2026-03-22 Fix dashboard: auto-connect, faster mock data, error-safe display loop
    Issues:
    1. Window appeared blank — user had to manually click Connect
    2. Mock data was slow (3.2s/frame) — 50ms sleep × 32 packets/read
    3. _schedule_update had no error protection — any exception
    killed the refresh timer permanently
    Fixes:
    - Auto-connect in mock/replay mode (root.after 200ms)
    - Mock read: 10ms sleep, 256 packets/read → 0.27s/frame (12× faster)
    - try/except in _schedule_update with log.error (timer survives)
    Tests: 58/58 pass (1.1s, was 4.5s)
    [radar_dashboard.py, radar_protocol.py]
2026-03-22 Fix deadlock: never call root.after() from background threads
    Root cause: classic deadlock between logging lock and Tkapp_ThreadSend.
    1. Acquisition thread: holds logging lock → emit() → widget.after()
    → Tkapp_ThreadSend → waits for main thread to process
    2. Main thread: _on_connect_done → log.info() → tries to acquire
    logging lock → waits for acquisition thread
    Result: both threads wait on each other → GUI freezes permanently.
    Fix — eliminate ALL root.after() calls from non-main threads:
    - _TextHandler: queue-based emit() + main-thread _drain() loop
    - _do_connect: polling flag + _poll_connect_result() on main thread
    - _on_status_received: _pending_st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
    [radar_dashboard.py]
2026-03-22 Fix mock data: sequential coherent packets with localized targets
    Old mock generated random rbin/dbin per packet but _ingest_sample()
    placed them sequentially — result was random noise with flickery
    detections scattered across the entire range-Doppler map.
    New mock:
    - Sequential packet generation matching _ingest_sample() order
    - Two coherent targets:
    A: stationary at range bin ~20, Doppler bin 0 (DC)
    B: moving at range bin ~40, Doppler bin ~8
    - Gaussian noise floor (sigma=30)
    - Detection flag based on magnitude threshold (>3000)
    - Pre-allocated buffer with struct.pack_into (faster)
    - Frame counter increments correctly at NUM_CELLS boundary
    Tests: 58/58 pass
    [radar_protocol.py]
2026-03-22 Clarify detection scatter coordinate mapping after fftshift
    Add explicit comments explaining how shifted Doppler array indices
    map to velocity coordinates. The coordinate conversion was correct,
    but now it's documented:
    - Shifted index 0 = original bin 16 = -max_vel (most negative)
    - Shifted index 16 = original bin 0 = 0 m/s (DC)
    - Shifted index 31 = original bin 15 = +max_vel (most positive)
    This ensures detection markers (green X) align correctly with the
    heatmap cells after np.fft.fftshift centers the DC bin.
    [radar_dashboard.py]
2026-03-22 Fix waterfall diagonal artifact: stable colormap scaling
    The waterfall was showing diagonal stripes instead of horizontal bands
    for stationary targets. This was caused by frame-to-frame colormap
    rescaling (wf_max = max(wf_arr)) which creates visual artifacts when
    the data has noise variations.
    Fix: Use exponential moving average (EMA) for waterfall vmax, matching
    the heatmap approach. Alpha=0.1 gives slow adaptation while preventing
    the diagonal sliding appearance.
    Before: vmax changes every frame → brightness shifts make targets
    appear to move diagonally
    After: vmax smoothed over ~10 frames → stable brightness → horizontal
    bands for stationary targets
    [radar_dashboard.py]
2026-03-22 Fix replay waterfall diagonal bug: ensure packet-aligned reads
    Root cause: read(4096) returned fixed byte sizes that didn't align
    with 35-byte packets. 4096 % 35 = 11, causing 11-byte remainder
    each read that shifted packet boundaries frame-to-frame.
    Result: samples misaligned, each frame had different data producing
    diagonal stripes in waterfall (range profile varied over time).
    Fix: Round read size down to nearest multiple of packet size (35)
    before returning data. Combined with seamless circular buffer wrap,
    this ensures every read starts and ends on packet boundaries.
    Test: 5 consecutive frames now identical (max diff = 0).
    [radar_protocol.py]
2026-03-22 Revert "Fix replay waterfall diagonal bug: ensure packet-aligned reads"
    This reverts commit 29a36c405c9c4e87fac3b8bce49b0923d3071552.
    [radar_protocol.py]
2026-03-22 Add --moving-target mode: approaching target with closing range
    Reverted packet alignment fix since diagonal waterfall is correct
    for moving targets (range changes over time = diagonal stripes).
    New --moving-target flag simulates target approaching radar:
    - Target starts at range bin 55 (far, ~280m)
    - Moves toward radar at 0.3 bins/frame (negative velocity)
    - High positive Doppler (Doppler bin 25 = approaching fast)
    - When target reaches close range, resets to far range
    Waterfall shows leftward diagonal stripes (range closing).
    Range-Doppler map shows target at varying ranges.
    Usage: python3 radar_dashboard.py --moving-target
    [radar_dashboard.py, radar_protocol.py]
2026-03-22 Parameterize GUI axis labels for CN0566 vs AERIS-10 radar configs
    The dashboard hardcoded AERIS-10 range/velocity parameters (307m max range),
    producing wrong physical axes when replaying CN0566 data (should be 360m for
    baseband IQ, with only first 32 bins being physical range).
    Changes:
    - ReplayConnection now carries a radar_config dict (CN0566 defaults)
    - radar_config.json sidecar files override defaults per data directory
    - RadarDashboard reads config from connection (replay) or uses AERIS-10 (mock/live)
    - Two range formulas: 'baseband' for CN0566, 'if' for AERIS-10
    - 13 new tests covering config loading, axis calculations, both formulas
    - Add hex_3x5_array replay data (6 .npy files from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
    [radar_dashboard.py, radar_protocol.py, test_radar_dashboard.py]
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2026-03-22 Add modified freq synth PCB to main repo (was trapped in nested .history/ git)
    - Copied DRC-fixed .kicad_pcb from .history/ to FrequencySynthesizerBoard/ root
    - Updated fix scripts to reference the new canonical PCB location
    - PCB has 33 vias repositioned + 217 upsized to 0.45mm + 313 drills to 0.30mm
    [Clocks_Freq_Synth_board.kicad_pcb]
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2026-03-22 Bug #18: Fix SPI CS init contention — init CS HIGH, deassert peers before assert
    MX_GPIO_Init() set all GPIOG outputs LOW in one batch, leaving both
    ADF4382A CS pins asserted from boot. When TX PLL was programmed first,
    RX SDO was also driving the shared MISO line (bus contention).
    - main.cpp: Separate CS pins from batch GPIO_PIN_RESET; init HIGH
    - stm32_spi.c: Add cs_peer_entry table (7 CS pins) and deassert_peer_cs()
    called before every CS assert; fix uint32_t -> uint16_t signature
    - ad_driver_mock.h: Add write_and_read/remove to no_os_spi_platform_ops
    - stm32_hal_mock.c: Make stm32_spi_ops weak for test overrides
    - New test: test_bug18_spi_cs_init_high.c (6 sub-tests, all pass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
    [main.cpp, stm32_spi.c]
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2026-03-23 Add freq synth board: schematic, gerbers, drills, BOM, DRC-fixed PCB
    Includes:
    - Restored schematic (.kicad_sch) from Eagle import history
    - Sub-schematic sheet (_1.kicad_sch)
    - Eagle import symbol library (.kicad_sym)
    - JLCPCB 6-layer gerber set (F/B/In1-4 Cu, masks, paste, silkscreen)
    - PTH + NPTH drill files with drill map PDF
    - JLCPCB BOM (.xls) and component placement (.csv)
    - Updated PCB with via clearance + upsize fixes (1508 -> 661 DRC violations)
    - Updated project file with JLCPCB design rules
    [Clocks_Freq_Synth_board-B_Cu.gbr, Clocks_Freq_Synth_board-B_Mask.gbr, Clocks_Freq_Synth_board-B_Paste.gbr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]
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2026-03-23 Repo cleanup: remove duplicate files, root fix scripts, update README paths
    Deleted (duplicates — identical MD5 copies exist elsewhere):
    - 8_Utils/Antenna_Array.jpg (dup of docs/assets/img/Antenna_Array.jpg)
    - 8_Utils/RADAR_V6.jpg (dup of docs/assets/img/RADAR_V6.jpg)
    - 8_Utils/RADAR_V6_V2.png (dup of 2_Functional Diagram/RADAR_V6_V2.png)
    - 8_Utils/Python/test_radar_data.csv (dup of 9_Firmware/9_3_GUI/test_radar_data.csv)
    - 7_Components Datasheets/AD9484/UG-290.pdf (dup of 6_Application Notes/UG-290.pdf)
    - 7_Components Datasheets/RO4000...Data Sheet (1).pdf (download dup of same without (1))
    Deleted (one-time PCB fix scripts with hardcoded paths — fixes already applied):
    - fix_annular.p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
    [test_radar_data.csv]
2026-03-23 Add GUI_radar_dashboard_v2: unified dashboard with all legacy GUI features
    New file: GUI_radar_dashboard_v2.py (870 lines)
    Merges best features from V1-V6 + V4_2_CSV + radar_dashboard into one unified dashboard:
    Ported from V2-V6:
    - Kalman filter tracking (DBSCAN clustering + 4-state KF, numpy-only, no filterpy dep)
    - Tracked target overlay on R-D map (orange circles)
    - Nearest-neighbor track association with stale track pruning
    Ported from V3-V6:
    - GPS/IMU pitch correction on elevation angles
    - GPSData dataclass with lat/lon/alt/pitch
    Ported from V4-V6:
    - Google Maps HTML overlay with radar position + target plotting
    - Map tab with manual GPS entry and browser launch
    Porte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
    [GUI_radar_dashboard_v2.py]
2026-03-24 Fix velocity sign flip in tracker: use fftshifted detection array
    Root cause: detections were extracted from the unshifted frame.detections
    array (bin 0 = DC) but velocity was computed using the fftshifted coordinate
    formula (bin 0 = -max_vel). This mapped DC targets to ±max_vel instead of
    ~0 m/s, causing abrupt sign flips in tracked velocity.
    Fix: move fftshift BEFORE detection extraction so bin indices match the
    shifted velocity axis. Also use bin-center offsets (+0.5) for both range
    and velocity, consistent with the CFAR scatter overlay.
    Verified with CN0566 replay data:
    Before: dbin=27..30 (unshifted) -> vel=+17..+22 m/s (WRONG)
    After: dbin=11..14 (shifted) -> vel=-7..-2 m/s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
    [GUI_radar_dashboard_v2.py]
2026-03-24 Fix tracker velocity flip: per-dimension clustering + SNR-weighted centroid
    Root cause: clustering used euclidean eps=50 which merged all detections
    at the same range regardless of velocity (48 detections at -24 to +24 m/s
    averaged to ~0, flipping sign on variations).
    - Per-dimension box thresholds (range_eps=20m, vel_eps=5m/s) instead
    of single euclidean eps — properly separates targets at same range
    but different velocities
    - Sort by SNR descending so strongest peaks seed clusters first
    - SNR-weighted centroid for velocity (strong peaks dominate)
    3x5 array data now produces 9 stable tracks (was 2 unstable):
    TID=0: 357.2m @ -10.22m/s (strongest, SNR=62724) — stabl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
    [GUI_radar_dashboard_v2.py]
2026-03-24 Fix velocity flip: per-dimension clustering + SNR-weighted centroid
    Root cause: euclidean eps=50 merged all detections at same range
    regardless of velocity, causing 48 detections (-24 to +24 m/s) to
    merge into one cluster with meaningless average velocity.
    - Per-dimension box thresholds (range_eps=20m, vel_eps=5m/s)
    - Sort by SNR descending so strongest peaks seed clusters
    - SNR-weighted centroid so strong peaks dominate velocity
    Result: 9 stable clusters instead of 2, zero velocity flipping.
    47/47 tests pass.
    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
    [GUI_radar_dashboard_v2.py]
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2026-03-24 Add UART communication for self-test readback over TE0701 FT2232H Channel B
    New modules:
    - uart_tx.v: parameterized 8N1 transmitter (configurable baud rate)
    - uart_rx.v: parameterized 8N1 receiver with double-sync and frame error detection
    - uart_self_test_reporter.v: formats 20-byte binary status packets from fpga_self_test
    Updated dev wrapper (radar_system_top_te0713_dev.v):
    - Power-on reset with auto self-test trigger on boot
    - UART command handler: 'T'=trigger test, 'S'=request status
    - Self-test result auto-reported over UART on completion
    Infrastructure:
    - Pin constraints for Bank 14: P16 (uart_rxd), U18 (uart_txd) LVCMOS33
    - build_te0713_dev.tcl updated with all UART source files
    -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
    [tb_uart_txrx.v, te0713_te0701_minimal.xdc, uart_self_test_reader.py]
2026-03-24 Fix Bank 14 VCCO conflict: clk_100m LVCMOS15 -> LVCMOS33 (U20 is Bank 14, 3.3V on TE0713)
    [te0713_te0701_minimal.xdc]
2026-03-24 Fix UART pin mapping: P16 -> P19 for uart_rxd (MIO14/B14_L24_P)
    Verified via 4x5_series_pinout_tracelength.xlsx that:
    - JB1-91 (MIO14) -> JM1-92 -> FPGA P19 (B14_L24_P), NOT P16
    - JB1-86 (MIO15) -> JM1-85 -> FPGA U18 (B14_L18_N) (was correct)
    Both nets are direct B2B-to-FPGA, NOT routed through TE0713 CPLD U3.
    [te0713_te0701_minimal.xdc]
2026-03-24 Swap UART TX/RX pin assignments: uart_txd->P19, uart_rxd->U18
    Testing hypothesis that MIO14(P19) is the FPGA TX direction
    and MIO15(U18) is the FPGA RX direction, opposite to our
    original interpretation of the TE0701 TRM naming convention.
    [te0713_te0701_minimal.xdc]
2026-03-24 Add UART TX blaster diagnostic and revert pin swap to original mapping
    - Revert UART pin swap: restore uart_rxd=P19, uart_txd=U18 per CPLD firmware docs
    - Add uart_tx_blaster.v: continuous TX pattern (0x55/0xAA/0x0F/0xF0) for UART debug
    - Add uart_tx_blaster_top.v: minimal top driving BOTH P19 and U18 as outputs
    - Add te0713_blaster.xdc: constraints with both candidate pins as outputs
    - Add build_te0713_blaster.tcl: Vivado batch build script for blaster bitstream
    - Add tb_uart_tx_blaster.v: testbench (10/10 pass)
    - Update run_regression.sh: include blaster test in Phase 1
    [te0713_blaster.xdc, te0713_te0701_minimal.xdc]
2026-03-24 Add VIO debug core for JTAG self-test readback, bypassing broken UART/CPLD path
    New files:
    - radar_system_top_te0713_vio.v: VIO-based dev wrapper with 7 input probes
    (result_flags, detail, busy, all_pass, heartbeat, version, done) and
    2 output probes (trigger, status request) for Vivado hardware manager
    - constraints/te0713_vio.xdc: minimal constraints without UART pins
    - scripts/build_te0713_vio.tcl: Vivado batch build with VIO IP generation
    - scripts/read_vio_selftest.tcl: programs FPGA and reads self-test via JTAG
    - tb/tb_radar_system_top_te0713_vio.v: 23/23 tests pass (iverilog)
    Updated:
    - run_regression.sh: added VIO test and module to lint list
    [tb_radar_system_top_te0713_vio.v, te0713_vio.xdc]
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2026-03-25 Fix Python opcode map to match RTL host register decode
    The Opcode enum in radar_protocol.py was a legacy mapping that predated
    the RTL register rework. Key corrections:
    - TRIGGER: 0x01 → 0x02 (0x01 is now RADAR_MODE)
    - THRESHOLD: 0x10 → 0x03
    - STREAM_CONTROL: 0x05 → 0x04 (renamed from STREAM_ENABLE)
    - GAIN_SHIFT: 0x06 → 0x16
    - Added RADAR_MODE = 0x01
    - Removed stale PRF_DIV, NUM_CHIRPS, CHIRP_TIMER aliases
    Updated dashboard button opcodes and parameter panel opcodes in both
    radar_dashboard.py and GUI_radar_dashboard_v2.py. Updated test assertions
    to match (67/67 logic tests pass, 3 tkinter env + 1 h5py pre-existing).
    [GUI_radar_dashboard_v2.py, radar_dashboard.py, radar_protocol.py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]
2026-03-25 Add GO/SO CFAR mode dropdown, parameter validation, and fix tkinter test deps
    V2 dashboard enhancements:
    - Replace CFAR Mode numeric entry with CA/GO/SO dropdown (ttk.Combobox)
    - Add _send_validated_param() with RTL-accurate range clamping for all params
    - Add CFAR mode indicator in status bar
    Shared constants extracted to radar_protocol.py (tkinter-free):
    - CFAR_MODE_NAMES, CFAR_MODE_VALUES, PARAM_VALIDATION, AERIS10_CONFIG
    - Both dashboards (V1, V2) now reference the single source of truth
    Test coverage (86 tests, 85 pass, 1 h5py skip):
    - 6 new GO/SO CFAR replay tests (exact counts: CA=5, GO=13, SO=44)
    - 9 new parameter validation tests
    - Fix 3 AERIS-10 axis tests: import AERIS10_CONFIG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
    [GUI_radar_dashboard_v2.py, radar_dashboard.py, radar_protocol.py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]
2026-03-27 FPGA v7c USB streaming pipeline + GUI dashboard + protocol layer + tests
    FT601 245-mode streaming fully working end-to-end on live hardware:
    - usb_data_interface.v v7c: fixed SEND_STATUS retrigger bug (pending+busy
    flags), all-1111 BE, post-POR lockout, debug counters
    - radar_system_top dev wrapper: FT601 XDC pullups, constant-HIGH chip reset
    - ad9484_interface_400m.v: SIMULATION ifdef guards for IBUFDS/BUFIO/IDDR
    - Testbench: 44/44 pass including retrigger prevention (Phase 12)
    - radar_protocol.py: raw ctypes D3XX API, v7c 24-byte data + 40-byte status
    packet parsing, range-only RadarAcquisition mode, cross-read residual buffer
    - GUI_radar_dashboard_v2.py: range_only mode, auto-connect,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
    [GUI_radar_dashboard_v2.py, ad9484_interface_400m.v, diag_ft601.py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]
2026-03-27 KiCad FPGA swap schematic wiring + MCU scan scheduler fix
    Manual KiCad work: FPGA swap from XC7A100T to XC7A200T on MainBoard
    schematic — rewiring U42 connections, ERC fixes, power rail updates,
    PCB footprint swap. Includes backup files and automation scripts.
    MCU: scan scheduler contract test + main.cpp updates.
    [RADAR_Main_Board_1.kicad_sch, RADAR_Main_Board_2.kicad_sch, RADAR_Main_Board_3.kicad_sch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]
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2026-03-28 FPGA v8c: BRAM playback pipeline with 2048-entry FIFO + USB pipe init fix
    - Add unified playback wrapper (radar_system_top_te0713_umft601x_playback.v)
    with BRAM->DSP->USB pipeline, 2048-entry range FIFO, and 3-state
    handshake pop FSM for lossless data delivery to FT601
    - Add write_idle output to usb_data_interface.v with fsm_encoding=none
    attributes to prevent Vivado FSM inference bugs
    - Add _init_pipes() to radar_protocol.py and ft601_stream_server.py:
    ClearStreamPipe+SetStreamPipe sequence fixes D3XX read timeouts after
    FPGA reprogramming or USB reconnects
    - Add Vivado build script, programming script, and 54-test testbench
    - KiCad main board schematic wiring progress
    - Verified: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
    [RADAR_Main_Board_2.kicad_sch, RADAR_Main_Board_3.kicad_sch]
2026-03-28 FPGA v9c: Doppler + CFAR streaming over USB with alpha calibration fix
    v9 adds independent Doppler (0xCC) and CFAR detection (0xDD) packet
    streams alongside range (0xAA), each with its own FIFO and pop FSM.
    CFAR FSM state encoding fixed (sequential, fsm_encoding=none), debug
    counters added (cells_processed, cols_completed, valid_count).
    Key fix: default CFAR alpha changed from 0x30 (3.0, giving 48x avg
    threshold) to 0x05 (0.3125, giving 5x avg threshold). Hardware alpha
    sweep confirmed 232 detections at 0x03 down to 5 at 0x30.
    Hardware-verified: 2048 range + 2047 Doppler + 112 CFAR packets via
    FT601 USB 3.0. End-to-end TCP bridge test passes. Regression: 75/75
    playback, 24/24 CFAR, 7/7 res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
    [GUI_radar_dashboard_v2.py, diag_v8b_throughput.py, diagnostic_v8b.py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]
2026-03-28 GUI: fix v9 frame assembly, add continuous playback mode
    - Fix frame 0 loss: init _got_doppler=True in v9 mode so first range
    packet batch routes correctly to _ingest_v9_range() instead of legacy
    _ingest_sample() handler
    - Fix deferred CFAR finalization: delay frame seal after Doppler complete
    to collect CFAR detection packets (lower priority in FPGA arbiter)
    - Fix playback counter: 1 frame per trigger in v9 mode (not 32)
    - Add continuous playback toggle: auto-retriggers 0x02 after each frame
    completes, filling the waterfall while keeping all controls active
    - Update 4 v9 unit tests for deferred finalization behavior
    [GUI_radar_dashboard_v2.py, radar_protocol.py, test_radar_protocol_v7c.py]
2026-03-28 FPGA v9d: fix Pop FSM pending flag races + USB drain timing
    - Add !usb_X_pending guards to all 3 Pop FSMs (prevents pop-while-pending)
    - Add disabled-stream discard logic in USB FSM IDLE state (prevents deadlock)
    - Add per-type RTL debug counters (consumed/discarded/pending_sets)
    - Fix TB drain timing: wait_ft_clk(20) after FIFO empty before counting
    - Add exact 2048 Doppler count assertion + handshake race checks
    - Clean up verbose debug instrumentation from off-by-one investigation
    [tb_radar_system_top_te0713_umft601x_playback.v]
2026-03-28 TB: rewrite tb_usb_data_interface.v for v9 architecture (119/119 pass)
    Complete rewrite of the USB module isolation testbench for the v9d
    4-bit FSM architecture with independent packet types (range/doppler/cfar).
    Key changes:
    - Continuous write monitor replaces sequential capture_packet task
    - wait_packet_done task avoids NBA race (phase 1: leave IDLE, phase 2: return)
    - Mid-cycle (#2) stimulus timing for status_request edge detection
    - 23 test groups covering all v9 packet formats, priority arbiter,
    disabled-stream discard, pending flag exports, backpressure,
    read/write interleave, status readback, debug counters, startup lockout
    - All 119 tests passing, full regression clean (81+24+7+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
    [tb_usb_data_interface.v]

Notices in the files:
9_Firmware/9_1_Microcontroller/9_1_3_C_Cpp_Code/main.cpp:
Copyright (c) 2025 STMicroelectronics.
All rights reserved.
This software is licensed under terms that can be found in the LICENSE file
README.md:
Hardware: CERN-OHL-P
